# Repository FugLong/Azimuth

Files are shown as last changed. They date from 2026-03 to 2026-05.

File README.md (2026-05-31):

<div align="center">

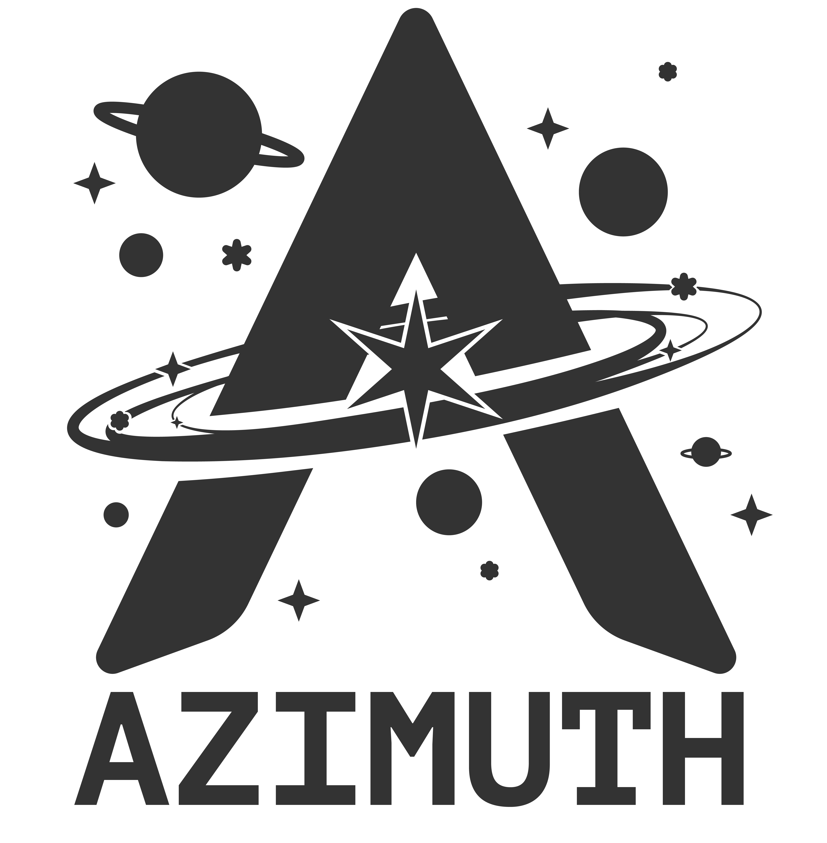
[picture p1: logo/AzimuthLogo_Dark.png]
Azimuth

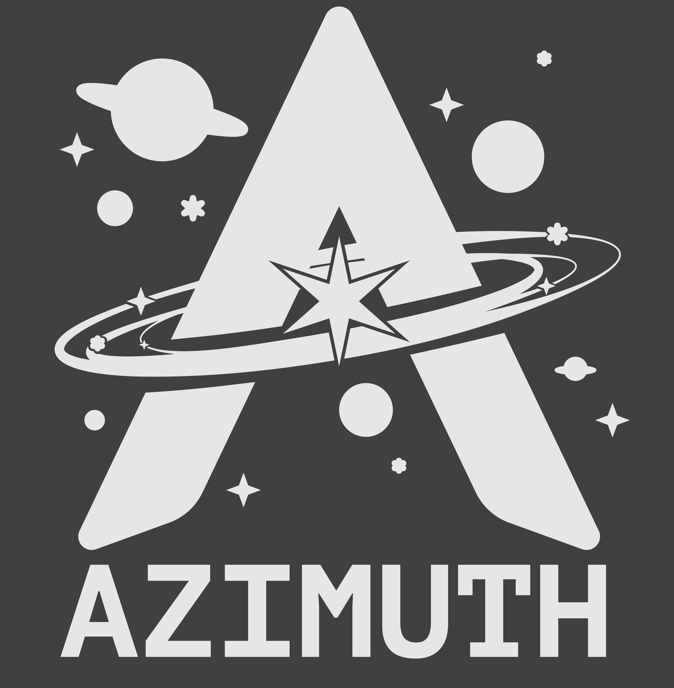
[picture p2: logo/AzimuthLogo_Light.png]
Azimuth


</div>

# Azimuth

Azimuth is a **DIY head tracker** for flight sims, racing, and anything that works with [OpenTrack](https://github.com/opentrack/opentrack). It pairs a small **ESP32** board with a **BNO08x-class** IMU so you get stable orientation without a closed commercial device. This repo has **firmware**, **PCB** designs, **3D** plans, and **documentation**—build it, change it, or fix it yourself.

### Hardware paths

Two supported builds—same core tracker firmware where both apply; use the row that matches what you assembled.

| Path | What it is | Status |
|---|---|---|
| **DIY (XIAO + BNO08x)** | **Seeed XIAO ESP32-C3** + **BNO08x** breakout on **SPI** — breadboard or hand-wired. Default **`azimuth_main_diy`**; selected by default in the [**web flasher**](https://fuglong.github.io/Azimuth/). | **Ready** — tracking, Wi‑Fi, portal, USB Hatire, OpenTrack UDP. |
| **Integrated PCB** | [**`kicad/Azimuth_Design`**](kicad/Azimuth_Design/): **ESP32-C3** module, **BNO086**, RGB, buzzer, button. **`azimuth_main_pcb`**; available in the web flasher hardware selector. | **V0.1** — KiCad **ERC/DRC** clean; **assembled boards in hand**, **bring-up and testing in progress**. Same app as DIY — [roadmap](docs/roadmap.md). |

[**docs/wiring.md**](docs/wiring.md) (pinouts) · [**docs/hardware-profiles.md**](docs/hardware-profiles.md) (PlatformIO / GPIO) · [**docs/parts-list.md**](docs/parts-list.md) (sourcing — DIY store links + PCB BOM)

---

### Get started

| | |
|:---|:---|
| **Install or update firmware (USB)** | [**Web flasher**](https://fuglong.github.io/Azimuth/) (**Chrome** / **Edge**). **First flash on a bare custom PCB?** [**Copy/paste USB guide**](docs/first-usb-flash.md) (one time; web/OTA after that). |
| **Update firmware over Wi‑Fi** | Open the portal, hit **Install over Wi‑Fi** in the **Device** card or update banner — *or* hold **FUNC** for ~2 s on the PCB. The chip pulls the latest **official** build from the same GitHub Pages release URL (HTTPS) and reboots into the standby OTA slot. See [**User Guide → Updates**](docs/user-guide.md#9-firmware-updates). |
| **Settings (Wi‑Fi, OpenTrack, device)** | [**http://azimuth.local:8080**](http://azimuth.local:8080) — only after the board is on your home network. First time? Connect to **Azimuth-Tracker** (**Offline Mode**) and follow the [**quick start**](docs/quickstart.md). |
| **Manual (how to use the device)** | [**docs/user-guide.md**](docs/user-guide.md) |
| **Short Wi‑Fi → OpenTrack path** | [**docs/quickstart.md**](docs/quickstart.md) |

---

<div align="center">
<table>
  <tr>
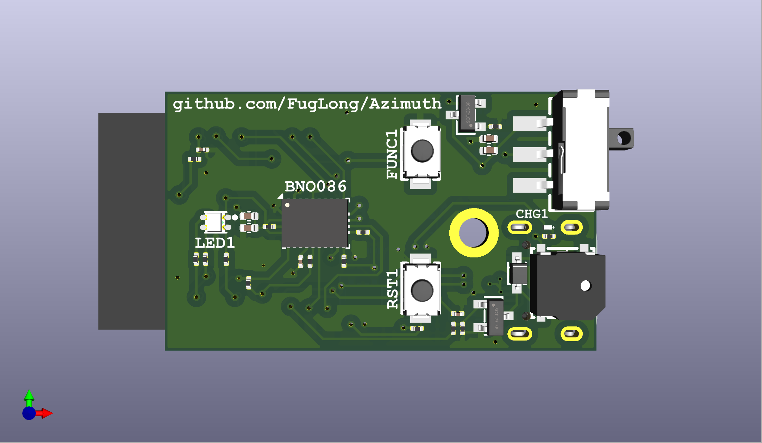
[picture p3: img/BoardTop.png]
PCB top
    <td align="center"></td>
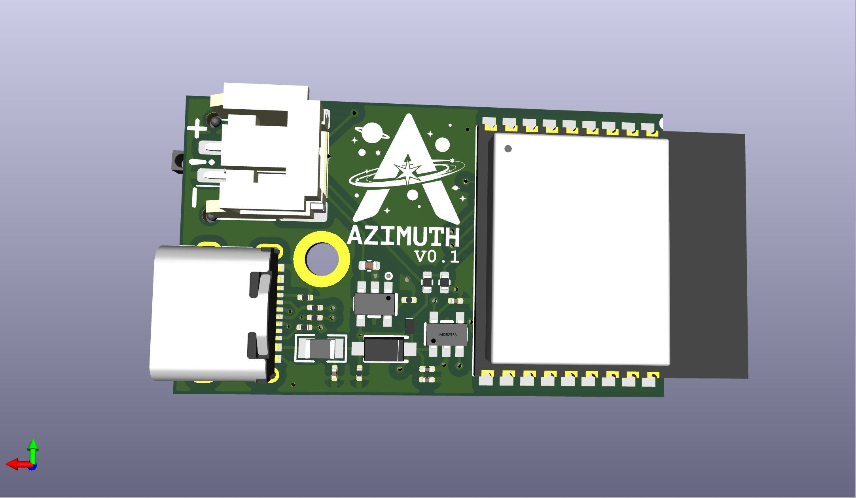
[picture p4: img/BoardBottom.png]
PCB bottom
    <td align="center"></td>
  </tr>
</table>
</div>

## Overview

- **OpenTrack-first** — Send motion over **Wi‑Fi (UDP)** or **USB (Hatire)**; configure most things in the on-device web UI.
- **Affordable, open stack** — Sensible parts list, KiCad project, and firmware you can build with [PlatformIO](https://platformio.org/).
- **No cloud** — No account or hosted service; setup and tracking stay on your network.
- **Successor** to [Nano33_PC_Head_Tracker](https://github.com/FugLong/Nano33_PC_Head_Tracker): same DIY spirit, but rebuilt around **ESP32** and an external fusion IMU for better results than the old Nano 33 BLE + LSM9DS1 path.

## Need to know

- **Flashing** — Browser install needs **Chrome** or **Edge** (Web Serial). If the installer offers **erase flash**, use it for a clean device (same effect as a full settings reset).
- **First Wi‑Fi setup** — Join **Azimuth-Tracker** (**Offline Mode**), open **`http://192.168.4.1`**, save your home network. Details: [**quick start**](docs/quickstart.md) · full walkthrough: [**User Guide**](docs/user-guide.md).
- **OpenTrack** — Use **either** UDP **or** Hatire as the input, not both at once. Defaults and axis mapping: [**Using Azimuth**](docs/using-azimuth.md#opentrack-on-the-pc).
- **Power, heat, tuning** — Normal for Wi‑Fi on a small module; portal **Tracking & radio** settings; full behavior + battery notes: [**Power, heat, and battery (firmware)**](docs/power-and-thermal.md).

## Documentation

| Doc | Audience |
|-----|---|
| [**User Guide**](docs/user-guide.md) | **Manual** — Wi‑Fi, portal, FUNC, OpenTrack, updates, battery, troubleshooting |
| [**Quick start**](docs/quickstart.md) | Fast path from flash to tracking over Wi‑Fi |
| [**Using Azimuth**](docs/using-azimuth.md) | Settings portal reference, OpenTrack (USB + Wi‑Fi), tips |
| [**Power, heat, and battery (firmware)**](docs/power-and-thermal.md) | Wi‑Fi power saving, portal polling, defaults; battery runtime / PCB pack polarity |
| [**Development**](docs/development.md) | Building firmware, CI, versioning, repo layout |
| [**Firmware architecture plan**](docs/firmware-architecture-plan.md) | Maintainers — module layout (**network split done**), CI, remaining refactors |
| [**I/O experience plan**](docs/io-led-buzzer-plan.md) | LED / buzzer / FUNC — pause/stasis, layered overrides, **wireless OTA** |
| [**Implementation handoff**](docs/implementation-handoff-prompt.md) | Copy-paste prompt + ordered tasks for agents / new contributors |
| [**Wiring**](docs/wiring.md) · [**Hardware profiles**](docs/hardware-profiles.md) · [**Parts / BOM**](docs/parts-list.md) · [**KiCad**](docs/kicad.md) | Pinouts (DIY + PCB), PlatformIO, BOM, KiCad |
| [**Roadmap**](docs/roadmap.md) | Progress, milestones, future work |
| [**Enclosure (Onshape CAD)**](https://cad.onshape.com/documents/fa78666ff0e219ba32d45d9f/w/679625cc5ba48f8e098cba83/e/0cd4f9cad8e872128d491b46) | Interactive 3D model — print/fit validation still in progress ([roadmap](docs/roadmap.md)) |

## Goals

- **Performance** — Low latency and stable orientation for games and desktop use.
- **Accessibility** — Easy-to-source parts and open tooling so people can build and modify their own trackers.
- **Interop** — First-class support for the same **OpenTrack** pipelines games and sims already use.
- **Evolvability** — Room for better calibration, on-device UX, and companion apps without legacy platform limits.

## Progress (toward V1)

| Area | Progress | Notes |
|---|:---:|---|
| Hardware / BOM | 100% | [Parts list](docs/parts-list.md) |
| Azimuth custom PCB ([`Azimuth_Design`](kicad/Azimuth_Design/)) — **V0.1** | **100%** (layout) · **units received** | Assembled boards **under test**. RGB / buzzer / FUNC in firmware for bring-up — see [wiring](docs/wiring.md) / [parts-list](docs/parts-list.md) — [roadmap](docs/roadmap.md) |
| Firmware | ~90% | Tracking + Wi‑Fi + portal + Hatire + **wireless OTA** + modular **`track_network_*`**; **battery ADC** polish and optional **`main`** layering remain — [roadmap](docs/roadmap.md) |
| 3D enclosure | ~90%+ | **Design nearly complete** — [**Onshape CAD (interactive)**](https://cad.onshape.com/documents/fa78666ff0e219ba32d45d9f/w/679625cc5ba48f8e098cba83/e/0cd4f9cad8e872128d491b46); print / fit validation still ahead |

```
Hardware/BOM   [████████████████████] 100%
PCB (V0.1)     [████████████████████] 100% design · boards received · testing
Firmware       [██████████████████░░] ~90%
Enclosure      [██████████████████░░] ~90%+ (design)
```

**Detailed roadmap:** [docs/roadmap.md](docs/roadmap.md)

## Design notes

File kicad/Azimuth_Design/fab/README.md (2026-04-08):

# Fab exports (Azimuth_Design)

## PCBWay-style “Other Parameters” (copy-paste)

| Form field | Value |
|---|---|
| **Unique Parts** | **33** |
| **SMD Parts** (tooltip *SMT Pads*) | **52** (SMD placements) **or** **234** (SMD pads in PCB — use if the estimator expects pad count) |
| **BGA/QFP Parts** | **0** |
| **Through-Hole Parts** | **0** |

**Not a contradiction:** **33** = distinct **part numbers** (unique SKUs to order). **52** = **placement count** — each symbol on the board is one placement, but many symbols share the same LCSC (many resistors/caps reuse a few codes). **234** = physical **SMD pads** on the PCB (pads per footprint), only if a form asks for pad count.

**Unique parts:** 32 distinct **LCSC Part** values on stuffed BOM lines + **IC1** (no LCSC on symbol) = **33**. **SMD placements:** **52** stuffed lines. **SMD pads:** **234** × `pad … smd …` in **`Azimuth.kicad_pcb`**. **IC1** is **LGA**, not BGA/QFP.

---

## `Azimuth_bom.csv`

Machine-generated **Bill of Materials** from **`../Azimuth.kicad_sch`** using **KiCad’s `kicad-cli sch export bom`** (same field stack the GUI BOM tool uses). The same script also writes **`Azimuth.net`** via **`kicad-cli sch export netlist`**. **Commit updates** whenever the schematic BOM-relevant fields change so docs can cite a real file instead of hand-wavy counts.

Regenerate from the repo root:

```bash
./scripts/export_azimuth_bom.sh
```

Or set `KICAD_CLI` if `kicad-cli` is not on your `PATH` (see script).

### Numbers taken from the committed CSV (for assembly forms)

These are derived from **`Azimuth_bom.csv`** as checked in — re-open the CSV after regeneration if the design changed.

| Question | Answer |
|---|---|
| BOM lines (`kicad-cli`, one row per schematic symbol) | **52** |
| Rows with `Value` = `DNP` | **0** |
| Rows for a **stuffed** build | **52** |
| Distinct **LCSC Part** codes on stuffed lines (non-empty) | **32** |
| Distinct **ordering lines** if you treat “no LCSC” as its own line (**IC1** / BNO086 has no LCSC on the symbol) | **33** |
| Through-hole **components** | **0** (all stuffed lines are SMD footprints) |
| BGA / QFP | **0** — **IC1** is **LGA** |

**PCBWay:** their KiCad plugin often writes under **`_pcbway_export_review/`** (gitignored here). If you use their CSV for an order, copy or regenerate into this **`fab/`** folder when you want those exact columns tracked in git.

## `Azimuth_bom_cost.txt`

**One-board parts-only USD estimate** (unit prices × qty). Written by **`./scripts/export_azimuth_bom.sh`** after the BOM CSV export. Uses **`Unit Price (USD)`** from the schematic when present; otherwise fills from the same LCSC/MPN table as **`scripts/update_azimuth_sch_bom_fields.py`**. **Not** live pricing, **not** PCB fab or shipping.

## `Azimuth.net` (optional)

Regenerate after schematic changes if you track a netlist export here.

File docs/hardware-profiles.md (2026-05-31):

# Hardware profiles

Azimuth is intentionally **two hardware paths**—you only build one:

1. **DIY / breadboard** — A **Seeed XIAO ESP32-C3** and a **BNO08x-class** IMU breakout wired for **SPI**. Parts are easy to source — store links and options are in [**parts-list.md**](parts-list.md). The [**web flasher**](https://fuglong.github.io/Azimuth/) supports this path and keeps it as the default choice (**`azimuth_main_diy`**). USB for flashing and **Hatire** is through the XIAO.

2. **Integrated PCB** — The routed board in [**`kicad/Azimuth_Design`**](https://github.com/FugLong/Azimuth/tree/main/kicad/Azimuth_Design) (**ESP32-C3-WROOM-02**, **BNO086** on the board, plus **RGB**, **buzzer**, and **FUNC** where populated). You flash **`azimuth_main_pcb`**. It runs the **same** head-tracking application (portal, UDP, Hatire); on-board extras are only relevant when that hardware exists.

**DIY** (XIAO + breakout) and **Azimuth_Design** share the **same** GPIO assignments in **`include/azimuth_hw.h`** — only the **physical** connector differs (XIAO **D** pins vs **U1** module pads). See [**wiring.md**](wiring.md) (DIY table ↔ PCB table).

**Build suffixes:** **`_diy`** = XIAO + breakout. **`_pcb`** = Azimuth_Design. **`main`** = full firmware (portal, Hatire, UDP). **`debug`** = USB serial IMU angles only, no Wi‑Fi or portal.

Firmware now also tags each build with a board profile (`DIY` or `PCB`) and enables features through a shared capability layer. That keeps one app codebase while cleanly gating optional hardware (RGB, buzzer, FUNC button, battery sense) per path.

---

## Targets

| Role | **`_diy`** | **`_pcb`** |
|---|---|---|
| **MCU** | XIAO ESP32-C3 | WROOM-class module on Azimuth_Design |
| **IMU** | BNO08x breakout | BNO086 on board |
| **Extra I/O** | Buzzer/button optional (same GPIOs as PCB) | RGB LED, buzzer, FUNC on board |

Capability defaults in current firmware:

| Capability | **`_diy`** | **`_pcb`** |
|---|---|---|
| RGB LED | Off (no RGB layout expected) | On |
| Buzzer | On (optional wiring) | On |
| FUNC button | On (optional wiring) | On |
| Battery sense | Stubbed in firmware for now | Stubbed in firmware for now |

On **`_pcb`**, firmware treats the RGB as **common anode** (see [**wiring.md**](wiring.md)) and applies simple **per-channel PWM scaling** from ballast **R6–R8** so logical RGB is closer to matched drive. **`_diy`** does not use the Azimuth RGB footprint; optional buzzer/button GPIOs match the PCB when wired.

**Firmware:** **`azimuth_main_diy`** and **`azimuth_main_pcb`** are the same application. Tracking does not require LED, buzzer, or button.

| You have | Environment |
|---|---|
| XIAO + BNO08x (SPI) | **`azimuth_main_diy`** or **`azimuth_debug_diy`** — `board = seeed_xiao_esp32c3` |
| Azimuth_Design PCB | **`azimuth_main_pcb`** or **`azimuth_debug_pcb`** — `board = esp32-c3-devkitc-02` |

```bash
python3 -m platformio run -e azimuth_main_diy -t upload    # XIAO + breakout
python3 -m platformio run -e azimuth_main_pcb -t upload    # Azimuth_Design
```

Firmware sets **`-DARDUINO_USB_MODE=1`** and **`-DARDUINO_USB_CDC_ON_BOOT=1`** so **`Serial`** is USB CDC on both targets; the stock **`esp32-c3-devkitc-02`** JSON does not enable that by itself.

**SPI bus:** **`src/main.cpp`** calls **`SPI.begin(8, 9, 10, -1)`** before **`imu.beginSPI(...)`**. The XIAO variant already defaults to those pins, but **`esp32-c3-devkitc-02`** uses Arduino variant **`esp32c3`**, whose defaults are **4 / 5 / 6** — that would collide with **CS (5)** and **INT (6)** on the Azimuth PCB. The explicit **`begin`** keeps DIY and PCB builds on the same **FSPI** pins as **`Azimuth.kicad_sch`**.

**Web flasher:** CI publishes both **`azimuth_main_diy`** and **`azimuth_main_pcb`** with a hardware selector in the installer UI. DIY remains the default selection.

**First flash on a bare custom PCB (no firmware from the factory):** the module boot-loops; the browser [**web flasher**](https://fuglong.github.io/Azimuth/) is unreliable for that one-time case. Use [**first-usb-flash.md**](first-usb-flash.md), then web or OTA for updates afterward.

---

## GPIO contract (change only with firmware + doc update)

Firmware-facing summary: same GPIO numbers on both paths. **Where to wire physically** — XIAO **D** pins vs **U1** schematic pins — is in [**wiring.md**](wiring.md) (DIY section vs PCB section), not duplicated here.

GPIO numbers are for ESP32-C3; **D*** labels refer to XIAO silk only (the module has no **D** names).

| Function | GPIO | XIAO | Notes |
|---|---|---|---|
| SPI SCK / MISO / MOSI | 8 / 9 / 10 | D8–D10 | |
| IMU CS / INT / NRST | 5 / 6 / 20 | D3, D4, D7 | |
| PS0 / WAKE | 2 | D0 | **10 kΩ** to **3V3** on breadboard (same as **R14** on **Azimuth_Design**) |
| RGB (Azimuth board) | 0, 1, 3 | — | Not present on default breadboard build; **R→IO1, G→IO0, B→IO3** — [wiring.md](wiring.md) |
| Status / future | 3 | D1 | **`kPinStatusLed`**; shares **IO3** with RGB blue on PCB — [wiring.md](wiring.md) |
| FUNC | 7 | D5 | Optional breadboard |
| Buzzer | 21 | D6 | PWM on **IO21** drives **Q2** gate on PCB; optional breadboard differs — [wiring.md](wiring.md), [parts-list](parts-list.md#buzzer-buzzer1) |
| Battery sense | 4 | D2 | Divider tap; when populated — same as **Azimuth_Design** **IO4** |

The Azimuth RGB LED is on **GPIO 0, 1, 3**—not a drop-in on XIAO silk; **`azimuth_main_diy`** does not drive that RGB layout.

If a hardware revision ever changes GPIO roles, update **`azimuth_hw.h`** and [wiring.md](wiring.md) together.

**KiCad:** **`kicad/Azimuth_Design/`** — open **`Azimuth.kicad_pro`**. **U1** ↔ **IC1** routing and module notes are in [wiring.md](wiring.md) (**PCB path**). Project snapshot is **ERC/DRC clean**; re-run after schematic or layout edits. Libraries, optional panelization, workflow: [kicad.md](kicad.md).

---

## Work checklist (maintenance)

- [x] Shared pin header **`include/azimuth_hw.h`**
- [x] PlatformIO **`azimuth_main_diy`** / **`azimuth_main_pcb`** (+ debug variants)
- [x] **Azimuth_Design**: Docs [**parts-list.md**](parts-list.md) / [**wiring.md**](wiring.md) match **`Azimuth.kicad_sch`** / **`Azimuth.kicad_pcb`** (re-verify after edits); **ERC/DRC clean** in current repo snapshot; export BOM from KiCad for each fab / pick-and-place order
- [x] CI build **`azimuth_main_pcb`** artifacts
- [x] Web flasher hardware selector (DIY + PCB manifests)

**Related:** [wiring.md](wiring.md) · [parts-list.md](parts-list.md) · [development.md](development.md) · [kicad.md](kicad.md)

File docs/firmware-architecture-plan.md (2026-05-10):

# Firmware architecture — review and improvement plan

This document captures how Azimuth firmware is structured today, what is working well, where complexity concentrates, and a **phased plan** for refactors so the codebase stays maintainable as features grow (especially richer I/O and networking).

It is a planning artifact: implement in small PR-sized steps rather than as one large rewrite. **As of 2026‑05:** core networking has been split into multiple translation units (Phase B done); remaining items skew toward **battery ADC polish**, **main.cpp decomposition**, and optional **portal asset pipeline** improvements.

---

## Current strengths

- **Bounded real-time path.** `main.cpp` owns IMU sampling and pose output; networking is invoked from `trackNetworkLoop()` and stays out of the hottest path except where intentional (UDP send immediately after rotation-vector reports).
- **Build dimensions are explicit.** `IMU_DEBUG_MODE` separates a bare serial build from full firmware. PlatformIO environments distinguish DIY vs PCB (`AZIMUTH_BOARD_*`) so hardware differences stay mostly in `board_config` / `azimuth_hw`.
- **Subsystem boundaries.** Battery, thermal, LED, buzzer, button, and network each live in dedicated translation units with namespaces (`azimuth_battery`, `azimuth_thermal`, `azimuth_io_*`, etc.).
- **Thin API toward the loop.** `track_network.h` exposes a small surface (`trackNetworkInit`, `Loop`, UDP send, prefs accessors, thermal emergency hook). Implementation is split across `track_network_{wifi,http,prefs,udp}.cpp` plus shared `track_network_internal.h`; `track_network.cpp` holds the façade and global runtime object.
- **Shipping discipline.** CI builds release artifacts; `secrets.h.example` covers optional compile-time Wi‑Fi without committing secrets; docs (`docs/development.md`, wiring, thermal) match how people actually flash and configure hardware.

---

## Pressure points (technical debt)

### 1. ~~`track_network.cpp` monolith~~ → split complete

Previously one large file mixed Wi‑Fi STA/AP, captive DNS, HTTP routes, NVS, OpenTrack, UDP, and update checks.

**Now:** Logical slices live in dedicated files behind the same public API:

| File | Role |
|---|---|
| `track_network.cpp` | Public wrappers; `NetworkRuntime` / `gRuntime` definition |
| `track_network_internal.h` | Shared structs, prefs/network helpers, declarations |
| `track_network_wifi.cpp` | STA/AP bring-up, `networkLoop`, thermal cut, offline portal, manifest scheduling |
| `track_network_http.cpp` | HTTP handlers, JSON API, TLS manifest fetch, `registerRoutes` |
| `track_network_prefs.cpp` | NVS merge helpers, adaptive modem sleep, stasis |
| `track_network_udp.cpp` | Host resolution, UDP socket, OpenTrack send |

### 2. Embedded portal asset (`portal_html.cpp`)

The portal is a large HTML/CSS/JS blob in PROGMEM. That is normal for a single-binary deliverable, but diffs are noisy and editing error-prone.

**Optional later improvement:** Build-time concatenation or minification from `portal/` fragments (`scripts/portal_codegen.py` already regenerates from `web/`). Not urgent until portal churn grows.

### 3. CI breadth

GitLab CI builds **`azimuth_main_diy`** (artifacts), **`azimuth_main_pcb`** (compile), **`azimuth_debug_diy`**, and runs **`scripts/run_host_tests.sh`**. Debug PCB env can still be built locally if needed.

### 4. Automated verification

**Host-side tests:** `scripts/run_host_tests.sh` compiles and runs native harnesses for config validation, config planning (Wi‑Fi / OpenTrack apply rules), and semver parsing (`tests/*.cpp`). Outputs land under `.tmp-host-tests/` (ignored by git).

**Recommendation:** When adding pure logic (e.g. more helpers split from networking), extend those harnesses or add a small new test file rather than relying on hardware-only checks.

### 5. `main.cpp` battery threshold ladder

Multiple similar latch variables work but are repetitive; a **table-driven** approach (threshold + severity + callback id) would shrink duplication and reduce mistakes when tuning percentages.

---

## Phased refactor roadmap

Phases are intentionally ordered by **risk vs payoff**. Structural network split is **complete**.

### Phase A — Guardrails (low risk)

1. **CI:** ✅ Builds **DIY + PCB** main and debug targets plus host tests on pipeline runs.
2. **Documentation:** Keep `docs/development.md` pointed at this file or a short “architecture” index.

### Phase B — Structural splits (medium risk, high readability)

1. ✅ Split networking along Wi‑Fi / HTTP / prefs / UDP slices; **preserve public `track_network.h` API**.
2. Optionally introduce a tiny **`network_prefs`** or **`settings_store`** module if NVS access spreads further — partially satisfied by `track_network_prefs.cpp`.

### Phase C — Quality-of-life (ongoing)

1. Table-driven battery alerts in `main.cpp` (or `battery_monitor` policy module).
2. Optional portal asset pipeline when editing HTML becomes painful.

---

## Cross-cutting product behaviors (see I/O plan)

- **Pause / stasis (FUNC single tap):** Runtime gate for UDP (and Hatire) separate from NVS `udp_on`, plus power-policy hooks (modem sleep in stasis). Implemented via `trackNetworkSetStasis` / `trackNetworkStasisActive`.
- **Wireless OTA *(shipped)*:** **`src/track_update.{h,cpp}`** (IMU debug builds get stubs). Uses the **default partition table's existing `ota_0` / `ota_1` / `otadata`** slots. Driven by `io_button` long-press *and* `POST /api/update`; cooperative chunk pump runs from `networkLoop`. TLS root pin is shared with the manifest check via `azimuth_net::releaseRootCaCert()`. USB flashing and the per-boot manifest version banner remain recovery and discovery fallbacks.

---

## Principles for future changes

- **Prefer extension over explosion.** New transports or APIs should attach via clear interfaces rather than growing anonymous globals.
- **Keep latency-sensitive code dumb.** Pose → USB/UDP should stay predictable; heavy work stays in `networkLoop` / lower priority paths with `yield()` where needed.
- **One source of truth for user-visible defaults.** NVS keys and portal defaults should stay aligned (already a discipline in config POST handlers).

---

## Non-goals (for this architecture track)

- Rewriting the Arduino/Wi‑Fi stack or replacing JSON with another format without user-facing need.
- Mandating a full RTOS migration; the current cooperative loop matches the product.

---

## Related documents

- **I/O and UX plan (LED, buzzer, FUNC, pause, OTA roadmap):** [io-led-buzzer-plan.md](io-led-buzzer-plan.md)
- **Implementation handoff (ordered tasks for agents):** [implementation-handoff-prompt.md](implementation-handoff-prompt.md)
- **Development workflow:** [development.md](development.md)

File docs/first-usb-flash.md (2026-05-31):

# First-time USB flash (copy & paste)

Use this guide when you need to put Azimuth firmware on the board over **USB** using our flash script.

**You need this if:** your **custom Azimuth PCB** came from assembly with **no firmware** (the web browser flasher usually will not work until after this one-time flash). You can also use it for **DIY (XIAO + breakout)** anytime.

**After this works once:** use the normal [**web flasher**](https://fuglong.github.io/Azimuth/) or **Wi‑Fi updates** in the portal — you do not need this script every time.

---

## Before you start

Check all of these:

| | |
|---|---|
| ☐ | **Data USB cable** (charges phones *and* transfers data — not charge-only) |
| ☐ | **Computer** (Mac or Windows; Linux works too — same commands as Mac) |
| ☐ | **Python 3** installed ([python.org/downloads](https://www.python.org/downloads/) — on Windows, check **“Add python to PATH”**) |
| ☐ | You know which board you have (see next section) |

Plug the board into the computer with USB **before** you run the flash command (or plug in when the script asks you to pick a port).

---

## Step 1 — Which board do you have?

Pick **one** path below. Do not run both commands.

| Your hardware | Use this path |
|---|---|
| **Azimuth custom PCB** (the integrated Azimuth board from the kit/PCB) | [**Custom PCB**](#step-2-flash-custom-pcb) |
| **DIY** — Seeed **XIAO ESP32-C3** + BNO08x breakout on a breadboard | [**DIY XIAO**](#step-2-flash-diy-xiao--bno08x) |

---

## Step 2 — Flash

### Mac or Linux

1. Open **Terminal**  
   - Mac: Spotlight (⌘ Space) → type `Terminal` → Enter  
2. **Copy** the whole block for your board (one click in the box, ⌘C / Ctrl+C).  
3. **Paste** into Terminal (⌘V / Ctrl+V) and press **Enter**.  
4. Wait. First run may install a small tool (`esptool`) — that is normal.  
5. When it says **Flash complete**, you are done. Unplug and plug USB once if the board does not reboot on its own.

#### Flash — Custom PCB

```bash
curl -fsSL https://raw.githubusercontent.com/FugLong/Azimuth/main/scripts/azimuth-flash.sh | bash
```

#### Flash — DIY (XIAO + BNO08x)

```bash
curl -fsSL https://raw.githubusercontent.com/FugLong/Azimuth/main/scripts/azimuth-flash.sh | bash -s diy
```

---

### Windows

1. Install **Python 3** from [python.org/downloads](https://www.python.org/downloads/) if you do not have it.  
   - On the installer screen, turn on **“Add python.exe to PATH”**, then **Install Now**.  
2. Open **PowerShell**  
   - Start menu → type `PowerShell` → **Windows PowerShell**  
3. Plug in the board with a **data** USB cable.  
4. **Copy** the block for your board, **paste** into PowerShell, press **Enter**.  
5. Wait until you see **Flash complete**.

#### Flash — Custom PCB

```powershell
curl.exe -fsSL https://raw.githubusercontent.com/FugLong/Azimuth/main/scripts/azimuth-flash.py -o azimuth-flash.py
python azimuth-flash.py pcb
```

#### Flash — DIY (XIAO + BNO08x)

```powershell
curl.exe -fsSL https://raw.githubusercontent.com/FugLong/Azimuth/main/scripts/azimuth-flash.py -o azimuth-flash.py
python azimuth-flash.py diy
```

If Windows says it cannot find the USB port, open **Device Manager** → **Ports (COM & LPT)** → note something like **COM3**, then run (change `COM3` if yours is different):

```powershell
python azimuth-flash.py pcb --port COM3
```

(or `diy` instead of `pcb` for the XIAO build)

---

## Step 3 — What you should see

While it runs, the window will show things like:

- `Downloading…` / `Firmware 0.x.x ready`  
- `Using port …` (or it asks you to pick `[1]` / `[2]` if several USB devices are plugged in)  
- `Erasing flash…`  
- `Writing firmware…`  
- **`Flash complete`**

Then:

1. Power the board (USB is fine).  
2. On your phone or PC Wi‑Fi list, look for **`Azimuth-Tracker`**.  
3. Connect and open **http://192.168.4.1** to enter your home Wi‑Fi.  
4. Full setup: [**quick start**](quickstart.md) · [**user guide**](user-guide.md)

---

## Stuck?

### `python3: command not found` (Mac)

Install Python from [python.org/downloads](https://www.python.org/downloads/), then try the command again.

### `python is not recognized` (Windows)

Re-run the Python installer and enable **Add to PATH**, or use `py` instead of `python`:

```powershell
py azimuth-flash.py pcb
```

### No serial port / flash failed / keeps retrying “bootloader”

**Custom PCB:** press **RST** once, then run the flash command again **right away**.

**DIY XIAO:** hold the **BOOT** button, tap **RST**, release **RST**, keep holding **BOOT**, run the command again.

Also try: different USB cable, different USB port, unplug other serial devices, run the command again right after plugging in.

### Several USB devices — which one?

Run with “ask me” (Mac/Linux, from a cloned repo only):

```bash
./scripts/azimuth-flash.sh --ask
```

Or on Windows, list ports in Device Manager and use `--port COMx` as shown above.

### I already have the Azimuth repo on my computer

Open Terminal in the repo folder and run:

```bash
./scripts/azimuth-flash.sh          # custom PCB
./scripts/azimuth-flash.sh diy      # XIAO DIY
```

---

## Technical notes (optional)

- Downloads the same official firmware as [fuglong.github.io/Azimuth](https://fuglong.github.io/Azimuth/).  
- Caches files under `~/.cache/azimuth-flash/` (Mac/Linux).  
- Developers building their own firmware: `./scripts/flash.sh` in the repo.

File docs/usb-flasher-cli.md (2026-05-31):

# USB flash script

**Step-by-step copy/paste guide:** [**first-usb-flash.md**](first-usb-flash.md)

That page covers **custom PCB** and **DIY (XIAO)** first-time flashing over USB. Use it for bare PCBs from assembly; use the [**web flasher**](https://fuglong.github.io/Azimuth/) or **OTA** after the first successful flash.

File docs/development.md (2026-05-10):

# Development

Build flags, **PlatformIO** environments, **CI**, and how the firmware repo is laid out. End-user setup and OpenTrack: [**user-guide.md**](user-guide.md), [**using-azimuth.md**](using-azimuth.md), [**quickstart.md**](quickstart.md).

## Requirements

- [PlatformIO](https://platformio.org/) (CLI or IDE)
- **`include/secrets.h`** — copy from **`include/secrets.h.example`** (file is gitignored). Can stay empty; optional compile-time Wi‑Fi / OpenTrack defaults when NVS has no SSID.

**Hardware profiles:** Same source, different **`board`** in PlatformIO — see **[hardware-profiles.md](hardware-profiles.md)**.

| Environment | Target |
|---|---|
| **`azimuth_main_diy`**, **`azimuth_debug_diy`** | XIAO + BNO08x breakout |
| **`azimuth_main_pcb`**, **`azimuth_debug_pcb`** | Azimuth_Design PCB ([**`Azimuth_Design`**](../kicad/Azimuth_Design/)), **`esp32-c3-devkitc-02`** |

**Default release:** **`azimuth_main_diy`**. **`azimuth_debug_*`**: USB serial IMU angles only, no Wi‑Fi or portal. Full matrix: [**hardware-profiles.md**](hardware-profiles.md).

## Build and upload

**One-liner** (from repo root; defaults to **`azimuth_main_pcb`**, auto-picks a USB serial port; use `diy` for XIAO or pass a port as the second argument):

```bash
./scripts/flash.sh              # PCB
./scripts/flash.sh diy          # DIY
./scripts/flash.sh pcb --ask    # pick port if several devices
```

The script uses **`pio`** when it is on your **`PATH`**, otherwise **`python3 -m platformio`**.

**Debug (serial monitor, IMU angles):**

```bash
python3 -m platformio run -e azimuth_debug_diy -t upload
python3 -m platformio device monitor
```

**Main firmware (Hatire + optional UDP / portal):**

```bash
python3 -m platformio run -e azimuth_main_diy -t upload
```

**Azimuth_Design PCB:**

```bash
python3 -m platformio run -e azimuth_main_pcb -t upload
```

**Local web flasher bundle** (copy binaries into **`web-flasher/firmware/{diy,pcb}/`** for testing GitHub Pages–style install):

```bash
pio run -e azimuth_main_diy
pio run -e azimuth_main_pcb
./scripts/prepare_web_flasher_firmware.sh azimuth_main_diy web-flasher/firmware/diy
./scripts/prepare_web_flasher_firmware.sh azimuth_main_pcb web-flasher/firmware/pcb
```

## Firmware version and release URLs

- **Source of truth:** repo root **`VERSION`** (first line = semver, e.g. `0.2.0`).
- **`scripts/pio_set_version.py`** injects it as **`AZIMUTH_FW_VERSION`** into **`azimuth_main_diy`** / **`azimuth_main_pcb`** builds.
- **`web-flasher/manifest.json`** and **`web-flasher/manifest-pcb.json`** fields **`version`** are synced by **`scripts/sync_manifest_version.py`** (via **`prepare_web_flasher_firmware.sh`** and the GitHub Pages workflow) so the USB installer and running firmware agree.
- **Intended scheme:** align with board generations—e.g. board **0.2** ships **0.2.0**, then patch bumps until a **1.0** board ships **1.0.0**, etc.
- **Update hint on device:** After STA is up, firmware fetches the published **`manifest.json`** (with retry/backoff; default URL in **`platformio.ini`**). If the hosted **`version`** is newer (numeric semver), the portal shows a banner. **Installing** the new build is **manual**: **USB flasher** and/or **wireless OTA** (portal **Install over Wi‑Fi** / FUNC long-press) when conditions allow — see [**user-guide.md**](user-guide.md). Forks can override **`AZIMUTH_RELEASE_MANIFEST_URL`** / **`AZIMUTH_RELEASE_FLASHER_URL`**. The manifest HTTPS fetch validates TLS against a pinned root CA (with optional **`AZIMUTH_RELEASE_MANIFEST_CA_CERT`** override).
- **esp-web-tools / Improv:** The web installer can show live firmware info when the device implements **Improv Serial** and a non-zero **`new_install_improv_wait_time`**. Azimuth does **not** implement Improv yet (**wait time 0**), so the page does not auto-compare the connected board to the hosted build—use the portal **Device** line and the update banner on Wi‑Fi.

## CI and browser flasher

| What | Where |
|---|---|
| **GitLab pipeline** | Pushes to **`main`** run **`.gitlab-ci.yml`**: builds **`azimuth_main_diy`** (web-flasher artifacts), compiles **`azimuth_debug_diy`** + **`azimuth_main_pcb`**, and runs host-side C++ tests via `scripts/run_host_tests.sh` (config validation, config apply planning, semver parsing). **`secrets.h`** is copied from the example for firmware jobs. |
| **GitHub Pages USB flasher** | **`.github/workflows/github-pages-flasher.yml`** builds **`azimuth_main_diy`** + **`azimuth_main_pcb`**, runs **`prepare_web_flasher_firmware.sh`** for both targets, syncs **`manifest.json`** + **`manifest-pcb.json`**, deploys **`web-flasher/`** with [esp-web-tools](https://github.com/esphome/esp-web-tools). Repo: **Settings → Pages → Source: GitHub Actions**; environment **`azimuth-flasher`**. |

Default published URLs (see **`platformio.ini`**): manifest **`https://fuglong.github.io/Azimuth/manifest.json`**, flasher **`https://fuglong.github.io/Azimuth/`**.

## Hardware pins (this revision)

Constants live in **`include/azimuth_hw.h`**. SPI map, straps, power, and optional I/O: [**wiring.md**](wiring.md). GPIO contract and PlatformIO targets: [**hardware-profiles.md**](hardware-profiles.md).

**`src/main.cpp`** always calls **`SPI.begin(8, 9, 10, -1)`** (via **`azimuth_hw`**) before **`imu.beginSPI(...)`** because the SparkFun driver’s **`beginSPI`** invokes **`SPI.begin()`** with no pin list. The XIAO variant already defaults to **8/9/10**, but **`esp32-c3-devkitc-02`** (Azimuth PCB profile) defaults to **4/5/6**, which would clash with **CS/INT** on **5/6** and break the IMU.

## Repository layout (firmware)

| Path | Role |
|---|---|
| **`src/main.cpp`** | IMU bring-up, rotation vector, Hatire + optional OpenTrack UDP; pins from **`include/azimuth_hw.h`** ([**wiring.md**](wiring.md)). |
| **`include/opentrack_pose.h`** | Fusion Euler → Hatire / UDP **Rot 0–2** with NVS axis map + per-slot invert. |
| **`src/track_network.cpp`** | Public API façade + `NetworkRuntime` / **`gRuntime`** (`azimuth_main_*`); stubs in **`azimuth_debug_*`**. |
| **`src/track_network_internal.h`** | Shared networking declarations (prefs helpers, routes, UDP hooks). |
| **`src/track_network_wifi.cpp`** | STA/AP, **`networkLoop`**, thermal emergency, offline portal, firmware-update check scheduling. |
| **`src/track_network_http.cpp`** | HTTP routes, `/api/*` JSON, captive portal redirects, HTTPS manifest fetch. |
| **`src/track_network_prefs.cpp`** | NVS merge/read helpers, adaptive modem sleep, stasis. |
| **`src/track_network_udp.cpp`** | OpenTrack host resolution, UDP socket, **`sendOpentrackUdp`**. |
| **`src/io_led_policy.cpp`** | LED priority: thermal, battery, setup AP, pause, then ambient (`azimuth_main_*`). |
| **`src/portal_html.cpp`** | Settings UI in PROGMEM (**`azimuth_main_*`** only; filtered out of debug build). |
| **`platformio.ini`** | `espressif32`; **`azimuth_main_diy`** / **`azimuth_main_pcb`** (see [**hardware-profiles.md**](hardware-profiles.md)); SparkFun **BNO08x**; **`azimuth_main_*`** adds version script, **ArduinoJson**, default release URLs. |
| **`VERSION`** | Semver line for **`azimuth_main_*`**, **`web-flasher/manifest.json`**, and **`web-flasher/manifest-pcb.json`**. |
| **`web-flasher/`** | Static USB installer + manifest for GitHub Pages. |

Planned work (board I/O, battery, enclosure, OTA, etc.) is tracked in [**roadmap.md**](roadmap.md). **Architecture / refactor strategy:** [**firmware-architecture-plan.md**](firmware-architecture-plan.md). **I/O, pause/stasis, future OTA:** [**io-led-buzzer-plan.md**](io-led-buzzer-plan.md). **Ordered implementation prompt for agents:** [**implementation-handoff-prompt.md**](implementation-handoff-prompt.md).

## Portal source/codegen workflow

Portal firmware content is embedded in **`src/portal_html.cpp`**, but source-first editing is supported via:

```bash
python3 scripts/portal_codegen.py --generate  # regenerate src/portal_html.cpp from web/index.html
```

`web/index.html` is the source entry point and references `web/styles.css` + `web/app/*`.

**Portal logo (header):** Pick one workflow — **`AzimuthLogo_Dark.png`** / **`AzimuthLogo_Light.png`** are the usual raster masters (also copied to **`web-flasher/logo/`** by GitHub Pages).

| Goal | Command |
|---|---|
| **Pixel-perfect (recommended if “white gap” is painted, not a vector hole)** | [`scripts/portal_logo_embed_png.py`](../scripts/portal_logo_embed_png.py) inlines the PNG as a base64 `<img>` — no vectorization. |
| **Vector from PNG** (smaller flash, editable paths; loses subtle raster detail) | Prefer **`--key-white`** so painted white / transparency trace as **background**, dark ink only: `python3 scripts/logo_png_to_svg.py --key-white --white-threshold 248` (needs **`vtracer`** / `./scripts/run_logo_trace.sh -- --key-white`). Then `python3 scripts/minify_portal_logo.py logo/AzimuthLogo_traced.svg --patch-web` |
| **Illustrator SVG** | `python3 scripts/minify_portal_logo.py --patch-web` (default **`logo/AzimuthLogo.svg`** if present) |
| **DXF geometry only** | `.venv/bin/python scripts/dxf_simple_to_portal_svg.py --patch-portal` |

Always finish with **`python3 scripts/portal_codegen.py --generate`**.

**PNG → DWG:** this repo does **not** convert raster → DWG. Use **CAD** (import/trace PNG, then Save As DXF/DWG). For the **website**, use PNG embed or traced SVG — not DWG.

**`minify_portal_logo.py`** maps **`#333` → `currentColor`**, fixes Illustrator **`px`** strokes/fonts to **user units**, keeps **4** decimal places on floats, and bumps ultra-thin hairline strokes slightly so they survive minification.

---

**Related:** [README](../README.md) · [using-azimuth.md](using-azimuth.md) · [quickstart.md](quickstart.md)

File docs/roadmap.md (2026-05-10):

# Azimuth — roadmap & progress (toward V1)

This document tracks **estimated** progress and planned work toward a **V1** release: stable hardware, enclosure, and firmware that meets the goals in the main README. Percentages are manual snapshots—update them when milestones land.

---

## Snapshot (workstreams)

| Workstream | Progress | Notes |
|---|---|---|
| Hardware selection | **100%** | DIY: **XIAO ESP32-C3** + **BNO08x**; product: **Azimuth** PCB ([**Azimuth_Design**](../kicad/Azimuth_Design/)) |
| Custom PCB — **V0.1** | **100%** (design) · **assembled units received** | **Azimuth_Design**: layout + nets per [wiring.md](wiring.md); **ERC and DRC clean**. **V0.1** fab complete; **boards in hand**; **bring-up / testing in progress**. **Panelization** still optional for future arrays. |
| Firmware | **~90%** | **`azimuth_main_*`**: Hatire + Wi‑Fi UDP, **NVS** portal, **Offline Mode AP**, power/thermal, **pause/stasis**, **wireless OTA**, modular networking (`track_network_*.cpp`), LED policy + portal. Polish: **battery ADC** refinement, optional **`main.cpp`** split, NVS schema versioning (Phase 3). |
| 3D enclosure | **~90%+** | **Design nearly complete** — [**Onshape document**](https://cad.onshape.com/documents/fa78666ff0e219ba32d45d9f/w/679625cc5ba48f8e098cba83/e/0cd4f9cad8e872128d491b46) (interactive CAD); print / fit validation still ahead |
| End-user docs & release | **~85%** | **[user-guide.md](user-guide.md)** (manual) + **[quickstart.md](quickstart.md)** + **[using-azimuth.md](using-azimuth.md)**; **`VERSION`** / USB flasher / portal / OTA documented; enclosure assembly + field troubleshooting still thin |

**Visual (rough):**

```
Hardware/BOM     [████████████████████] 100%
PCB design       [████████████████████] 100%  (V0.1 · boards received · testing)
Firmware         [██████████████████░░] ~90%
Enclosure        [██████████████████░░] ~90%+ (design)
```

---

## V1 product posture

**Wireless is a V1 requirement** — The tracker is meant to run untethered with a battery; **WiFi → UDP (OpenTrack)** is implemented in firmware for LAN use; **USB stays supported** for desk use, flashing, serial debug, and **Hatire** as an alternative input path.

**Enclosure** — Default plan is **one enclosure** sized for the **battery** build (internal volume for cell + PH connector clearance). **CAD:** [Onshape — Azimuth enclosure](https://cad.onshape.com/documents/fa78666ff0e219ba32d45d9f/w/679625cc5ba48f8e098cba83/e/0cd4f9cad8e872128d491b46) (open in a browser for the live viewer). A **second, slimmer** enclosure for **wired-only** builds is possible if there is demand: same PCB, but without a battery installed and ideally without the tall **JST PH2.0** connector populated (see assembly note below).

---

## V1 — what “done” means (draft)

Use this as a checklist; tighten or relax before tagging V1.

- [x] **PCB (KiCad)** — **Azimuth_Design** fabrication-ready: **ERC and DRC clean**; BOM matches schematic/layout (re-export from KiCad for each order — [parts-list.md](parts-list.md), [kicad.md](kicad.md)).
- [x] **PCB (V0.1 manufacturing)** — **V0.1** design locked; fab **complete**; **assembled boards received** (2026-05).
- [ ] **PCB (bring-up)** — **In progress:** validate IMU, USB serial, Hatire, and Wi‑Fi/UDP on **production** boards (breadboard path already exercised).
- [x] **Firmware core (tracking + wireless)** — Networking split into `track_network_*.cpp`; pins and features match [wiring.md](wiring.md). Optional: further `imu/` / `platform/` layering ([Phase 1](#phase-1--io-architecture-power) table).
- [ ] **I/O** — Status LED, **FUNC1** button, buzzer as on PCB; debouncing and **product** behavior documented (bring-up demos exist in firmware).
- [x] **Battery** — Voltage readout + curve-based **%** estimate (`battery_monitor`); portal capacity / cal offset; stepped alerts (~25% downward); **≤1%** emergency cues + Wi‑Fi cut; **≤15%** blocks wireless OTA off-charger; FUNC pause toggle suppressed **≤1%** — documented in **[user-guide.md](user-guide.md)**. Residual: ADC tuning / “bench your pack” refinement.
- [x] **Wireless (MVP)** — WiFi STA + OpenTrack **UDP over network** working (credentials via **NVS portal** and optional **`secrets.h`**).
- [x] **Wireless (product)** — On-device settings: **HTTP UI** + **NVS** (`Preferences`), `secrets.h` fallback, provisioning AP + captive portal when SSID missing or STA fails ([README](../README.md), [using-azimuth.md](using-azimuth.md)). Still open: **richer reconnection** / backoff policy, schema **versioning** (see Phase 3).
- [x] **Updates (USB)** — GitHub Pages **esp-web-tools** flasher + repo **`VERSION`** / **`manifest.json`**; portal banner compares to hosted manifest.
- [x] **Updates (OTA)** — **`track_update`** streams `firmware/<board>/firmware.bin` from the same trusted GitHub Pages release (Let's Encrypt root pinned) into the standby `ota_0`/`ota_1` slot via the Arduino `Update` class, then reboots into it. Triggered by **FUNC long-press (~2 s)** or the portal **“Install over Wi‑Fi”** button (banner + Device card). Refuses to start in Offline‑Mode AP, during thermal hold, or with battery ≤15 % off‑charger; USB flasher remains recovery.
- [ ] **Enclosure** — At least the **battery** reference enclosure; optional second slim shell documented if wired-only variant is offered. **CAD:** [Onshape document](https://cad.onshape.com/documents/fa78666ff0e219ba32d45d9f/w/679625cc5ba48f8e098cba83/e/0cd4f9cad8e872128d491b46). **Design ~90%+ complete** (2026-05); verify fit & manufacturing next.
- [x] **User-facing docs (baseline)** — **[user-guide.md](user-guide.md)** manual + existing guides; deeper troubleshooting + enclosure still expanding.

---

## Phase 1 — I/O, architecture, power

**Goal:** Firmware matches the board: modular structure, all GPIO roles implemented, battery monitoring.

| Task | Status |
|---|---|
| Pin map / config header (single source of truth vs [wiring.md](wiring.md)) | In progress: **`include/azimuth_hw.h`** + [hardware-profiles.md](hardware-profiles.md); add alternate defines only if a PCB GPIO map diverges |
| LED: patterns for status, **stasis (pause)**, setup, battery, thermal | 🟩 **`io_led_policy`** + NVS **`led_mode`** · thermal/battery/setup/stasis layered |
| Buttons: **FUNC = pause/stasis** (UDP off + low power + cues); long-press **OTA** | 🟩 single-tap pause · double reserved · long-hold (~2 s) triggers Wi‑Fi OTA |
| Buzzer: tones for feedback (optional minimal set for V1) | 🟨 (FUNC chime on PCB; wider set ⬜) |
| ADC: battery voltage, calibration constants, filtering | 🟩 implemented · calibration polish optional |
| Power / charging behavior documented (what XIAO handles vs firmware) | ⬜ |
| Refactor `main.cpp` into layers (e.g. `imu/`, `io/`, `platform/`) without changing behavior | ⬜ |

---

## Phase 2 — WiFi + tracking path

**Goal:** Primary use case is **untethered / battery** operation: a stable wireless path for orientation to a host. **USB Hatire** remains supported in parallel.

| Task | Status |
|---|---|
| WiFi STA | ✅ (UDP client to PC; credentials via NVS + `include/secrets.h`) |
| WiFi AP / onboarding portal | ✅ (`Azimuth-Tracker` Offline Mode AP, captive DNS + HTTP :80; recovery if STA fails) |
| Transport: OpenTrack **UDP** (6× `double`, default port 4242) | ✅ |
| Semantics aligned with Hatire (yaw / pitch sign / roll) | ✅ (`opentrackMapEulerToRot` + NVS axis map in `include/opentrack_pose.h`) |
| Coexistence with USB (Hatire + UDP same build) | ✅ |
| Security baseline (WiFi credentials **not** in git) | 🟨 (`secrets.h` local; NVS on device; migration / hardening in Phase 3) |

---

## Phase 3 — Easy flashing & settings from the web

**Goal:** Users can install or update firmware and manage settings without a full dev environment—ideally tied to GitHub releases or a small official tool.

| Task | Status |
|---|---|
| Define artifact: release binaries + manifest/versioning | ✅ ( **`VERSION`**, **`web-flasher/manifest.json`**, CI sync, semver in firmware) |
| Web-based flasher (e.g. **esp-web-tools** / browser serial) or documented one-click flow | ✅ ( **`.github/workflows/github-pages-flasher.yml`**, **`web-flasher/`** ) |
| On-device “newer build” hint | ✅ (HTTPS **`manifest.json`** after STA associate + backoff on failure; portal banner — install is still **user-triggered** USB or Wi‑Fi OTA) |
| Settings: schema, storage (NVS), migration between versions | 🟨 (NVS keys in use; **versioned schema** / migration ⬜) |
| Document recovery if flash fails (USB bootloader, button combo, etc.) | 🟨 (README bootloader note; expand if needed) |

---

## Phase 4 — On-device web / phone UX (optional for V1)

**Goal:** Configure WiFi, calibration shortcuts, and modes from a phone or laptop without custom desktop software—**if** it fits V1 scope.

| Task | Status |
|---|---|
| Captive portal or small HTTP server on ESP (when in AP or dual mode) | ✅ (AP **:80** + STA **:8080**; same UI from `src/portal_html.cpp` in **`azimuth_main_*`**) |
| **Or** BLE GATT for lightweight config (often nicer for phones; more firmware work) | ⬜ |
| Same settings backend as Phase 3 (one model, multiple UIs) | 🟨 (HTTP uses same NVS namespace; BLE not started) |

*Scope note:* V1 already assumes **WiFi streaming** (Phase 2). Optional BLE / calibration UX can slip to **V1.1** if needed.

---

## Parking lot — ideas to consider (not all V1)

These are common for head trackers; pick what matches your audience.

| Idea | Why |
|---|-----|
| **Calibration / recenter UX** | Beyond one button: axis remap, smoothing presets, saved profiles. |
| **Drift / filter tuning** | Document OpenTrack filter settings; optional on-device presets. |
| **USB + WiFi simultaneously** | Useful for debug; define which path OpenTrack uses. |
| **CI** | Build firmware on every push; optional hardware-in-the-loop later. |
| **Signed OTA** | OTA ships unsigned today; plan ECDSA / Espressif secure boot keys + rollback for a future hardening pass. |
| **Desktop companion** | Small app for WiFi discovery—only if browser tooling is not enough. |
| **GitHub-hosted web flasher** | ✅ Shipped: **`web-flasher/`** + GitHub Actions; parking-lot ideas (WebRTC LAN hints, etc.) remain optional. |
| **Privacy / safety** | No cloud requirement; local network only—stated in README overview. |

---

## Changelog (manual)

| Date | Update |
|---|---|
| 2026-03-22 | Initial roadmap: workstream snapshot + phases 1–4 + V1 draft criteria. |
| 2026-03-22 | V1 posture: wireless required; USB supported; enclosure + PH2 assembly tradeoff documented. |
| 2026-03-25 | Docs + BOM aligned with KiCad (**PWR1**, **`vcc`**, **BUZZER1**, **MLT-5020**, **FUNC1** footprint). |
| 2026-04-02 | Docs + BOM: buzzer path **Q2** **AO3400A**, **D2** **B5819WS**, **R20**/**R21** gate network; **parts-list** / **wiring** / **hardware-profiles** / **kicad** / **README** / **easyeda2kicad** README. |
| 2026-03-27 | Firmware ~30%: Hatire + WiFi/OpenTrack UDP; `secrets.h`; PCB ~95% with **panelization** left before fab. |
| 2026-03-27 | Firmware ~40%: NVS + HTTP settings, provisioning portal; roadmap/tasks aligned; shared OpenTrack axis helper; portal HTML split to `portal_html.cpp`. |
| 2026-03-28 | PlatformIO envs **`azimuth_main_diy`** / **`azimuth_debug_diy`** (+ **`_*_pcb`**); GitLab CI + GitHub Pages flasher; NVS portal axis map; **`VERSION`** / manifest sync; update banner. Docs split: README for overview; **[using-azimuth.md](using-azimuth.md)**; **[development.md](development.md)**. |
| 2026-03-28 | Firmware snapshot toward V1 revised to **60–70%** (core tracking + wireless + settings + release path in place; I/O, battery, OTA, refactor still open). |
| 2026-04-05 | **Azimuth_Design**: docs aligned with schematic/PCB; **ERC/DRC clean**; PCB design workstream **100%**; V1 checklist splits **KiCad ready** vs **assembled bring-up**; panelization remains optional for production. |
| 2026-04-18 | **V0.1** PCB **finalized**; **ordered** from fab; PCBA nearly complete (**~15 days** to assembled units). README + roadmap + V1 checklist: manufacturing milestone checked; **bring-up** pending board arrival. |
| 2026-05-02 | **Assembled V0.1 boards received**; **bring-up / testing in progress**. **Enclosure:** design **started** (not in repo yet). **Firmware:** power/thermal + modular I/O bring-up on PCB; **battery ADC** still open. README + roadmap + parts-list + kicad snapshot lines updated. |
| 2026-05-08 | **Wireless updates (OTA) shipped.** New **`track_update`** module pulls `firmware/<board>/firmware.bin` from the same trusted GitHub Pages release into the standby `ota_0` / `ota_1` slot via the Arduino `Update` class (TLS pinned to ISRG Root X1, async chunk pump in `networkLoop`), then reboots into it. Triggered by **FUNC long-press (~2 s)** *or* the portal **“Install over Wi‑Fi”** button (banner + Device card). Distinct **cyan throb** LED override + **start / ok / fail** buzzer tunes. Refuses to start in Offline‑Mode AP, during thermal hold, or with battery ≤15 % off‑charger. USB flasher remains the recovery path. Default partition table already had `ota_0` / `ota_1` slots — no NVS migration. Roadmap, [`io-led-buzzer-plan.md`](io-led-buzzer-plan.md), [`firmware-architecture-plan.md`](firmware-architecture-plan.md), and [`using-azimuth.md`](using-azimuth.md) updated. |
| 2026-05-10 | **Docs sweep:** Firmware snapshot **~90%**; **`track_network`** split reflected across [development.md](development.md), [firmware-architecture-plan.md](firmware-architecture-plan.md), [implementation-handoff-prompt.md](implementation-handoff-prompt.md), [power-and-thermal.md](power-and-thermal.md) (portal `/api/status` activity + UDP streaming vs modem sleep). **Enclosure** progress set to **~90%+** (design). |
| 2026-05-10 | **User Guide** ([user-guide.md](user-guide.md)): end-user manual; battery policy / OTA wording aligned with firmware; [development.md](development.md) + [power-and-thermal.md](power-and-thermal.md) updated for wireless OTA (manifest check ≠ USB-only). |

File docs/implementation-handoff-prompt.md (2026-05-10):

# Implementation handoff — prompt for a new agent / session

**How to use:** Paste the block under [“Prompt (copy below)”](#prompt-copy-below) into a fresh AI chat (or give it to a developer). The repo is **`Azimuth`** — ESP32-C3 + BNO08x head tracker firmware with OpenTrack UDP/Hatire, HTTP portal, KiCad PCB path.

This file is maintained alongside **[io-led-buzzer-plan.md](io-led-buzzer-plan.md)** and **[firmware-architecture-plan.md](firmware-architecture-plan.md)**. Update this handoff when scope or order changes.

---

## Current product state (2026‑05, ~90% firmware)

The items below are **shipped** on `main` unless noted.

- **CI:** GitLab builds **`azimuth_main_diy`** (artifacts), **`azimuth_main_pcb`**, **`azimuth_debug_diy`**, runs **`scripts/run_host_tests.sh`**.
- **Networking:** Split into **`src/track_network_{wifi,http,prefs,udp}.cpp`** + **`track_network_internal.h`**; public API **`track_network.h`** unchanged for **`main.cpp`**.
- **Pause/stasis:** `trackNetworkSetStasis` / `trackNetworkStasisActive`; UDP + Hatire gated; modem sleep forced in stasis; FUNC double-tap idle; thermal emergency clears stasis.
- **LED:** `io_led_policy` priority stack + `PolicyOverride`; **`led_mode`** in NVS + portal + `/api/status`.
- **OTA:** `track_update` — chunked HTTPS pull; FUNC long-press (~2 s) + portal **Install over Wi‑Fi**; `POST /api/update` + `GET /api/update_status`; refuses Offline AP / thermal hold / critical battery off‑charger.
- **Portal UX:** Power-aware `/api/status` polling, boot/focus bursts, manifest-pending faster polls (`web/app/main.js` + `web/app/config.js` → codegen to **`portal_html.cpp`**).

**Remaining toward V1:** See **[roadmap.md](roadmap.md)** — e.g. battery ADC polish, enclosure, optional **`main.cpp`** decomposition, NVS schema versioning.

---

## Prompt (copy below)

```
You are implementing firmware and documentation changes for the Azimuth repository (PlatformIO, Arduino-ESP32, ESP32-C3). Read these docs first — they are authoritative for intent:

- docs/io-led-buzzer-plan.md — LED/buzzer layers, FUNC button behavior
- docs/firmware-architecture-plan.md — module layout (network split complete), CI
- docs/power-and-thermal.md — modem sleep, portal polling, UDP/streaming interaction
- docs/user-guide.md — end-user manual (prefer this for “how do I use it?”)
- docs/using-azimuth.md — portal / OpenTrack reference detail

Constraints:
- Match existing code style (namespaces azimuth_*, minimal unrelated refactors).
- Networking changes: extend `track_network_*.cpp` / `track_network_internal.h`; keep `track_network.h` stable unless coordinated with main loop.
- IMU_DEBUG_MODE builds must still compile (network stubs / conditional compilation as today).
- After editing `web/`, run: python3 scripts/portal_codegen.py --generate

Prioritize items from docs/roadmap.md and any issue the user describes.
```

---

## Historical note (original phased plan)

The repo originally tracked work as: CI guardrails → pause/stasis → LED policy → **network split** → OTA. **OTA** and **network split** are complete. The embedded prompt above is trimmed for **maintenance**; older milestone text lives in git history and **[roadmap.md](roadmap.md)**.

---

## Related documents

- [io-led-buzzer-plan.md](io-led-buzzer-plan.md)
- [firmware-architecture-plan.md](firmware-architecture-plan.md)
- [roadmap.md](roadmap.md)

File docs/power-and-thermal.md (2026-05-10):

# Power, heat, and battery (firmware)

This is the **single place** for how firmware manages **power and thermal** behavior, plus **planning notes** for battery runtime and **PCB battery wiring**. Day-to-day portal steps stay in [**Using Azimuth**](using-azimuth.md) (see **Portal sections** and **Power, heat, and battery** there).

Implementation code: [`src/power_policy.cpp`](../src/power_policy.cpp) (fixed cadences + modem-sleep delay), networking modules under **`track_network_*.cpp`** / [`track_network_internal.h`](../src/track_network_internal.h) (adaptive sleep, HTTP, UDP), and embedded UI in [`src/portal_html.cpp`](../src/portal_html.cpp) (generated from `web/` via **`scripts/portal_codegen.py`**).

**Portal knobs:** **Tracking & radio** — **Wi‑Fi TX power**, **IMU report interval**. The web UI is for **settings, monitoring, and update links**, not a high‑refresh dashboard; non‑tracking paths use relaxed timings (see below). **Save** and **reboot** use normal HTTP — no extra artificial delay beyond the usual `handleClient` slice (tens of ms).

---

## What actually costs power

On a small ESP32‑C3 module, **Wi‑Fi** dominates current and perceived warmth: the radio staying associated, transmit power, and how often the stack runs. The **IMU fusion and pose output** are comparatively small compared to keeping Wi‑Fi fully busy.

Firmware therefore targets **radio duty**, **CPU time in the network stack**, and **unnecessary HTTP** — not the core tracking math.

---

## Tracking is not throttled by these changes

Pose updates (USB Hatire and OpenTrack **UDP**) still run **whenever a new rotation-vector report arrives** from the BNO08x. That rate is set by **IMU report interval** in the portal (and reboot), not by Wi‑Fi power logic.

Power-related code does **not** insert a 200 ms (or similar) delay into sending poses. Background timers only affect **portal HTTP servicing**, **DNS refresh for the OpenTrack host**, **UDP socket setup**, **modem sleep policy**, and **optional HTTPS** for the update banner.

---

## 1. Adaptive Wi‑Fi modem sleep

Previously, firmware could keep **`WiFi.setSleep(false)`** in station mode so the radio stayed maximally awake (helpful for mDNS responsiveness, at the cost of heat).

**Now:** On a normal **home Wi‑Fi** connection, after the device has been **idle from portal activity** for a fixed time (see [`src/power_policy.cpp`](../src/power_policy.cpp), `wifiSleepIdleDelayMs()`), firmware enables **modem sleep** again (`WiFi.setSleep(true)`), which reduces average radio duty.

**Pause / stasis** (FUNC single tap, see [**using-azimuth.md**](using-azimuth.md)) forces modem sleep on STA while connected — independent of portal idle timing — so the radio stays in a low-duty posture until you resume. Thermal emergency / battery cut still override networking regardless of pause.

**Portal activity clock** (`lastPortalActivityMs`) advances on interactive routes **and** on **`GET /api/status`** / **`GET /api/pose`** (so an open settings tab that polls JSON still counts as “using” the portal for sleep policy).

**While OpenTrack UDP is actively streaming** (UDP enabled in NVS, not in stasis, and a packet was sent recently), firmware **defers** modem sleep so light sleep does not add jitter to high-rate UDP — see `applyAdaptiveWifiSleep()` in **`track_network_prefs.cpp`**.

**Not sleeping:** **Azimuth‑Setup** AP / captive portal, or when **not** connected as STA — sleep stays off so setup and recovery stay reliable.

---

## 2. Fixed portal / network cadence (no “power profiles”)

HTTP servicing interval (~**25 ms**), background housekeeping (~**500 ms**), thermal sampling (when not in thermal hold), and modem-sleep idle delay are **single fixed values** in [`src/power_policy.cpp`](../src/power_policy.cpp). **Pose latency** is governed by **IMU interval** and [`loop()` in `main.cpp`](../src/main.cpp): each new rotation-vector report is converted and sent over USB/UDP **before** throttled portal work runs that iteration.

---

## 3. Time-sliced `trackNetworkLoop()`

The main loop calls `trackNetworkLoop()` often (driven by IMU / idle), but **work inside it is split**:

- **Portal HTTP** (`handleClient` for STA and AP, plus captive DNS on AP) runs on a **timer** — not on every single loop iteration.
- **Heavier “background” tasks** (OpenTrack hostname refresh cadence, UDP socket open, applying adaptive modem sleep) run on a **~500 ms** cadence (see `networkBackgroundPeriodMs()` in [`src/power_policy.cpp`](../src/power_policy.cpp)) so DNS / sleep policy are not re-evaluated thousands of times per second.

This cuts **CPU + Wi‑Fi stack** churn when the portal is open or the loop runs fast; it does **not** batch UDP pose packets.

---

## 4. Default Wi‑Fi transmit power

If NVS has no `wifi_tx` value yet, firmware defaults to **balanced** TX so tracking/OpenTrack links stay reliable. Users can choose **low** for cooler/calm links or **high** for weak RF in the portal.

---

## 5. Firmware update check (HTTPS)

On STA, **once per boot** (with retry/backoff on failure), shortly after the device has **associated** and had a short stack settle (~300 ms), firmware performs an HTTPS `GET` to the published manifest to decide if the portal should show an “update available” banner. **Timeouts are short** so a slow CDN does not hold the device in a long active session.

That check is **notification + eligibility context** for updates. **Installing** a new build is still a **user action**: **USB web flasher**, or **wireless OTA** from the portal / FUNC long-press when allowed (see [**Using Azimuth → Wireless updates**](using-azimuth.md#wireless-updates-ota)).

---

## 6. Portal page polling (browser)

The settings page is mostly static. After the first load (which calls `/api/status` to fill the form), the script **polls `/api/status`** on a **power-aware schedule** while the tab is **visible** (defaults in `web/app/config.js`: ~**18 s** after recent pointer activity, ~**12 s** when the tab is visible but input‑idle, bursts after load / tab focus / manifest pending — see `web/app/main.js`). Polling **pauses** when the tab is hidden (`document.hidden`) and uses **tab coordination** so several copies of the page do not all hammer the device.

That rate is **much slower** than tracking; it is **not** the IMU pose rate.

---

## Summary table

| Mechanism | Saves power / heat by… | Affects tracking pose rate? |
|---|---|---|
| Modem sleep after portal idle | Lower average Wi‑Fi duty | No |
| Sliced `trackNetworkLoop` | Less HTTP/DNS/sleep work per second | No |
| Adjustable `wifi_tx` (default balanced) | Less TX current on **low** | No (may affect Wi‑Fi range) |
| Short update check after associate | One bounded HTTPS session per boot | No |
| Portal poll cadence + hidden-tab pause | Less HTTP when UI open | No |
| IMU interval (user setting) | Fewer reports → less USB/Wi‑Fi **traffic** from poses | **Yes** — this is the main tracking “refresh” control |

---

## Battery runtime planning

Not measured on every PCB revision — **bench your build** if you need a firm number.

The **radio dominates** current. For **Wi‑Fi + IMU + UDP** (no USB), a **400 mAh** 1S LiPo might land in a **~4–9 hour** band depending on signal and settings, with **~5–7 h** as a rough mid guess. **USB-only Hatire** with Wi‑Fi off lasts **much longer**.

---

## Battery packs and the Azimuth PCB (hardware)

Only applies if you use the **integrated Azimuth board** with the **JST PH2.0** battery connector.

**Adafruit-style JST LiPos are not compatible** with this PCB’s connector polarity. Follow **+ / −** silk at **PH2.0** and use a pack wired like the **YDL** reference in [**parts-list → Off-board pack**](parts-list.md#off-board-pack-azimuth-pcb-wireless).

**DIY XIAO** builds: battery on the **XIAO pads** or your own wiring — see [parts-list](parts-list.md) and [wiring.md](wiring.md); polarity rules differ from the Azimuth PCB JST.

---

## Related docs

- [**Using Azimuth**](using-azimuth.md) — portal URLs, OpenTrack, short pointer here for power.
- [**Parts list — Off-board pack**](parts-list.md#off-board-pack-azimuth-pcb-wireless) — sourcing and connector detail.
- [**Development**](development.md) — build / flash.

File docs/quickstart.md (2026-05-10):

# Azimuth quick start

Short path from a fresh flash to head tracking in **OpenTrack** over Wi‑Fi.

**Full manual (recommended):** [**User Guide**](user-guide.md)

Assumes firmware is already installed (web flasher supports both hardware targets; `DIY` is the default selection). **Hardware paths** and which build to flash: [**README**](../README.md), [**hardware-profiles.md**](hardware-profiles.md). Deeper portal and OpenTrack detail: [**using-azimuth.md**](using-azimuth.md).

## 1. Join your home Wi‑Fi (first setup)

1. Power the board on. On your phone or computer, connect to the **Azimuth-Tracker** Wi‑Fi network (**Offline Mode**).
2. A setup page should open automatically, or open **`http://192.168.4.1/`** in a browser.
3. Enter your **home Wi‑Fi name** and **password**.
4. **Scroll to the bottom** of the page and **save** (apply). The board will connect to your network and restart.

## 2. Tell the tracker where OpenTrack runs

Do this on the **same computer** where you use **OpenTrack**, on your **home Wi‑Fi** (not on **Azimuth-Tracker** Offline Mode).

1. Open **`http://azimuth.local:8080/`** in a browser.  
   If that fails, use **`http://<device-ip>:8080`** (find the device in your router’s list). The address must end in **`:8080`**.
2. Turn **UDP to PC** **on** if it is off.
3. Click **Fill address** (the page fills in this PC’s address for you). If you don’t see that button, type this PC’s **IPv4** (e.g. `192.168.1.x`) in **UDP address** instead.
4. **Scroll down** and **save**.

## 3. OpenTrack

1. Input: **UDP over network** (wording may vary slightly by version).
2. Port: match the **UDP port** in the portal (default **4242** unless you changed it).
3. If **Windows** asks, allow the port through the firewall.

Move the tracker—you should see motion. **Recenter** in OpenTrack after things settle.

## Firmware updates

On **home Wi‑Fi**, the portal may show a banner if a **newer** version is published on GitHub Pages (about one check per boot). You can:

- **Install over Wi‑Fi** from the portal (**Device** section or banner), or **hold FUNC ~2 s** on the Azimuth PCB (see [**User Guide → Updates**](user-guide.md#9-firmware-updates)), or
- Reflash over **USB** with the same [**web flasher**](https://fuglong.github.io/Azimuth/) (Chrome or Edge).

Wireless install is blocked in **Offline mode**, when the chip is **too hot**, or when **battery is very low** off USB — use USB in those cases.

## More help

- **[User Guide](user-guide.md)** — complete manual (Wi‑Fi, portal, FUNC, battery, troubleshooting).
- **[README](../README.md)** — project overview and doc index.
- **[Using Azimuth](using-azimuth.md)** — portal details, OpenTrack (USB Hatire + UDP), tips.
- **[Development](development.md)** — build from source, CI, versioning, repo layout.
- **Browser flasher:** [https://fuglong.github.io/Azimuth/](https://fuglong.github.io/Azimuth/) (Chrome or Edge).

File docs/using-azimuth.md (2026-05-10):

# Using Azimuth

How to reach the **settings portal**, connect **OpenTrack**, and interpret a few common behaviors.

**Step-by-step manual:** [**user-guide.md**](user-guide.md) · **Shortest path:** [**quickstart.md**](quickstart.md)

## Settings portal URLs

All **`azimuth_main_*`** builds share the same **portal**, **Hatire**, and **UDP** behavior. On-board **RGB**, **buzzer**, and **button** apply only where the hardware has them ([**hardware-profiles.md**](hardware-profiles.md)):

| Situation | Open in your browser |
|---|---|
| Board already on your **home Wi‑Fi** | **`http://azimuth.local:8080`** or **`http://<device-ip>:8080`** (default hostname is **`azimuth`**) |
| **Offline Mode** (first setup, recovery, or off-grid use) — you joined **Azimuth-Tracker** | **`http://192.168.4.1/`** on port **80** (captive portal may open this for you) |

**`azimuth.local` does not work** in **Offline Mode** AP—only after the device joins your LAN as a client. If **`.local`** fails on Windows, install **Bonjour** (e.g. Apple Bonjour Print Services) or use the device **IP** from your router. Guest or isolated Wi‑Fi often blocks discovery; use the IP.

## Portal sections (what you can change)

The UI is grouped roughly as follows:

| Section | What it controls |
|---|---|
| **Wi‑Fi** | SSID / password, **Scan networks** (brief tracking pause). New credentials → **reboot**. |
| **LAN & discovery** | mDNS on/off, **hostname** (letters, digits, hyphen; max 24). Changes → **reboot**. |
| **OpenTrack (PC)** | USB Hatire on/off, UDP on/off, **UDP address** / **port**, **axis mapping** (which yaw/pitch/roll go to **Rot 0–2**, optional **invert**). Use **Fill address** when you open the portal on the PC running OpenTrack. **`something.local` from the ESP32** is unreliable—prefer a numeric LAN IP. |
| **Tracking & radio** | **IMU report interval** (5–40 ms) and **Wi‑Fi TX power** (low / balanced / high). IMU interval change → **reboot**. |
| **Device** | Firmware **version**, battery telemetry (pack mV, raw ADC mV, % estimate, inferred charge/discharge/idle trend), battery capacity + calibration offset settings, save / reboot, status. On Wi‑Fi, a banner may link to the **USB web installer** if a newer build is published. |
| **Sound & light** (RGB / buzzer boards) | **RGB brightness**, **buzzer volume**, **LED mode** (rainbow, slow rainbow, status, **manual RGB** with 0–255 sliders + quick presets + live preview), and stored **`led_r` / `led_g` / `led_b`** in flash. System warnings (thermal, very low battery, setup AP, **pause**) can override the ambient LED until the condition clears. |
| **Advanced** | **Reset all settings** (clears stored config and reboots; may return to **Azimuth-Tracker** Offline Mode if no home SSID remains). |

Settings live in **flash (NVS)** on the device. If something is unset, the build can fall back to optional compile-time defaults in **`include/secrets.h`** (see [**development.md**](development.md)).

Saving **new Wi‑Fi** triggers a **reboot**. If the board cannot join that network, it falls back to **Azimuth-Tracker** Offline Mode so you can fix SSID/password without reflashing.

## Integrated PCB: RGB, FUNC, buzzer

On **`azimuth_main_pcb`**, the Azimuth board’s **common-anode** RGB uses **inverted** PWM on **IO0** (green, **R8**), **IO1** (red, **R7**), **IO3** (blue, **R6**), with simple ballast scaling in firmware vs those resistors (DIY builds without that LED layout keep a simple GPIO3 status line instead).

**FUNC** (**IO7**, pull-up, switch to GND): **single tap** toggles **Pause** (see below). **Double-tap** is reserved (no action). **Long press (~2 s)** triggers a **wireless firmware update** (see [Wireless updates](#wireless-updates-ota)).

## Pause (FUNC single tap)

**Pause** puts the tracker in **stasis**: it **stops sending OpenTrack UDP** and **USB Hatire** pose packets for as long as pause is on, plays a **short sound** on enter and a **different sound** on exit, forces **aggressive Wi‑Fi modem sleep** on STA when idle, and shows a **distinct LED pattern** (slow blink on DIY; cyan‑ish pulse on RGB) so you can leave the device powered without streaming to the PC.

- **Not saved in NVS** — pause is session-only. Your portal **UDP enabled** / **Hatire** preferences apply again after you resume.
- **USB serial** is unchanged (you can still flash or use a serial monitor; pause only affects the Hatire packet stream used by OpenTrack).
- **Safety** — you cannot enter pause while the pack is at **~1%** (critical) or after **thermal hold** has cut Wi‑Fi; an overheating event **clears** pause automatically because the network path is torn down.

Press **FUNC** once to pause, once again to resume.

## OpenTrack on the PC

Use **either** **Hatire Arduino** (USB) **or** **UDP over network** as the **input**—not both at once. You can disable USB Hatire in the portal for Wi‑Fi-only use; OpenTrack should still subscribe to only one path.

| Step | Action |
|---|---|
| **Input** | **Hatire Arduino** (COM, **115200**, **DTR** on) **or** **UDP over network** (port matches portal / default **4242**; allow UDP in the OS firewall). |
| **Hatire axes** | With **default** portal mapping: **Yaw→0, Roll→1, Pitch→2** (wording may say “axis 0 / 1 / 2”). If you change **Rot 0–2** in the portal, match OpenTrack to those slots. USB and UDP share the same mapping. |
| **Filter** | Prefer a **natural motion**-style filter if your OpenTrack version offers it. |
| **Responsiveness** | Turn **responsiveness** up (e.g. maximum) so motion feels direct. |
| **Start** | **Start** tracking; **Center** / **recenter** after the filter settles. |

**USB Hatire:** Do not leave a **serial monitor** open on the same COM port while OpenTrack is using it.

**UDP:** The PC listens on the configured port; the portal sets where the ESP32 **sends** datagrams (your PC’s LAN IPv4).

## Firmware updates

### Wireless updates (OTA)

The board can pull the latest **official release** build from the same **HTTPS / GitHub Pages** source the version banner already trusts, write it into the **standby OTA partition**, and reboot into it — no USB cable required. (Firmware image signing inside the binary is **not** implemented yet; transport trust is TLS to that release host.)

| Trigger | What to expect |
|---|---|
| **Portal button** | On home Wi‑Fi, the **Device** section (and the yellow update banner when a newer version is published) has an **Install over Wi‑Fi** button. A blue progress card appears showing percent / KB downloaded. |
| **FUNC long-press** (~2 s) | Hold **FUNC** for about two seconds — you'll hear a **rising 4-note tune** when the download starts. Single-tap pause is suppressed for that press. |

While the OTA runs, the LED switches to a **fast cyan throb** (or a fast blink on status-LED-only boards). On success the board plays a **resolved arpeggio** and reboots into the new image automatically; on failure it plays a **stern descending tone** and stays on the current image. Tracking is **paused** during the download to give all bandwidth and CPU to the fetch.

The board **refuses to start** an OTA when:

- It’s in **Offline-Mode AP** (no internet route).
- A **thermal-hold** event has cut Wi‑Fi.
- Battery is **≤15 %** and not on USB charge — a brownout mid-write would brick the device.

If wireless updates aren’t appropriate (no Wi‑Fi, lost device, or you want to flash a custom build), the **USB web flasher** is unchanged and remains the recovery path.

**USB flasher:** [https://fuglong.github.io/Azimuth/](https://fuglong.github.io/Azimuth/) (Chrome or Edge). Your running version appears under **Device** in the portal.

## Power, heat, and battery

Expect the module to feel **warm when Wi‑Fi is on** — that is normal for a small ESP32‑C3. Tune **Tracking & radio** in the portal: **Wi‑Fi TX power** and **IMU report interval** (IMU interval affects tracking smoothness and load, not just “power”).

**Everything the firmware does to save power and heat** (modem sleep, network loop scheduling, portal polling, defaults): see [**power-and-thermal.md**](power-and-thermal.md). **Rough battery runtime guesses** and **which LiPo packs match the Azimuth PCB JST** are in that doc too, with full sourcing detail in [**parts-list**](parts-list.md#off-board-pack-azimuth-pcb-wireless).

---

**Related:** [quickstart.md](quickstart.md) · [power-and-thermal.md](power-and-thermal.md) · [development.md](development.md) · [README](../README.md)

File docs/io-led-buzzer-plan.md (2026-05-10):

# I/O experience plan — LED, buzzer, FUNC button

This document describes a **layered, user-respecting model** for RGB, buzzer, and the FUNC button: what users can choose, when the system may **override** that choice, and how we grow features without spaghetti state.

It builds on code that already exists: `azimuth_io_led` defines `RgbPreset` (Rainbow, RainbowSlow, Status, Manual), IMU-driven `setStatus()`, rainbow timing in `tick()`, and portal **RGB brightness** (`rgb_brightness`). The FUNC button supports single/double tap and **long-press can be added** in `io_button` when needed.

**Primary product behavior for FUNC (single tap):** **Pause / stasis** — stop OpenTrack **UDP** output, push radio and workload toward **super low power**, play an **entry** buzzer sound; another single tap **resumes** tracking and plays a **distinct exit** sound. This is for leaving the device on (e.g. on battery) without wasting power while away from the PC.

---

## Design goals

1. **User intent is default.** In normal operation, LED behavior follows a **saved preference** (preset and optional parameters).
2. **System overrides are explicit and temporary.** Setup AP, critical battery, thermal protection, or factory-defined “alarm” states may **take over** LED (and optionally buzzer policy), then **restore** the user’s preference when the condition clears.
3. **Single policy owner.** One place decides “what should the LED show **this** frame?” so rainbow, status green, battery blink, setup mode, and **stasis** do not fight in scattered `if` statements.
4. **Incremental delivery.** Ship **pause/stasis** and a **small LED priority stack** first; add richer ambient modes (axis-mapped color) once the framework exists.
5. **Hardware-aware.** DIY builds without RGB keep single-LED semantics; PCB gets full RGB behavior (`board_config` capabilities).

---

## FUNC button — primary behavior: pause / stasis

| Input | Behavior (target) |
|---|---|
| **Single tap** | **Toggle pause (stasis).** If running → enter stasis; if in stasis → resume normal operation. |
| **Double tap** | **Reserved** (not assigned for V1 — avoid accidental triggers; previous thermal **demo** hooks in `main.cpp` should be removed or repurposed). |
| **Long press (hold ~2 s)** | **Triggers wireless firmware update** — see [Wireless updates (OTA)](#wireless-updates-future--ota). Single-tap on the same press is suppressed (no accidental pause). |

### Stasis (paused) — functional requirements

- **UDP:** Do **not** send OpenTrack UDP packets while paused. This must be a **runtime** gate (session-only), independent of the portal **“UDP on”** NVS preference — resuming restores live UDP according to that saved setting.
- **USB Hatire:** **Decision for implementer:** Either pause Hatire as well for a consistent “tracker frozen” semantics, or leave Hatire on if pause is defined as “wireless only.” **Recommendation:** pause **both** UDP and Hatire during stasis so behavior is predictable; document in `using-azimuth.md`.
- **Power:** Enter aggressive low-power posture: e.g. confirm **Wi‑Fi modem sleep** (`WiFi.setSleep(true)`), rely on existing adaptive sleep policy where possible, and **avoid unnecessary work** in the loop (no UDP prep). Optional stretch: **lower IMU report rate** during stasis (requires `enableRotationVector` / prefs interaction — more invasive; document if deferred).
- **Sounds:** Distinct **enter-stasis** and **exit-stasis** cues in `io_buzzer` (short, differentiable; respect buzzer volume).
- **LED:** Distinct **stasis** appearance (e.g. slow pulse / dim color) so the headset visibly reads “idle” vs tracking. Stasis participates in the **priority stack** below safety-critical overrides.

### Resume

- Restore previous tracking outputs per prefs; play **exit** sound; clear stasis LED layer.
- If the device was in **thermal hold** or **critical battery** emergency, **safety policy wins** — stasis must not mask those (either block entering stasis or force-exit stasis when a critical event fires; implementer should choose one explicit rule).

---

## Concept: priority layers for LED output

Think of the LED pipeline each `tick()` as:

```
Evaluate active overrides (highest priority wins)
    → if none: render user's chosen "ambient" mode
```

Suggested **priority order** (high to low — tune during implementation):

| Priority | Source | Example behavior |
|---|---|---|
| Highest | Thermal hold / Wi‑Fi cut | Distinct pattern (e.g. slow red pulse or off — match thermal doc) |
| High | Critical battery | Fast warning pulse; coordinate with buzzer panic |
| Medium | Setup / captive AP (`setup_ap`) | Obvious “provisioning” pattern (e.g. cyan breathe) |
| **Stasis (pause)** | User pressed FUNC — tracking paused | Slow pulse / different hue so “idle but powered” is obvious |
| Low | Transient feedback | Short blink after save, calibration done, etc. |
| Base | User ambient mode | Rainbow, solid, axis map, manual RGB, status-only |

**Rules:**

- Overrides **stack logically** but only the **top active** layer drives pixels until it releases.
- **Stasis** is cleared on resume; it does not persist across reboot (runtime flag only).

---

## User-facing LED modes (ambient / base layer)

These complement today’s `RgbPreset` enum; names may stay as enum cases or collapse into a single `led_mode` NVS uint with sub-options.

| Mode | Description | Notes |
|---|---|---|
| **Status** | IMU OK = green-ish accent; lost = dim/off | Already partially implemented via `setStatus()` |
| **Rainbow / Rainbow slow** | Decorative idle look | Already implemented |
| **Solid / palette** | A few curated colors | Easier than full RGB for many users |
| **Manual RGB** | User picks R,G,B in portal | Align with existing `setManualRgb` / portal brightness |
| **Axis hue (later)** | Map yaw/pitch/roll to color position | Fun but more tuning |
| **Off** | LED off when not overridden | Respects dark rooms |

**Portal:** Extend “Sound & light” (or a renamed card) with **LED mode** selector + optional color controls when mode = manual/solid. Persist to NVS alongside `rgb_brightness`.

---

## System overrides (non-ambient)

| Condition | LED idea | Buzzer |
|---|---|---|
| **Azimuth-Tracker Offline Mode AP** | Unique animation — provisioning/off-grid | Optional short chirp on entering offline mode (once) |
| **Battery warning bands** | Amber / red pulse | Already partially integrated |
| **Thermal warn / emergency** | Red/orange patterns | Existing tunes; align with LED |
| **Save / cal success** | Brief green flash | Short positive beep (optional “quiet mode”) |

---

## Buzzer integration

The buzzer already plays structured tunes for battery and thermal events. Extend with **named cues** for stasis enter/exit and keep a small **policy** so tunes do not stomp each other incoherently.

- Map events → `(tune id, may_interrupt_previous)` for battery vs thermal vs **stasis**.
- **User preference:** Volume curve exists; optional future “quiet mode” suppresses non-safety cues.

---

## Wireless updates (future / OTA)

**Status:** Shipped as of 2026-05-08. The historical "future" framing is kept below for context — concrete implementation summary first.

**What ships today:**

- New **`src/track_update.{h,cpp}`** — chunked HTTPS pull state machine (`Idle → Connecting → Downloading → Finalizing → Success/Failed`).
- Pulls `firmware/<board>/firmware.bin` from the **same GitHub Pages release** the manifest check already trusts. The URL is derived at runtime from `AZIMUTH_RELEASE_MANIFEST_URL` (overridable with compile-time `AZIMUTH_RELEASE_FIRMWARE_URL`).
- **TLS** pinned to **ISRG Root X1** (Let's Encrypt), shared with the manifest check via `azimuth_net::releaseRootCaCert()` — a network MitM with a private CA cannot push a build.
- Writes through the Arduino-ESP32 **`Update`** class (not `HTTPUpdate` — that has a known ESP32-C3 MD5-mismatch regression in 2025+ Arduino frameworks; see [esphome#13255](https://github.com/esphome/esphome/issues/13255)).
- The default PlatformIO partition table for `seeed_xiao_esp32c3` / `esp32-c3-devkitc-02` (4 MB flash) already includes **`ota_0`** / **`ota_1`** / **`otadata`** — no `board_build.partitions` change needed, so **NVS preferences survive the upgrade**.
- Cooperative tick: `azimuth_update::tick()` is called from `networkLoop()`. Each tick reads up to **4 KB** from the TLS socket and writes one flash sector, so the WebServer + IMU loop stay responsive and the user can watch progress.
- **Triggers:**
  - **FUNC long-press (~2 s)** — added to `io_button` with deferred-release suppression so the press doesn't also fire single-tap pause.
  - **Portal button** — `Install over Wi-Fi` in the update banner *and* the Device card. New routes `POST /api/update` and `GET /api/update_status`.
- **LED override** — new `PolicyOverride::Update` (cyan throb at 360 ms; matching fast blink on status-only boards) wins over ambient/setup-AP/stasis but yields to thermal hold.
- **Buzzer cues** — `playUpdateStartTune` (rising fifth), `playUpdateOkTune` (resolved arpeggio just before reboot), `playUpdateFailTune` (descending stern). Distinct from FUNC / pause / battery / thermal motifs.
- **Safety gates** — refuses to begin in Offline-Mode AP (no internet), during thermal hold, with battery ≤15 % and not charging (a brownout mid-write would brick), or while another OTA is active. Stasis is forced **on** during the download so radio bandwidth and CPU go to the fetch.
- **Recovery** — USB **esp-web-tools** flasher path is unchanged. If OTA fails, the device aborts the half-written slot and stays on the working image; the failure tune + portal status both show the reason.

**Original feasibility framing (kept for archaeological reference):** ESP32 (Arduino / ESP-IDF) supports OTA via dual app partitions (`ota_0` / `ota_1`) and `HTTPUpdate` or custom HTTPS fetch. This repo previously shipped USB web flasher + manifest check from the portal — OTA is now additive, not replacing USB recovery.

Document detailed threat model and UX in a dedicated note when implementation starts; until then treat as **roadmap**, not V1-blocking.

---

## Implementation phases (suggested)

### Phase 1 — Pause / stasis (FUNC single tap)

- Runtime flag + API on network layer: e.g. `trackNetworkSetStasis(bool)` / `trackNetworkStasisActive()` gating `sendOpentrackUdp` and Hatire path from `main`.
- Buzzer: **enter** + **exit** stasis tones.
- LED: stasis pattern **or** minimal distinct brightness until full `LedPolicy` exists.
- Remove or replace **thermal demo** FUNC callbacks in `main.cpp`.
- **`docs/using-azimuth.md`:** Document pause behavior.

### Phase 2 — LedPolicy shell + persistence

- Centralize LED decisions (setup, thermal, battery, **stasis**, ambient).
- Portal: `led_mode` NVS + optional RGB fields.

### Phase 3 — Rich ambient modes

- Palette / axis hue; micro-interactions.

### Phase 4 — Long-press + OTA *(shipped)*

- Button driver: hold detection (`io_button::setLongPressCallback`, ~2 s window, suppresses single-tap on the same gesture).
- OTA module (`track_update`) reuses the default partition table's `ota_0` / `ota_1` slots — no `board_build.partitions` change.
- HTTPS pull from the same trusted release URL as the manifest check (TLS pinned to ISRG Root X1).
- Cyan-throb LED override + start/ok/fail buzzer cues; portal exposes `Install over Wi‑Fi` button + live progress (`POST /api/update`, `GET /api/update_status`).

---

## Testing and safety

- **DIY single LED:** Map stasis to slow blink vs steady tracking.
- **Thermal / battery:** Stasis must **not** hide critical warnings; define interaction explicitly.
- **Epilepsy / distraction:** Avoid harsh strobes on provisioning or stasis.

---

## Related code (today)

- `src/io_led.cpp` / `io_led.h` — presets, rainbow, status, manual RGB, brightness.
- `src/io_buzzer.cpp` — tunes and volume curve.
- `src/io_button.cpp` — debounce, single/double tap, **long-press (~2 s) → wireless OTA**.
- `src/main.cpp` — pose path, FUNC callbacks, `setStatus`.
- `src/track_network_udp.cpp` / prefs — UDP gated by NVS **`udp_on`**, link state, **`stasisActive`**, and OpenTrack target readiness (`track_network.h` façade).
- Portal — `rgb_brightness`, buzzer volume, `udp_enabled`.

---

## Related documents

- **Architecture / refactors:** [firmware-architecture-plan.md](firmware-architecture-plan.md)
- **Power, heat, battery:** [power-and-thermal.md](power-and-thermal.md)
- **Roadmap:** [roadmap.md](roadmap.md)
- **Handoff prompt (for implementers):** [implementation-handoff-prompt.md](implementation-handoff-prompt.md)

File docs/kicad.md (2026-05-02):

# KiCad

**V0.1 (current revision):** Design **finalized**; **assembled boards received**; **bring-up and testing in progress**. Timeline: [roadmap](roadmap.md).

**Integrated board:** open **`kicad/Azimuth_Design/Azimuth.kicad_pro`**. Schematic **`Azimuth.kicad_sch`**, layout **`Azimuth.kicad_pcb`**. Nets and GPIOs: [wiring.md](wiring.md) (PCB path). Human BOM summary: [parts-list.md](parts-list.md). **Tracked machine BOM:** **`kicad/Azimuth_Design/fab/Azimuth_bom.csv`** (KiCad **`kicad-cli sch export bom`** — regenerate with **`./scripts/export_azimuth_bom.sh`**; notes in **`fab/README.md`**). **Parts-only cost ballpark:** **`fab/Azimuth_bom_cost.txt`** (same script run). For each **fab order**, re-run **ERC** and **DRC**, refresh **`fab/`** exports if the schematic changed, then export **gerbers** / fab BOM as required.

| Location | Contents |
|---|---|
| **`kicad/Azimuth_Design/`** | Current project — sym/fp tables point at `../libraries/...` and `../easyeda2kicad_parts/...` |
| **`kicad/libraries/1_MyLib.kicad_sym`** | Project symbols (edit here; **Update Symbol from Library** in sch if copies drift) |
| **`kicad/libraries/1_MyFootPrints.pretty/`** | Project footprints |
| **`kicad/libraries/panelization.pretty/`** | Mouse-bite / panel footprints ([upstream](https://github.com/madworm/Panelization.pretty)) for production arrays |
| **`kicad/easyeda2kicad_parts/`** | Footprints + 3D pulled from EasyEDA — [README](../kicad/easyeda2kicad_parts/README.md) for import script |
| **`kicad/3d/*.STEP`** | Local STEP models referenced from some footprints |

Always open the **`.kicad_pro`** inside **`Azimuth_Design/`** so **`${KIPRJMOD}`** and library paths work.

**Before each fab order:** Re-run **ERC** and **DRC**, refresh **`fab/Azimuth_bom.csv`** via **`./scripts/export_azimuth_bom.sh`**, then export **Gerbers** (and your fab’s BOM/position files). Add a **panel** per your fab’s rules if you are not ordering singles.

**BOM fields:** Symbols carry **`Description`** and hidden **`Unit Price (USD)`** (low-qty ballpark — **not** live pricing). Refresh those with **`python3 scripts/update_azimuth_sch_bom_fields.py`**. **`./scripts/export_azimuth_bom.sh`** exports **`Unit Price (USD)`** into **`fab/Azimuth_bom.csv`** and writes **`fab/Azimuth_bom_cost.txt`** (1× board parts-only sum).

**Buzzer path:** **BUZZER1** is driven by **Q2** (**AO3400A**, **`ao3400_C20917`**) and **D2** (**B5819WS**, **`b5819ws_C64886`**) from **`easyeda2kicad_parts`** — see [parts-list.md](parts-list.md#buzzer-buzzer1) and [wiring.md](wiring.md#pcb-path-azimuth_design-u1-esp32-c3-wroom-02).

**Legacy:** **`kicad/ESP32_BNO086/`** — old layout, not maintained. Use **`Azimuth_Design`**.

**3D preview missing?** Footprints may list **`${AMZPATH}`** / **`${KICAD_3DMODELS}`** or paths under **`easyeda2kicad_parts`** — set env vars or rely on **`${KIPRJMOD}/../3d/...`** where used.

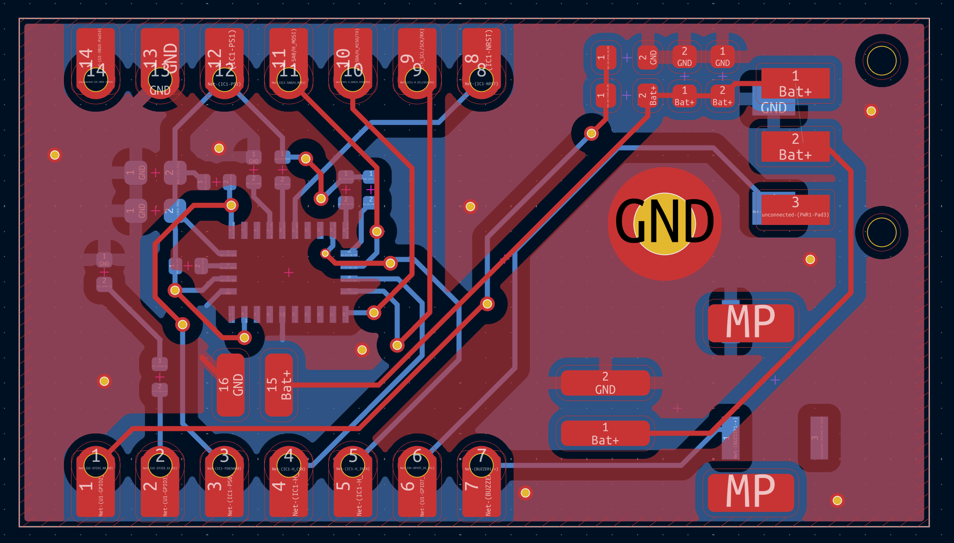
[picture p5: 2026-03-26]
img/CopperLayers.png

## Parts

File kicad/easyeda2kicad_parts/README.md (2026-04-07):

# EasyEDA → KiCad imports (LCSC)

Symbols, footprints, and 3D models pulled from EasyEDA/LCSC using **[easyeda2kicad](https://pypi.org/project/easyeda2kicad/)**.

## Layout (simple, one folder per LCSC part)

Under **`easyeda2kicad/`**, each part is self-contained (same idea as **`button_C49108648`**, **`switch_C128953`**, etc.):

| Part | Files |
|---|---|
| **WROOM-02** (C2934560) | **`../easyeda2kicad.kicad_sym`**, **`../easyeda2kicad.pretty/`**, **`../easyeda2kicad.3dshapes/`** (legacy single-module import) |
| **USB Type-C** C2765186 | **`easyeda2kicad/usb_type_c_C2765186.kicad_sym`**, **`usb_type_c_C2765186.pretty/`**, **`usb_type_c_C2765186.3dshapes/`** |
| **RGB LED** C779813 (TUOZHAN 1615 common anode) | **`easyeda2kicad/rgb_led_C779813.kicad_sym`**, **`rgb_led_C779813.pretty/`**, **`rgb_led_C779813.3dshapes/`** |
| **AO3400A** C20917 (buzzer low-side NMOS) | **`easyeda2kicad/ao3400_C20917.kicad_sym`**, **`ao3400_C20917.pretty/`**, **`ao3400_C20917.3dshapes/`** |
| **AO3401A** C347476 (reverse-polarity PMOS candidate) | **`easyeda2kicad/ao3401a_C347476.kicad_sym`**, **`ao3401a_C347476.pretty/`**, **`ao3401a_C347476.3dshapes/`** |
| **B5819WS** C64886 (buzzer flyback Schottky) | **`easyeda2kicad/b5819ws_C64886.kicad_sym`**, **`b5819ws_C64886.pretty/`**, **`b5819ws_C64886.3dshapes/`** |

Symbol **`usb_type_c_C2765186:TYPE-C16PIN2MD(073)`**; footprint **`usb_type_c_C2765186:USB-C-SMD_TYPE-C-6PIN-2MD-073`**.

Symbol **`rgb_led_C779813:TZ-P4-1615RGBTCA1-0.55T`**; footprint **`rgb_led_C779813:LED-SMD_4P-L1.6-W1.5-BR_TZ-P4-1615`**. EasyEDA labels cathode pins **`2`–`4`** as **`-`** — confirm **R/G/B** vs pad number against the vendor datasheet before layout.

Do **not** merge new LCSC parts into **`easyeda2kicad.kicad_sym`** — add a new **`descriptive_name_C<number>.kicad_sym`** (+ matching **`.pretty`** / **`.3dshapes`**) so **`--overwrite`** on a fresh import cannot wipe unrelated symbols.

## One-time: venv at repo root

From the **repository root**:

```bash
python3 -m venv .venv_easyeda2kicad
./.venv_easyeda2kicad/bin/pip install -r kicad/easyeda2kicad_parts/requirements.txt
```

`.venv_easyeda2kicad/` is **gitignored**.

## Import a part (LCSC `C` number)

**Option A — wrapper script** (creates the venv if missing):

```bash
./scripts/easyeda2kicad_import.sh C2934560
```

**Option B — manual** (use a **dedicated** output prefix so you do not overwrite **`easyeda2kicad.kicad_sym`**):

```bash
source .venv_easyeda2kicad/bin/activate
easyeda2kicad --full --lcsc_id=C2934560 --output kicad/easyeda2kicad_parts/_import_C2934560 --overwrite
```

Then move/rename the generated **`.kicad_sym`**, **`.pretty`**, and **`.3dshapes`** into **`easyeda2kicad/<name>_<Cnumber>/`** (or merge only that symbol by hand if you must). Add **`sym-lib-table`** and **`fp-lib-table`** entries for your KiCad project.

## Notes

- Footprints may embed **absolute** 3D model paths from the machine that ran the import; after clone, fix **`model`** paths in **`.kicad_mod`** or re-run import locally.
- For RF modules, **always** cross-check the footprint and keepout against the **vendor datasheet**; EasyEDA geometry can be wrong or outdated.

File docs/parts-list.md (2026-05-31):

# Parts list

Two sections: **DIY** (Seeed XIAO + BNO08x breakout) and the **Azimuth integrated PCB**. How to wire: [wiring.md](wiring.md). Which firmware: [hardware-profiles.md](hardware-profiles.md).

---

## DIY: Seeed XIAO + BNO08x (wired)

The **wired-only** build (breadboard or hand-wired, power from USB) is fine for **anyone comfortable with a soldering iron** or solderless breadboard.

| Item | Where to buy · notes |
|---|---|
| **Seeed XIAO ESP32-C3** | [Seeed Studio](https://www.seeedstudio.com/Seeed-XIAO-ESP32C3-p-5431.html) · [Mouser **113991054**](https://www.mouser.com/ProductDetail/Seeed-Studio/113991054?qs=3Rah4i%252BhyCHVBerMrpzCkw%3D%3D) — MCU + USB-C. Pinout and docs: [Seeed Wiki — XIAO ESP32-C3](https://wiki.seeedstudio.com/XIAO_ESP32C3_Getting_Started/). |
| **BNO08x breakout (SPI)** | Example modules: [Amazon (GY-BNO085)](https://a.co/d/0f5FjqAz) · [AliExpress listing](https://www.aliexpress.us/item/3256806188033662.html) — strapped for **SPI**; wire **PS0** to **GPIO2** (XIAO **D0**) with **10 kΩ** to **3V3** like **Azimuth_Design** **R14** — full map: [wiring.md](wiring.md). Other **BNO080 / BNO085 / BNO086** breakouts work if you set SPI straps per the vendor. |

Also: breadboard or perfboard, jumper wire, **USB data** cable to the PC.

**Firmware:** **`azimuth_main_diy`** — default on the [web flasher](https://fuglong.github.io/Azimuth/).

### Optional: battery on the XIAO (wireless)

**DIY path only** — there is **no** Azimuth **JST PH** connector on this build.

Soldering a **1S LiPo** to the **battery pads on the back of the XIAO** is the add-on that enables **unplugged / wireless** use (same Wi‑Fi + UDP firmware path; see [power-and-thermal.md](power-and-thermal.md#battery-runtime-planning) for rough runtime). **Recommended for intermediate makers** — the USB-only build above is the approachable path for beginners.

The XIAO includes **charge management**; after you connect the pack correctly, routine charge/discharge is handled on-board. **Match +/− to Seeed’s pad labels** on the XIAO. You can solder leads directly or attach your own **JST-PH** pigtail—**you** are responsible for polarity on those pads. **Never short the battery leads** together (even briefly).

The **JST PH polarity rules** in [Off-board pack (Azimuth PCB)](#off-board-pack-azimuth-pcb-wireless) below apply to the **integrated Azimuth PCB**, not to the XIAO’s solder pads.

---

## Azimuth PCB (`Azimuth_Design`)

**First firmware (USB):** Bare boards from assembly need a one-time flash — [**first-usb-flash.md**](first-usb-flash.md) (copy/paste). After that, [web flasher](https://fuglong.github.io/Azimuth/) or OTA.

**Manufacturing:** **V0.1** — design finalized; **assembled boards received**; **bring-up / testing in progress**. Status: **[roadmap](roadmap.md)**.

Integrated board: **`kicad/Azimuth_Design/`**. Values and footprints below match **`Azimuth.kicad_sch`** / **`Azimuth.kicad_pcb`** in the repo (**ERC/DRC clean** in the current snapshot — re-run both after edits). **Tracked BOM (KiCad CLI):** [`kicad/Azimuth_Design/fab/Azimuth_bom.csv`](../kicad/Azimuth_Design/fab/Azimuth_bom.csv) — regenerate with **`./scripts/export_azimuth_bom.sh`** after schematic edits (that script also refreshes **[`Azimuth_bom_cost.txt`](../kicad/Azimuth_Design/fab/Azimuth_bom_cost.txt)** — **1× board, parts-only USD** ballpark from symbol **`Unit Price (USD)`** or the LCSC table in **`scripts/update_azimuth_sch_bom_fields.py`**). Board workflow: [kicad.md](kicad.md).

To sync **unit prices** onto schematic instances before exporting the BOM: `python3 scripts/update_azimuth_sch_bom_fields.py` (manual snapshot; not live LCSC).

### PCB / assembly quote — “Other Parameters” (PCBWay-style)

Use these for **instant quote** fields that ask for **unique parts**, **SMD**, **BGA/QFP**, and **THT** (you can leave blanks for a manual quote). Numbers match the committed BOM **`fab/Azimuth_bom.csv`** and **`Azimuth.kicad_pcb`** in this repo.

| Form field | Value | Notes |
|---|---|---|
| **Number of Unique Parts** (components) | **33** | Distinct order lines: **32** different **LCSC Part** codes on stuffed lines + **1** line with no LCSC (**IC1** BNO086). |
| **Number of SMD Parts** (tooltip: *SMT Pads*) | **52** |
| **Number of BGA/QFP Parts** (SMT BGA/QFP) | **0** | **IC1** is **LGA**, not BGA/QFP. |
| **Number of Through-Hole Parts** | **0** | All stuffed parts are surface-mount. |

Source of truth: [`fab/README.md`](../kicad/Azimuth_Design/fab/README.md).

### What’s on the board (by reference)

| Qty | Ref | Value / MPN (schematic) | Footprint (project) | Notes |
|-----|-----|---|---|---|
| 1 | **U1** | ESP32-C3-WROOM-02-N4(4MB) | `1_MyFootPrints:BULETM-SMD_ESPRESSIF_ESP32-C3-WROOM-02-N4-4MB` | MCU; USB on module |
| 1 | **IC1** | BNO086 | `Package_LGA:LGA-28_5.2x3.8mm_P0.5mm` | IMU |
| 1 | **U2** | TLV75733PDBVR | `1_MyFootPrints:SOT-23-5_L2.9-W1.6-P0.95-LS2.8-BL` | 3.3 V LDO |
| 1 | **U3** | TP4054_C5381776 | `1_MyFootPrints:SOT-23-5_L2.9-W1.6-P0.95-LS2.8-BR` | Li-ion charger |
| 1 | **J1** | TYPE-C 16PIN 2MD(073) | `1_MyFootPrints:USB-C-SMD_TYPE-C-6PIN-2MD-073` | USB-C |
| 1 | **PH2.0** | S2B-PH-SM4-TB(LF)(SN) | `Connector_JST:JST_PH_S2B-PH-SM4-TB_1x02-1MP_P2.00mm_Horizontal` | Battery |
| 1 | **PWR1** | K3-1280S-K1 | `1_MyFootPrints:SW-SMD_K3-1280S-K1` | Slide switch |
| 1 | **Q1** | LP0404N3T5G | `1_MyFootPrints:SOT-883-3_L1.0-W0.6-BR` | Power path FET |
| 1 | **Q3** | AO3401A | `1_MyFootPrints:SOT-23-3_L2.9-W1.3-P1.90-LS2.4-BR` | Reverse-polarity PMOS on battery input (LCSC **C347476**) |
| 1 | **D1** | MBR0530_C5204746 | `1_MyFootPrints:SOD-123_L2.7-W1.6-LS3.7-RD-1` | Schottky |
| 1 | **F1** | 0805L050WR | `1_MyFootPrints:R0805` | Fuse |
| 1 | **LED1** | TZ-P4-1615RGBTCA1-0.55T | `rgb_led_C779813:LED-SMD_4P-L1.6-W1.5-BR_TZ-P4-1615` | RGB; **COM+** to **3V3** (common anode) |
| 1 | **CHG1** | XL-0201SURC | `1_MyFootPrints:LED-SMD_L0.65-W0.35-P0.41_XL-0201SURC` | Charge indicator LED |
| 1 | **BUZZER1** | MLT-5020 | `1_MyFootPrints:BUZ-SMD_L5.0-W5.5-P4.60` | Passive magnetic buzzer (LCSC **C94598**) — **+**→**3V3**, **−**→**Q2** drain; see [Buzzer (BUZZER1)](#buzzer-buzzer1) |
| 1 | **Q2** | AO3400A | `1_MyFootPrints:SOT-23-3_L2.9-W1.3-P1.90-LS2.4-BR` | Low-side NMOS for **BUZZER1** (LCSC **C20917**); gate from **IO21** via **R20** (same cell as **`ao3400_C20917`** in libs) |
| 1 | **D2** | B5819WS | `1_MyFootPrints:SOD-323_L1.8-W1.3-LS2.5-RD` | Flyback Schottky (LCSC **C64886**) — **cathode**→**3V3**/**BUZZER1 +**, **anode**→drain/**BUZZER1 −** (same cell as **`b5819ws_C64886`** in libs) |
| 1 | **FUNC1** | HX 3X4X2-2P-1.6N TACTILE SWITCH | `1_MyFootPrints:KEY-SMD_L4.0-W3.0-LS4.9-1` | User button |
| 1 | **RST1** | HX 3X4X2-2P-1.6N TACTILE SWITCH | `1_MyFootPrints:KEY-SMD_L4.0-W3.0-LS4.9-1` | Reset / strap (per schematic) |

Exact **LCSC** / **Manufacturer** fields live in the KiCad symbol properties.

### Off-board pack (Azimuth PCB, wireless)

**This section is for the integrated Azimuth PCB only** (`Azimuth_Design`). DIY XIAO users do not get this connector out of the box—they solder to the XIAO or add their own pigtail; the silkscreen and JST rules below are **for the custom PCB**.

The board exposes **JST PH2.0** (**`PH2.0`**) for a **1S** pack when you are not on USB. Use a **protected** cell where possible. Regulation, charging, and the full power path follow **`Azimuth.kicad_sch`** and [wiring.md](wiring.md) (PCB path).

#### Polarity (read this before plugging anything in)

**Adafruit and many other US hobby LiPo packs with JST-PH are wired the opposite way from this PCB.** Do **not** use Adafruit batteries (or any pack that follows the same red/black convention as Adafruit) with the Azimuth **PH2.0** connector—they **will not work** with this layout and **can damage the board or battery** if forced.

Just **behind** the **PH2.0** connector, the PCB silk shows **+** and **−**. The pack’s **red** lead must line up with the **+** marking. If your connector’s red wire would sit on the **−** side, **do not plug it in**—you need a pack wired like our reference vendor below, or you must re-pin / rewire the JST to match.

#### Recommended source and capacity

A known-good match for **JST pinout and polarity** is **YDL Battery** wiring. Example pack (check their site for current stock and specs):

- [**YDL — 3.7 V 800 mAh 802346 LiPo**](https://ydlbattery.com/products/3-7v-800mah-802346-lithium-polymer-ion-battery) — use packs that match **YDL’s** red/black orientation on **JST-PH** relative to the Azimuth **+ / −** silk.

**Capacity:** **~400 mAh to ~900 mAh** is the practical recommended range for this build (runtime vs size on the head). Other capacities can be fine electrically; still verify **JST polarity** against the silk **before** first connect.

**Charge rate:** **U3** (**TP4054**) is set for **~500 mA** via **R4** (**PROG**). Compare that to your cell’s **C** rating and datasheet. Respect **protected** packs and cell quality.

---

### Appendix: resistors (matches `Azimuth.kicad_sch`)

Default footprint for listed **R** parts: **`Resistor_SMD:R_0201_0603Metric`**. Exception: **F1** uses **`1_MyFootPrints:R0805`** (fuse body).

| Ref | Value (KiCad) | Notes |
|-----|---|---|
| **R1** | 220K | Battery divider (tap to **GPIO4** with **R2**) |
| **R2** | 220K | Battery divider (**VBAT_SW** → **GPIO4** tap → **GND**) |
| **R3** | 100k | Power / **U2** support (per schematic nets) |
| **R4** | 2K | **U3** **PROG** — **TP4054**: **I_BAT ≈ 1000 / R4(kΩ) mA** → **~500 mA** |
| **R5** | 150R | **CHG1** LED current limit (**3V3** side) |
| **R6** | 220R | **LED1** blue cathode ↔ **IO3** |
| **R7** | 100R | **LED1** red cathode ↔ **IO1** |
| **R8** | 68R | **LED1** green cathode ↔ **IO0** |
| **R9** | 5.1K | **J1** **CC** (e.g. CC2 branch) |
| **R10** | 5.1K | **J1** **CC** (e.g. CC1 branch) |
| **R11** | 22R | USB data series (**U1** ↔ **J1** **D+** path) |
| **R12** | 22R | USB data series (**U1** ↔ **J1** **D−** path) |
| **R13** | 10k | **IC1** strap (per schematic) |
| **R14** | 10k | **PS0/WAKE** pull-up to **3V3** (**IO2**); shared with Espressif **GPIO2** strap |
| **R15** | 10k | **IC1** **CLKSEL0** pull-up to **3V3** |
| **R16** | 4.7k | **IC1** support (per schematic) |
| **R17** | 4.7k | **IC1** support (per schematic) |
| **R18** | 10k | **U2** / power (per schematic) |
| **R19** | 10k | **U2** / power (per schematic) |
| **R20** | 330R | **IO21** → **Q2** gate (series) |
| **R21** | 100k | **Q2** gate → **GND** (pull-down) |
| **R22** | 100k | **Q3** gate → **GND** (reverse-polarity PMOS bias) |

---

### Appendix: capacitors (matches `Azimuth.kicad_sch`)

Default footprint: **`Capacitor_SMD:C_0201_0603Metric`**.

| Ref | Value (KiCad) | Role (verify nets in schematic) |
|-----|---|---|
| **C1** | 10uf | Battery / switched rail |
| **C2** | 0.1uf | HF bypass |
| **C3** | 100nF | **USB_5V** (post-fuse **VBUS**) HF bypass to **GND** — not the IMU rail |
| **C4** | 2.2uF | Power / **U2** / **U3** branch |
| **C5** | 2.2uF | Power / **U2** branch |
| **C6** | 2.2uF | **U3** / charger branch |
| **C7** | 2.2uF | **U3** / charger branch |
| **C8** | 10uF | Bulk (output / rail per nets) |
| **C9** | 10uf | Bulk (per nets) |
| **C10** | 0.1uf | HF bypass (per nets) |
| **C11** | 100nf | **IC1** **CAP** pin to **GND** |
| **C12** | 100nf | **U2** / rail (per nets) |

---

### Appendix: passives by block

| Block | Refs | Notes |
|---|---|---|
| **BNO086 (IC1)** | **C11** on **CAP**; **3V3** decoupling via shared rail (**C5**, **C9**, **C10**, **C12** per schematic); **R13**–**R17** straps / **ENV** | **R14** 10 kΩ **PS0** (**IO2**); **R15** 10 kΩ **CLKSEL0**; **R16**/**R17** 4.7 kΩ **ENV**; see **`Azimuth.kicad_sch`** |
| **USB-C (J1) / USB_5V** | **C3** 100 nF (**USB_5V** bypass); **R9**, **R10** 5.1 kΩ (**CC**); **R11**, **R12** 22 Ω (data series) | **6-pin** footprint vs 16-pin symbol may produce **DRC** “no pad for pin” on extra **GND** pins — electrically rely on shell / pour if intentional |
| **RGB (LED1)** | **R6**→**IO3** (blue), **R7**→**IO1** (red), **R8**→**IO0** (green) | **COM+** on **3V3** — cathodes **active low**. **`include/azimuth_hw.h`** maps logical R/G/B to these GPIOs (matches V0.1 routing + LED pinout); ballast in **`src/io_led.cpp`** |
| **Charge LED (CHG1)** | **R5** 150 Ω | From **3V3** to **CHG1** anode net |
| **Battery path** | **PH2.0**, **PWR1**, **F1**, **C1**, **C2**, **R1**, **R2** | Divider tap → **IO4** (ADC); **PS0** on **IO2** via **R14** (see [wiring.md](wiring.md)) |
| **3.3 V regulation** | **U2**, **Q1**, **D1**, **R3**, **R18**, **R19**, **C4**, **C5**, **C8**, **C9**, **C10**, **C12** | Exact nets: **`Azimuth.kicad_sch`** |
| **Charging** | **U3**, **R4**, **C6**, **C7** | **R4** = **2 kΩ** on **PROG** → **~500 mA** (see [Off-board pack](#off-board-pack-azimuth-pcb-wireless)) |
| **FUNC1** | Switch to **GND** | Firmware **`INPUT_PULLUP`** on **IO7** |
| **BUZZER1** + **Q2** + **D2** | **BUZZER1 +**→**3V3**, **−**→**Q2** drain; **Q2** source→**GND**; **IO21**→**R20**→gate, **R21** gate→**GND**; **D2** flyback | See [Buzzer (BUZZER1)](#buzzer-buzzer1) |

Long jumper wires on DIY builds: consider series resistors on **SPI** and a stronger **H_INTN** pull-up if needed (SparkFun driver can enable MCU-side pull-up).

---

### Buzzer (BUZZER1)

**MLT-5020** (LCSC **C94598**) is a **magnetic, passive** buzzer: drive it with **PWM** on the switched rail (vary **frequency** for pitch). Coil current can be on the order of **~100 mA** at **3 V** for this family—too much to hang directly on a GPIO.

**Azimuth_Design (`Azimuth.kicad_sch`) — as built**

- **High side:** **BUZZER1** pin **+** → **3V3**; pin **−** → **Q2** (**AO3400A**, LCSC **C20917**) **drain**; **Q2** **source** → **GND**.
- **Flyback:** **D2** **B5819WS** (LCSC **C64886**) — **cathode** (band) → **3V3** / buzzer **+**, **anode** → buzzer **−** / **Q2** drain (same node).
- **Gate drive:** **U1** **IO21** (symbol **TXD**) → **R20** (**330 Ω**) → **Q2** **gate**; **R21** (**100 kΩ**) **gate** → **GND** (default off when the pin is high-Z).

Firmware: **`ledcWriteTone()`** / **LEDC** PWM on **GPIO21** toggles **Q2** and sets the acoustic frequency. Leave **BUZZER1** pin **NC** unconnected unless the datasheet requires otherwise.

**DIY breadboard:** The table above is the **PCB** netlist. A simple **buzzer +** on **D6** with **−** to **GND** is *not* the same as the PCB (no transistor); use a transistor + diode there too if you mirror this design, or accept weak / risky direct drive.

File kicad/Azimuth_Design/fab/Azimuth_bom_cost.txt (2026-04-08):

Azimuth_Design — 1× board, parts-only estimate (USD)

Total (qty-weighted): $16.20
Priced lines: 52 / 52

Ballpark low-qty LCSC / Mouser-class numbers — not live quotes. Excludes PCB fab, assembly, shipping.
Regenerate: ./scripts/export_azimuth_bom.sh

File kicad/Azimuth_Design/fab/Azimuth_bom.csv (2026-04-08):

Refs | Value | Footprint | LCSC Part | Description | Unit Price (USD) | Qty | DNP
BUZZER1 | MLT-5020 | 1_MyFootPrints:BUZ-SMD_L5.0-W5.5-P4.60 | C94598 | Passive magnetic buzzer: PWM via Q2 low-side switch | 0.4246 | 1
C1 | 10uf | Capacitor_SMD:C_0402_1005Metric | C315248 | VBAT bulk after switch: local energy for TX bursts | 0.0087 | 1
C2 | 0.1uf | Capacitor_SMD:C_0402_1005Metric | C60474 | VBAT switched rail HF bypass at divider / switch node | 0.001 | 1
C3 | 100nf | Capacitor_SMD:C_0201_0603Metric | C76934 | USB_5V (post-fuse VBUS) HF bypass to GND | 0.002 | 1
C4 | 2.2uf | Capacitor_SMD:C_0201_0603Metric | C335106 | Bypass: LDO input / charger adjacent 2.2 µF ceramic (0201) | 0.0212 | 1
C5 | 2.2uf | Capacitor_SMD:C_0201_0603Metric | C335106 | ESP32-C3 module / 3V3 rail local bypass (per placement) | 0.0212 | 1
C6 | 2.2uf | Capacitor_SMD:C_0201_0603Metric | C335106 | TP4054 VCC bypass | 0.0212 | 1
C7 | 2.2uf | Capacitor_SMD:C_0201_0603Metric | C335106 | TP4054 BAT pin stability / output cap per reference design | 0.0212 | 1
C8 | 10uf | Capacitor_SMD:C_0402_1005Metric | C315248 | LDO input or output bulk (per schematic net) | 0.0087 | 1
C9 | 10uf | Capacitor_SMD:C_0402_1005Metric | C315248 | 3V3 bulk decoupling | 0.0087 | 1
C10 | 0.1uf | Capacitor_SMD:C_0402_1005Metric | C60474 | 3V3 / LDO output HF decoupling | 0.001 | 1
C11 | 100nf | Capacitor_SMD:C_0201_0603Metric | C76934 | BNO086 CAP pin bypass to GND (datasheet requirement) | 0.002 | 1
C12 | 100nf | Capacitor_SMD:C_0201_0603Metric | C76934 | LDO / 3V3 bypass (per net) | 0.002 | 1
CHG1 | XL-0201SURC | 1_MyFootPrints:LED-SMD_L0.65-W0.35-P0.41_XL-0201SURC | C3646923 | Charge-state LED (TP4054 CHRG) — 0201 red | 0.069 | 1
D1 | MBR0530_C5204746 | 1_MyFootPrints:SOD-123_L2.7-W1.6-LS3.7-RD-1 | C5204746 | Schottky (30 V / 0.5 A class): ORing / clamp in VBAT–LDO path with Q1 per schematic | 0.0193 | 1
D2 | B5819WS | 1_MyFootPrints:SOD-323_L1.8-W1.3-LS2.5-RD | C64886 | Passive buzzer flyback Schottky: cathode to 3V3/+buzzer, anode to Q2 drain | 0.0217 | 1
F1 | 0805L050WR | 1_MyFootPrints:R0805 | C207022 | PTC resettable fuse ~500 mA hold on battery feed (matches charge budget) | 0.1119 | 1
FUNC1 | HX 3X4X2-2P-1.6N TACTILE SWITCH | 1_MyFootPrints:KEY-SMD_L4.0-W3.0-LS4.9-1 | C49234124 | User button: FUNC to GND, IO7 with internal pull-up | 0.0186 | 1
IC1 | BNO086 | Package_LGA:LGA-28_5.2x3.8mm_P0.5mm |  | 9-axis fusion IMU (accel/gyro/mag); SPI to ESP32; straps per schematic | 11.50 | 1
J1 | TYPE-C 16PIN 2MD(073) | 1_MyFootPrints:USB-C-SMD_TYPE-C-6PIN-2MD-073 | C2765186 | USB-C receptacle: VBUS, GND, D+/D− (6-pin footprint) | 0.0649 | 1
LED1 | TZ-P4-1615RGBTCA1-0.55T | rgb_led_C779813:LED-SMD_4P-L1.6-W1.5-BR_TZ-P4-1615 | C779813 | 1615 RGB common-anode: cathodes via R6–R8; active-low drive on IO0/1/3 | 0.0244 | 1
PH2.0 | S2B-PH-SM4-TB(LF)(SN) | Connector_JST:JST_PH_S2B-PH-SM4-TB_1x02-1MP_P2.00mm_Horizontal | C295747 | 1S LiPo JST-PH battery connector (horizontal SMD) | 0.1947 | 1
PWR1 | K3-1280S-K1 | 1_MyFootPrints:SW-SMD_K3-1280S-K1 | C128953 | Slide switch: battery disconnect / power control | 0.1791 | 1
Q1 | LP0404N3T5G | 1_MyFootPrints:SOT-883-3_L1.0-W0.6-BR | C172433 | Power OR / ideal-diode style switch: VBAT vs VUSB path into LDO input | 0.0267 | 1
Q2 | AO3400A | 1_MyFootPrints:SOT-23-3_L2.9-W1.3-P1.90-LS2.4-BR | C20917 | NMOS low-side: PWM buzzer − terminal; Id rating >> buzzer current | 0.0798 | 1
Q3 | AO3401A | 1_MyFootPrints:SOT-23-3_L2.9-W1.3-P1.90-LS2.4-BR | C347476 | PMOS reverse-polarity protection on battery input: source from JST+, drain to VBAT rail | 0.0311 | 1
R1 | 220k | Resistor_SMD:R_0402_1005Metric | C25767 | Battery divider high side: VBAT_SW to ADC tap on IO4 (with R2) | 0.0007 | 1
R2 | 220k | Resistor_SMD:R_0402_1005Metric | C25767 | Battery divider low side: VBAT_SW tap to IO4 for ADC (with R1) | 0.0007 | 1
R3 | 100k | Resistor_SMD:R_0201_0603Metric | C106224 | Power path bias / discharge (Q1 gate network per schematic) | 0.001 | 1
R4 | 2K | Resistor_SMD:R_0201_0603Metric | C327392 | TP4054 PROG: sets IBAT ≈ 500 mA (1000/R_kΩ mA) | 0.0011 | 1
R5 | 150R | Resistor_SMD:R_0201_0603Metric | C295773 | CHG1 current limit: red charge indicator from 3V3 | 0.0011 | 1
R6 | 220R | Resistor_SMD:R_0201_0603Metric | C49654383 | RGB LED blue cathode resistor (IO3); tuned with R7/R8 for TZ-P4-1615RGBTCA1 balance on 3V3 | 0.0006 | 1
R7 | 100R | Resistor_SMD:R_0201_0603Metric | C77623 | RGB LED red cathode resistor (IO0) | 0.0011 | 1
R8 | 68R | Resistor_SMD:R_0201_0603Metric | C49655823 | RGB LED green cathode resistor (IO1) | 0.001 | 1
R9 | 5.1k | Resistor_SMD:R_0201_0603Metric | C274341 | USB-C CC1 pulldown (Rd) | 0.0011 | 1
R10 | 5.1k | Resistor_SMD:R_0201_0603Metric | C274341 | USB-C CC2 pulldown (Rd) for default current advertisement | 0.0011 | 1
R11 | 22R | Resistor_SMD:R_0201_0603Metric | C155743 | USB D+ series resistor between module and connector | 0.0011 | 1
R12 | 22R | Resistor_SMD:R_0201_0603Metric | C155743 | USB D− series resistor between module and connector | 0.0011 | 1
R13 | 10k | Resistor_SMD:R_0201_0603Metric | C106225 | BNO086 strap (NRST/BOOT network per schematic) | 0.0011 | 1
R14 | 10k | Resistor_SMD:R_0201_0603Metric | C106225 | PS0/WAKE pull-up to 3V3 on IO2 (BNO086 SPI strap + ESP32 GPIO2) | 0.0011 | 1
R15 | 10k | Resistor_SMD:R_0201_0603Metric | C106225 | BNO086 CLKSEL0 pull-up to 3V3 | 0.0011 | 1
R16 | 4.7k | Resistor_SMD:R_0201_0603Metric | C138135 | BNO086 strap / support network (per schematic) | 0.001 | 1
R17 | 4.7k | Resistor_SMD:R_0201_0603Metric | C138135 | BNO086 strap / support network (per schematic) | 0.001 | 1
R18 | 10k | Resistor_SMD:R_0201_0603Metric | C106225 | Power control: TLV75733 EN / divider network (see schematic nets) | 0.0011 | 1
R19 | 10k | Resistor_SMD:R_0201_0603Metric | C106225 | Power control: TLV75733 EN / divider network (see schematic nets) | 0.0011 | 1
R20 | 330R | Resistor_SMD:R_0201_0603Metric | C274872 | Q2 gate series resistor: limits inrush / EMI from IO21 | 0.0011 | 1
R21 | 100k | Resistor_SMD:R_0201_0603Metric | C106224 | Q2 NMOS gate discharge to GND (default buzzer off) | 0.001 | 1
R22 | 100k | Resistor_SMD:R_0201_0603Metric | C106224 | Q3 PMOS gate pull-down to GND: keeps reverse-protection FET enhanced with correct battery polarity | 0.001 | 1
RST1 | HX 3X4X2-2P-1.6N TACTILE SWITCH | 1_MyFootPrints:KEY-SMD_L4.0-W3.0-LS4.9-1 | C49234124 | Tactile: strap / reset function per schematic | 0.0186 | 1
U1 | ESP32-C3-WROOM-02-N4(4MB) | 1_MyFootPrints:BULETM-SMD_ESPRESSIF_ESP32-C3-WROOM-02-N4-4MB | C2934560 | MCU + RF: Wi-Fi/BLE, USB-OTG PHY, 4 MB flash; Azimuth GPIO map per wiring.md | 3.0674 | 1
U2 | TLV75733PDBVR | 1_MyFootPrints:SOT-23-5_L2.9-W1.6-P0.95-LS2.8-BL | C485517 | 3.3 V LDO: up to ~1 A out, low IQ; feeds digital + RF rail | 0.1959 | 1
U3 | TP4054_C5381776 | 1_MyFootPrints:SOT-23-5_L2.9-W1.6-P0.95-LS2.8-BR | C5381776 | Linear Li-ion charger from USB_5V; CC/CV, ~500 mA with R4 | 0.0145 | 1

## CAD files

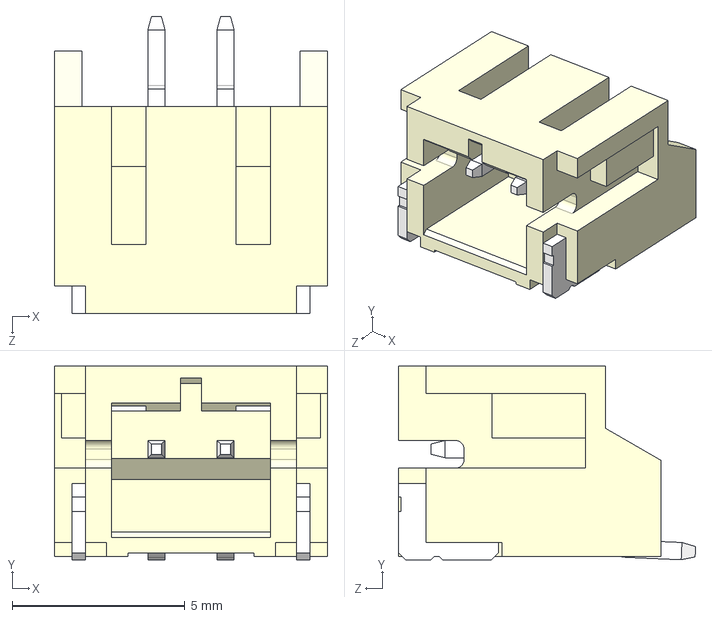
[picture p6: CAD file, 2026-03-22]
kicad/3d/S2B-PH-SM4-TB.STEP
7.90 x 5.60 x 8.60 mm

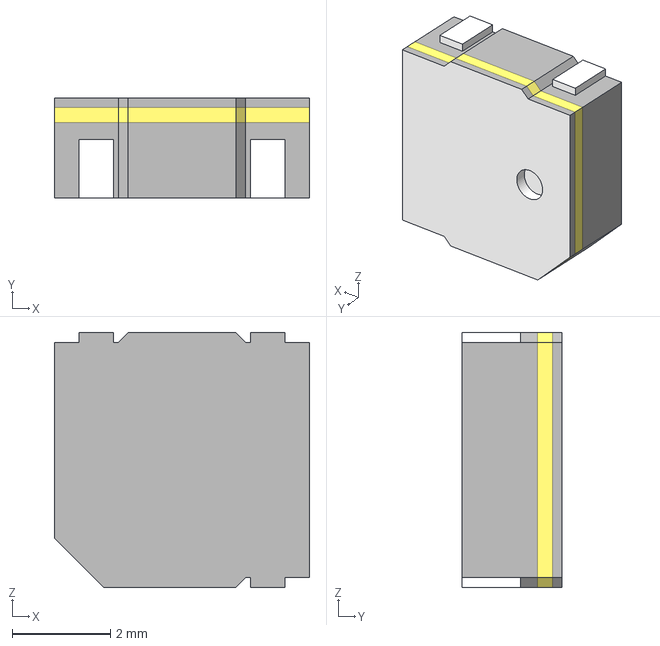
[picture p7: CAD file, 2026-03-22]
kicad/3d/SMT-0540-T-9-R.STEP
5.20 x 2.05 x 5.20 mm

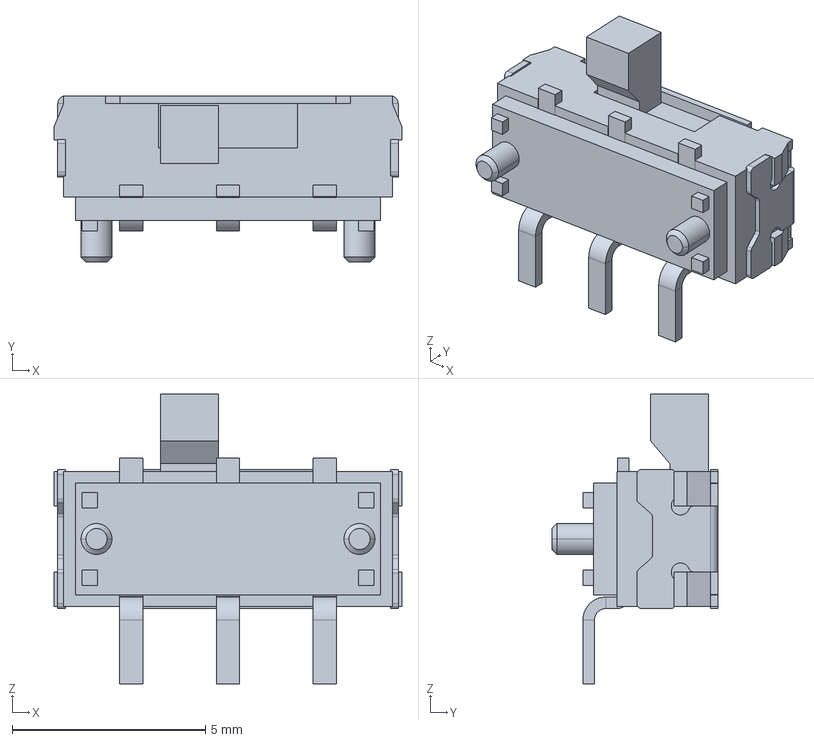
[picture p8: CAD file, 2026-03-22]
kicad/3d/JS102011SAQN.STEP
9.00 x 4.30 x 7.50 mm

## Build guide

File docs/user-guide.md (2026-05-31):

# Azimuth User Guide

This is the **manual for using** Azimuth: Wi‑Fi setup, OpenTrack, the on-device web UI, the FUNC button, updates, and battery behavior. You do **not** need PlatformIO or the source code to follow it.

**Ultra-short path:** [quickstart.md](quickstart.md)  
**Deeper reference** (same topics, more detail): [using-azimuth.md](using-azimuth.md)  
**Builders / firmware from source:** [development.md](development.md)

---

## Two hardware versions

| Version | What it is |
|---|---|
| **DIY** | Seeed **XIAO ESP32‑C3** + **BNO08x** breakout (breadboard or hand-wired). Default in the web installer. |
| **Azimuth PCB** | Integrated board ([KiCad project](../kicad/Azimuth_Design/)) with RGB LED, **FUNC** button, buzzer, and **JST** for a LiPo. |

The **same tracking firmware** runs on both where features overlap. The DIY build may use a simple **status LED** instead of RGB; the PCB has full **sound and light** feedback.

---

## What you need

| Item | Why |
|---|-----|
| A **PC** running **OpenTrack** | Receives head tracking over **UDP** (Wi‑Fi) or **USB Hatire**. |
| **Chrome** or **Edge** | Required for the **USB web flasher** (Web Serial). |
| Your **Wi‑Fi** name and password | Stored only on the device. |
| Optional: **1S LiPo** (PCB or DIY pads) | Untethered use; see **Battery** below and [parts-list.md](parts-list.md). |

---

## 1. Install firmware over USB (first time or recovery)

1. Open the **Azimuth web flasher**: [https://fuglong.github.io/Azimuth/](https://fuglong.github.io/Azimuth/)
2. Connect the board with a **data** USB cable.
3. Choose **DIY** or **Custom PCB** to match your hardware, then install.

**Azimuth custom PCB, straight from assembly with no firmware:** the **web flasher usually will not work** for that **very first** flash. Follow [**First-time USB flash**](first-usb-flash.md) (copy/paste commands). After that, use the web flasher or **OTA** like everyone else.

---

## 2. Connect the board to your home Wi‑Fi

Do this once (or whenever you change networks).

1. Power the board.
2. On your **phone or PC**, join the Wi‑Fi network **`Azimuth-Tracker`** (this is **Offline / setup mode**).
3. A setup page may open automatically. If not, open **`http://192.168.4.1/`** in a browser (port **80** — no `:8080` here).
4. Enter your **home Wi‑Fi name** and **password**.
5. **Scroll down** and **save**. The board reboots and joins your network.

If it cannot connect (wrong password, weak signal), it will come back to **`Azimuth-Tracker`** so you can fix credentials without re-flashing.

---

## 3. Open the settings portal (after Wi‑Fi works)

Use the portal to set **UDP address**, **axis mapping**, **sound/light**, and more.

| Situation | Open in your browser |
|---|---|
| Board on **home Wi‑Fi** | `http://azimuth.local:8080` or `http://192.168.x.x:8080` (router/device IP) |
| **Offline mode** (you are connected to **`Azimuth-Tracker`**) | **`http://192.168.4.1/`** on port **80** |

Important:

- **`azimuth.local` only works on your LAN** after the device has joined your router — not while you are connected only to **`Azimuth-Tracker`**.
- The portal on home Wi‑Fi uses port **`:8080`**. Forgetting it is a common mistake.
- **Windows:** If **`.local`** never resolves, install **Bonjour** (e.g. Apple Bonjour Print Services) or use the device **IP** from your router’s admin page.
- **Guest Wi‑Fi** or client isolation often blocks phone ↔ PC discovery — use the printed IP if needed.

---

## 4. Tell the tracker where OpenTrack runs

Do this on the **same PC** that runs OpenTrack, while that PC is on the **same home Wi‑Fi** as the board.

1. Open `http://azimuth.local:8080` (or `http://192.168.x.x:8080` using the board’s IP).
2. Enable **UDP to PC** if it is off.
3. Click **Fill address** if the button appears (it fills this PC’s LAN IPv4). Otherwise type your PC’s IPv4 (often `192.168.x.x`).
4. **Save** at the bottom of the page.

---

## 5. OpenTrack on the PC

Use **either** UDP **or** USB Hatire — **not both at once**.

### Wi‑Fi (usual)

1. Input: **UDP over network** (wording may vary by OpenTrack version).
2. Port: match the **UDP port** in the portal (default **4242** unless you changed it).
3. On **Windows**, allow the port through the firewall if prompted.
4. Click **Start** in OpenTrack, then **Center** / **recenter** after motion stabilizes.

### USB (Hatire)

1. In the portal you can enable **USB Hatire** and disable UDP if you want a wired-only path.
2. In OpenTrack, choose **Hatire Arduino**: **115200** baud, **DTR** on.
3. Do **not** leave a **serial monitor** open on the same COM port while OpenTrack is using it.

**Axis mapping:** Portal settings for **Rot 0–2** apply to **both** UDP and Hatire. Match OpenTrack’s expectations to those slots.

---

## 6. Physical controls (Azimuth PCB)

The **FUNC** button is the round tact switch on the board (**GPIO7**, active low).

| Gesture | Action |
|---|---|
| **Single tap** | Toggles **Pause** (see below). |
| **Double tap** | Reserved — no action. |
| **Long press (~2 s)** | Starts **wireless firmware update** (see **Updates**). You hear a short rising tune when the download begins; a normal tap is **not** counted for that gesture. |

**DIY builds** without FUNC ignore this section.

---

## 7. Pause (FUNC single tap)

**Pause** stops sending pose data to OpenTrack over **UDP** and **USB Hatire** until you tap again. It is meant for breaks without powering down.

- Pause is **session-only** (not saved permanently).
- You get **different buzzer cues** when entering vs leaving pause.
- The LED shows a **clear “paused” pattern** (depends on DIY vs RGB hardware).

**When pause or FUNC may not respond**

- **Severe overheating** — firmware may force Wi‑Fi off for safety; pause state is cleared as part of that.
- **Battery at about 1% or below** (with a battery connected) — FUNC **does not toggle** pause, to avoid trapping you in a bad state.
- While a **wireless update** is running, normal tap behavior is suppressed for that gesture.

---

## 8. Lights and sounds (overview)

Exact patterns depend on **DIY vs PCB**. In general:

- **Normal tracking** — Status LED or RGB “ambient” pattern from your **Sound & light** settings.
- **Pause** — Distinct slow blink / cyan-style pulse on RGB boards.
- **Wireless update** — Fast **cyan** throb (or fast blink on LED-only builds); start / success / failure tunes on PCB.
- **Thermal warning** — Firmware reduces radio activity to cool down; LED shows a **thermal** pattern until recovered.
- **Low battery** — Escalating cues (tones and LED overrides); see **Battery**.

Details for RGB mapping and buzzer motifs: [io-led-buzzer-plan.md](io-led-buzzer-plan.md).

---

## 9. Firmware updates

### How you know an update exists

On **home Wi‑Fi**, after the board connects, firmware checks the official **`manifest.json`** on GitHub Pages **about once per boot**. If the published **version** is **newer** than what runs on the chip, the portal shows a **yellow banner** (and the **Device** section shows version info).

### Two ways to update

| Method | When to use |
|---|---|
| **Install over Wi‑Fi** (portal button) or **FUNC long-press** | Convenient when the board already has internet via your router. |
| **USB web flasher** ([same URL as install](https://fuglong.github.io/Azimuth/)) | Custom builds, bad Wi‑Fi, bricked networking, or you want a full erase. |

The board downloads the **official release** matching your hardware (**DIY** vs **PCB**) from the **same GitHub Pages site** the banner trusts. Transport is **HTTPS** with a **pinned certificate authority** (see maintainer docs — this is **not** the same as “signed firmware” inside the image; image signing is a possible future hardening step).

### When wireless install is **blocked**

Wireless update **does not start** if:

- You are in **Offline mode** / device AP only (**no route to the internet**).
- **Thermal protection** has shut down Wi‑Fi.
- **Battery is at 15% or below** and the board is **not** on USB power — flashing while the cell browns out could brick the device.

If wireless update fails, you still have the **USB flasher**.

---

## 10. Battery and charging

### What the percentage means

The device estimates **state of charge** from battery voltage (with smoothing and noise rejection). It is an **estimate**, not a lab coulomb counter.

In the portal **Device** section you can set:

- **Pack capacity (mAh)** — improves remaining‑time style readouts.
- **Calibration offset** — fine‑tune voltage reading for your pack.

If no battery is detected (USB‑only), telemetry may show **absent** / unsupported states depending on hardware.

### Alerts (typical behavior)

As charge drops, firmware plays **stepped low‑battery cues** (buzzer on PCB). Crossing thresholds near **25%, 15%, 10%, 5%… down to 1%** escalates urgency.

**Below ~1%** (with a battery present): panic‑style cues repeat; firmware may **shut down Wi‑Fi** to protect the system — **plug in USB** to recover.

### Wireless updates and battery

Wireless OTA is **refused** at **≤15%** unless **USB** provides power — plug in before updating.

### PCB LiPo connector

**Polarity and connector type matter.** Wrong packs or reversed JST wiring can damage the board. Follow [parts-list.md → Off-board pack](parts-list.md#off-board-pack-azimuth-pcb-wireless).

---

## 11. Power, heat, and Wi‑Fi tuning

The ESP32‑C3 feels **warm** when Wi‑Fi is active — that is normal on a small module.

In the portal **Tracking & radio**:

- **Wi‑Fi TX power** — lower can reduce heat and current; higher helps marginal signal.
- **IMU report interval** — affects how often orientation updates (smoothness vs load); changing it requires **reboot**.

Full detail: [power-and-thermal.md](power-and-thermal.md).

---

## 12. Troubleshooting

| Problem | Things to try |
|---|---|
| **`azimuth.local` fails** | Use `http://192.168.x.x:8080`. Windows: install Bonjour or copy IP from router DHCP list. |
| **Portal won’t load on home Wi‑Fi** | Confirm **`:8080`**, same LAN as the PC, firewall not blocking. Ping or check router client list. |
| **Stuck in setup Wi‑Fi** | Rejoin **`Azimuth-Tracker`**, open **`http://192.168.4.1`**, fix SSID/password. |
| **OpenTrack gets no motion** | UDP: PC IP/port match portal; Windows firewall; only one input (UDP **or** Hatire). Hatire: correct COM, DTR on, no serial monitor on same port. |
| **Tracking feels wrong** | **Recenter** in OpenTrack; check **axis mapping** in portal vs OpenTrack filter pipeline. |
| **Update banner but Wi‑Fi install won’t start** | Plug into USB if battery low; ensure not in Offline AP; cool down if overheated. Use USB flasher if needed. |

---

## 13. Enclosure (3D-printed shell)

The **integrated PCB** can mount in a **3D-printed enclosure** (battery-friendly internal volume). Open the model on **Onshape** to rotate, measure, or export for printing: [Azimuth enclosure](https://cad.onshape.com/documents/fa78666ff0e219ba32d45d9f/w/679625cc5ba48f8e098cba83/e/0cd4f9cad8e872128d491b46).

---

## 14. Related documentation

| Doc | Contents |
|-----|---|
| [quickstart.md](quickstart.md) | Shortest Wi‑Fi → OpenTrack path |
| [using-azimuth.md](using-azimuth.md) | Portal sections, RGB pins, extra detail |
| [power-and-thermal.md](power-and-thermal.md) | Modem sleep, portal polling, deep battery notes |
| [parts-list.md](parts-list.md) | BOM, LiPo sourcing, polarity |
| [README.md](../README.md) | Project overview and doc index |

---

*Azimuth is a DIY / open head tracker for [OpenTrack](https://github.com/opentrack/opentrack). No cloud account is required; configuration stays on your LAN and the device.*

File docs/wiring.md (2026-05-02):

# Wiring and pinout

GPIO and nets follow **`kicad/Azimuth_Design/Azimuth.kicad_sch`**; this page and **`include/azimuth_hw.h`** match that project.

Assignments match **`include/azimuth_hw.h`**. PlatformIO environments: [**hardware-profiles.md**](hardware-profiles.md).

Pinout is split into **two paths** below—follow **either** the DIY (XIAO) section **or** the PCB (U1) section; they describe the same GPIO map in the form you need for that build.

---

## DIY path: Seeed XIAO + BNO08x breakout

For a **breadboard or hand-wired** setup: **Seeed XIAO ESP32-C3** + **BNO08x** breakout in **SPI** mode. Flash **`azimuth_*_diy`**. USB to the PC is the XIAO’s USB-C.

### XIAO pins (D → GPIO)

Per Seeed’s [XIAO ESP32-C3 pin map](https://wiki.seeedstudio.com/XIAO_ESP32C3_Getting_Started/).

| XIAO | GPIO | Typical use in Azimuth |
|---|---|---|
| D0 | **2** | **PS0 / WAKE** — wire to IMU **PS0**; add **10 kΩ** to **3V3** (same as **Azimuth_Design** **R14** on **IO2**) |
| D1 | **3** | — |
| D2 | **4** | Battery divider tap if you add a sense network (same net as **Azimuth_Design** **IO4**) |
| D3 | **5** | IMU CS |
| D4 | **6** | IMU INT |
| D5 | **7** | FUNC (optional tact switch) |
| D6 | **21** | Buzzer drive / **TXD** (optional); on **PCB**, **IO21** → FET gate — not buzzer **+**; also UART TX |
| D7 | **20** | IMU NRST; same pin as UART RX—do not use both |
| D8 | **8** | SPI SCK |
| D9 | **9** | SPI MISO |
| D10 | **10** | SPI MOSI |

**Strapping:** On ESP32-C3, **GPIO2**, **GPIO8**, and **GPIO9** can affect boot. **DIY** matches the PCB pin plan (**PS0** on **GPIO2**, battery sense on **GPIO4**). **D8–D10** are SPI—keep IMU power/straps valid at reset.

### IMU breakout → XIAO

Map breakout pins by **function** (your silk may differ from **BNO086** names):

| IMU function | GPIO | XIAO | `azimuth_hw.h` |
|---|---|---|---|
| CS | 5 | D3 | `kPinImuCs` |
| INT | 6 | D4 | `kPinImuInt` |
| NRST | 20 | D7 | `kPinImuRst` |
| PS0 / WAKE | 2 | D0 | `kPinImuPs0Wake` — **10 kΩ** to **3V3** recommended (matches **R14** on PCB) |
| SCK / MISO / MOSI | 8 / 9 / 10 | D8 / D9 / D10 | FSPI |
| VDD, VDDIO, PS1 | — | 3V3 | SPI straps (see breakout doc) |
| GND | — | GND | |

Arduino **FSPI** defaults match **D8 / D9 / D10** on this XIAO. Tie **PS0** / **PS1** per your breakout’s datasheet (often **3.3 V** for SPI).

If you use different pins for SPI, call **`SPI.begin(sck, miso, mosi, -1)`** before **`imu.beginSPI(...)`**.

**Optional on breadboard:** tact switch **D5** (GPIO7). A buzzer on **D6** (GPIO21) is only **pin-compatible** with the PCB net name—the **integrated PCB** drives a **low-side FET** gate from **IO21**, not the buzzer **+** directly; see [PCB path](#pcb-path-azimuth_design-u1-esp32-c3-wroom-02) and [parts-list — Buzzer](parts-list.md#buzzer-buzzer1). There is no Azimuth-style RGB on the default DIY path.

---

## PCB path: Azimuth_Design (U1 ESP32-C3-WROOM-02)

For the integrated PCB: schematic **U1** is **`ESP32-C3-WROOM-02`** (e.g. **-N4**). Flash **`azimuth_*_pcb`**. Route **BNO086** and peripherals by **GPIO number** and **U1 symbol pin names** in **`Azimuth.kicad_sch`**—**not** by XIAO **D** labels (the module does not have those).

### BNO086 (IC1) ↔ U1

| BNO086 signal | U1 symbol pin | GPIO |
|---|---|---|
| **H_CSN** (CS) | **IO5** | 5 |
| **H_INTN** | **IO6** | 6 |
| **NRST** | **RXD** (UART0 RX) | 20 |
| **PS0/WAKE** | **IO2** | 2 |
| **H_SCL / SCK** | **IO8** | 8 |
| **H_SDA / MISO** | **IO9** | 9 |
| **SA0 / H_MOSI** | **IO10** | 10 |
| **VDD**, **VDDIO**, **PS1** | **3V3** | — |
| **GND** | **GND** | — |

On the board, **IC1** is the bare **BNO086**; **`Azimuth.kicad_sch`** shows straps and passives (**R13**–**R17**, **C11** on **CAP**, shared **3V3** bypass, etc.).

### Other nets ↔ U1

| Function | U1 symbol | GPIO | Notes |
|---|---|---|---|
| RGB **LED1** cathodes (via **R6** / **R7** / **R8**); **COM+** → **3V3** | **IO0** (R8 green), **IO1** (R7 red), **IO3** (R6 blue) | 0, 1, 3 | **TZ-P4-1615RGB** — **common anode**; **firmware** maps logical R→**IO1**, G→**IO0**, B→**IO3** (LED pinout vs ref-des on V0.1) |
| **FUNC1** | **IO7** | 7 | Tact to GND; firmware pull-up |
| **Buzzer (PWM)** | **TXD** | 21 | **IO21** → **R20** (330 Ω) → **Q2** (**AO3400A**) gate; **R21** (100 kΩ) gate → **GND** |
| **BUZZER1** + **Q2** + **D2** | — | — | **MLT-5020**: **+**→**3V3**, **−**→**Q2** drain; **Q2** source→**GND**; **D2** **B5819WS** flyback (**K**→**3V3**/**+**, **A**→drain/**−**) — [parts-list — Buzzer](parts-list.md#buzzer-buzzer1) |
| Battery divider tap | **IO4** | 4 | **R1**/**R2** (220 kΩ each), **`VBAT_SW`** → tap → **GND** per **`Azimuth.kicad_sch`**; **DIY:** same GPIO (**D2** on XIAO) (**GPIO4** is **not** a strapping pin) |

### Strap pins (ESP32-C3-WROOM-02)

Per the **ESP32-C3-WROOM-02** datasheet (*Boot configurations*, Table 4-3), **GPIO2**, **GPIO8**, and **GPIO9** set **chip boot mode** at reset. Strapping is **latched** when **`CHIP_EN`** rises; pins then behave as normal GPIO. Default pin bias (Table 4-1): **GPIO9** has a **weak internal pull-up** (reads **1** if nothing else dominates); **GPIO2** and **GPIO8** default **floating**.

| Boot mode | GPIO2 | GPIO8 | GPIO9 |
|---|---|---|---|
| **SPI boot** (run from flash) | **1** | any | **1** |
| **Joint download boot** (UART0 / USB-Serial-JTAG) | **1** | **1** | **0** |

The same chapter notes that **GPIO2** does **not** choose between SPI boot and joint download (that is **GPIO8**/**GPIO9**), but **Espressif still recommends pulling GPIO2 up** to reduce glitch sensitivity. For **ROM message printing** to UART0, **GPIO8** also participates (see Table 4-4 in the datasheet); default eFuse settings usually match “normal” development expectations.

**How this maps on Azimuth**

- **GPIO9** (**SPI MISO** / **`/IO9`**) — Table 4-3 requires **1** for **SPI boot**. The chip’s **weak pull-up** on **GPIO9** usually wins when the IMU tri-states **MISO** with **CS** deasserted; that matches typical SPI flash boot.
- **GPIO8** (**SPI SCK** / **`/IO8`**) — For **SPI boot**, **GPIO8** may be **any** level; your IMU strapping and SPI idling are consistent with **not** forcing joint download by accident (avoid **GPIO8 = 0** together with **GPIO9 = 0**, which the datasheet calls **invalid** for some modes).
- **GPIO2** (**PS0/WAKE** + pull-up) — **`Azimuth.kicad_sch`** uses **R14** (**10 kΩ**) to **3V3**; breadboard **DIY** should duplicate that on **D0**. Battery sense is on **GPIO4** (**D2** on XIAO), not a strapping pin.

**USB:** Data on **GPIO18** / **GPIO19** inside the module to the USB pads—no separate USB-UART IC. Firmware uses **USB CDC** for **`Serial`**.

**Power / reset:** **EN** RC per Espressif; **3V3** / **GND** decoupling per **`Azimuth.kicad_sch`** and [ESP32-C3 hardware design guidelines](https://www.espressif.com/sites/default/files/documentation/esp32-c3_hardware_design_guidelines_en.pdf). Follow the WROOM-02 datasheet for **BOOT** / strap pins. **Antenna:** keep the module RF keepout clear.

### Battery (PCB)

**JST PH2.0**, slide switch **PWR1**, switched rail, divider **R1**/**R2** to **IO4** (ADC), bulk **C1**, bypass **C2**—exact nets in **`Azimuth.kicad_sch`**. Regulation and charging follow the schematic. Charger **U3** (**TP4054**) uses **R4** = **2 kΩ** on **PROG** for **~500 mA** charge current; battery pack, **JST polarity**, and charge notes: [parts-list — Off-board pack](parts-list.md#off-board-pack-azimuth-pcb-wireless).

### Schematic passives (`Azimuth.kicad_sch`)

Summary for bring-up; full tables match **`Azimuth.kicad_sch`** in [**parts-list.md**](parts-list.md).

| Block | Refs | Role |
|---|---|---|
| **USB-C J1** | **R9**, **R10** 5.1 kΩ (**CC**); **R11**, **R12** 22 Ω (USB data series **U1** ↔ **J1**) | |
| **U1** | Decoupling per schematic (e.g. **C5** and related nets) | See KiCad |
| **IC1** BNO086 | **C11** 100 nF on **CAP**; **3V3** rail caps per schematic (**C5**, **C9**, **C10**, **C12**); **R13** 10 kΩ; **R14** 10 kΩ (**PS0** on **IO2**); **R15** 10 kΩ (**CLKSEL0**); **R16**/**R17** 4.7 kΩ (**ENV**) | |
| **LED1** RGB | **R6** 220 Ω → **IO3** blue, **R7** 100 Ω → **IO1** red, **R8** 68 Ω → **IO0** green; **R5** 150 Ω is **CHG1**, not RGB | |
| **Charger / charge LED** | **U3** **TP4054**, **R4** 2 kΩ (**PROG**, **~500 mA**), **CHG1**, **R5**, **C6**, **C7** | |
| **Battery path** | **C1** 10 µF, **C2** 0.1 µF, **R1**/**R2** 220 kΩ divider | |
| **Buzzer** | **R20** 330 Ω (**IO21**→gate), **R21** 100 kΩ (gate→**GND**); **Q2** **AO3400A**; **D2** **B5819WS**; **BUZZER1** **MLT-5020** | |

---

## Bring-up

1. IMU: **PS1** and rails at **3.3 V**, **PS0** high at reset, **BOOTN** high, **CLKSEL0** high, **CAP** bypassed (**C11** on PCB per **`Azimuth.kicad_sch`**).
2. Short SPI traces; solid GND return.
3. Run **`azimuth_debug_diy`** or **`azimuth_debug_pcb`** to match your hardware; then **`azimuth_main_*`** for Wi‑Fi / OpenTrack.
4. If init fails: **3.3 V**, **NRST**, **INT**, SPI wiring; on PCB, confirm the built board matches **`Azimuth.kicad_sch`** / layout (re-run **ERC** / **DRC** in KiCad if you changed the design).

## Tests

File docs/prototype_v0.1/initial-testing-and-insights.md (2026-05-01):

# Prototype V0.1 Initial Testing and Insights

## Scope
This note captures first-article bring-up observations for the `Azimuth_Design` custom PCB (`ESP32-C3-WROOM-02`) and immediate actions to get prototype units flashable and testable.

## Current Observations
- No shorts found during continuity check.
- Board powers without obvious overcurrent or heating.
- Buzzer repeats a deterministic rhythm and charge LED flashes in sync.
- Mac enumerates device as Espressif native USB:
  - `USB JTAG/serial debug unit`
  - `/dev/cu.usbmodem1101`
  - VID/PID `0x303A/0x1001`

Interpretation: the MCU and USB PHY are alive. This is not a dead-board signature.

## Most Likely Root Cause (V0.1)
Boot/download strap sensitivity on `GPIO8/GPIO9` during reset:
- `GPIO9` is a strapping pin and also connected to IMU `H_MISO`.
- `GPIO8` is a strapping pin and also connected to IMU `H_SCK`.
- If either line is in a bad state at reset sample time, download mode entry can fail or be inconsistent.

Additional design behavior that can increase variability:
- `RST1` controls LDO `EN` (power-cycles full 3V3 domain), instead of directly resetting MCU `EN`.
- This means MCU and IMU ramp together on reset, increasing chance of transient strap interactions.

## Why This Can Look Worse Than It Is
- Flash entry can fail while runtime hardware is still mostly correct.
- A board can be hard to program but still run normally once a valid image is in flash.
- Rhythmic buzzer/LED can be caused by repeated reboot/boot-state cycling.

## Immediate Bring-Up Procedure (Current Hardware)
1. Connect USB and confirm enumeration (`/dev/cu.usbmodem*` appears).
2. Force download straps during reset:
   - Hold `GPIO9` low.
   - Ensure `GPIO8` is high.
   - Toggle reset/power (for this rev, reset behavior is tied to regulator enable path).
3. Keep `GPIO9` low briefly through reset edge, then attempt flashing.
4. If flash succeeds once, power-cycle and test normal boot repeatedly without forcing straps.
5. If normal boot is stable, proceed with firmware functional tests.

## Known Good/Expected USB Identity
Seeing Espressif `USB JTAG/serial debug unit` on macOS is expected for ESP32-C3 native USB in this state and is useful for Web Serial/Web flasher flow.

## Firmware/Flasher Actions Planned
- Keep `DIY` flow as default and unchanged.
- Add explicit `Custom PCB` option in web flasher UI.
- Publish manifests/artifacts for both:
  - `azimuth_main_diy`
  - `azimuth_main_pcb`
- Add recovery instructions specific to custom PCB:
  - `GPIO9 low` + reset
  - keep `GPIO8` high

## V0.2 Design Improvements (No Jumper Bring-Up Goal)
- Add dedicated BOOT control for `GPIO9` (button or test pad).
- Add dedicated MCU reset button on `EN` (separate from full-rail power-cycle behavior).
- Add deterministic strap biasing so peripherals cannot dominate `GPIO8/GPIO9` at reset.
- Add stronger IMU CS default inactive behavior during reset window.
- Consider delayed IMU enable/reset so MCU strap sampling completes before IMU drives SPI-related nets.
- Optional: add auto-program/reset circuitry for one-click flashing workflow.

## Acceptance Criteria for V0.1 Prototype Success
- Board reliably enters download mode with forced strap method.
- Firmware flashes successfully.
- Board boots into expected setup AP flow after flash.
- Basic runtime behavior is stable across multiple reboots.

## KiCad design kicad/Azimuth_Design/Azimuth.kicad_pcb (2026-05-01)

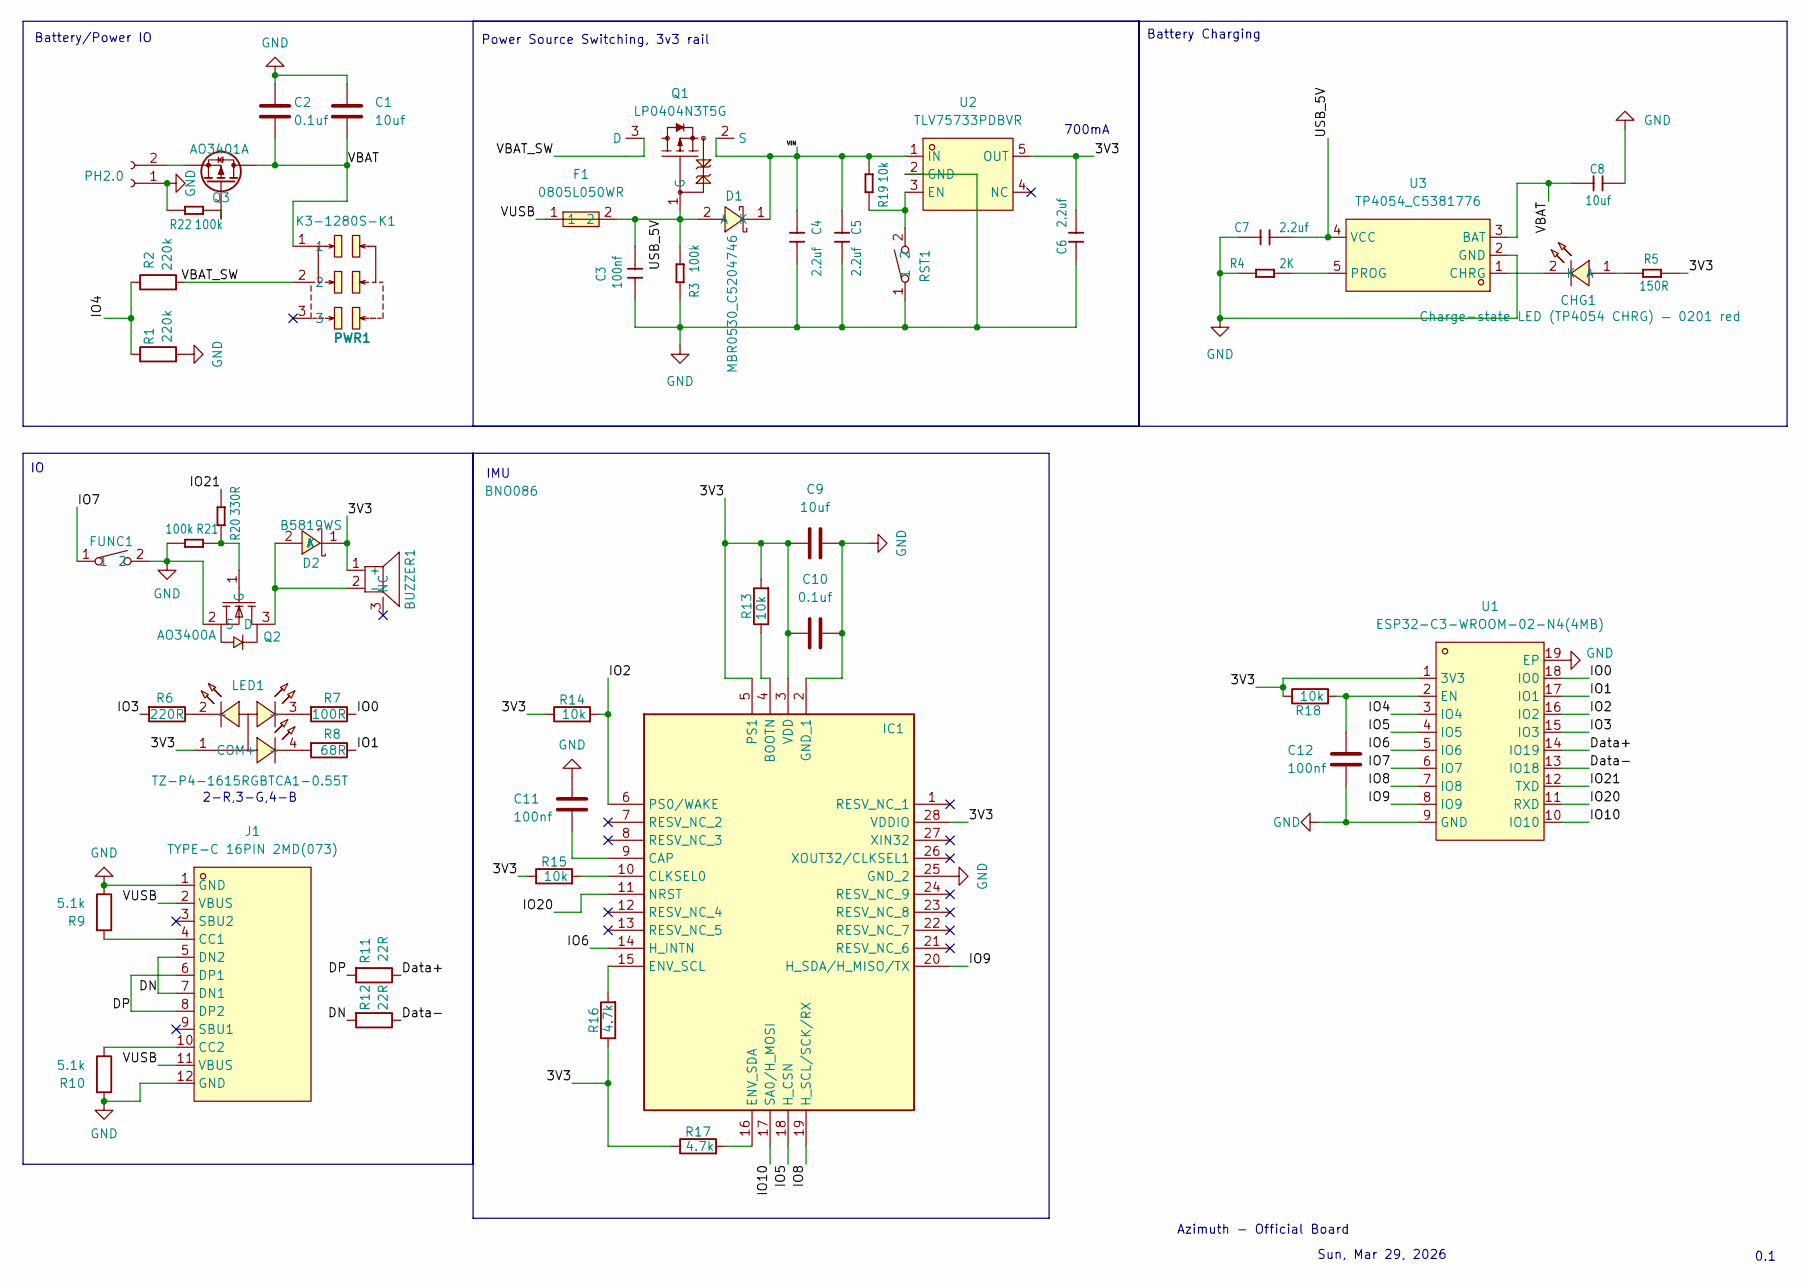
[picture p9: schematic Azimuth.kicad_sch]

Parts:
BUZZER1: MLT-5020; BUZ-SMD_L5.0-W5.5-P4.60; Manufacturer_Part_Number MLT-5020; LCSC Part C94598
C1, C8, C9: 10uf; C_0402_1005Metric; Manufacturer_Part_Number CL05A106MP5NUNC; LCSC Part C315248
C2, C10: 0.1uf; C_0402_1005Metric; Manufacturer_Part_Number CC0402KRX7R7BB104; LCSC Part C60474
C3, C11, C12: 100nf; C_0201_0603Metric; Manufacturer_Part_Number GRM033R61A104KE15D; LCSC Part C76934
C4, C5, C6, C7: 2.2uf; C_0201_0603Metric; Manufacturer_Part_Number GRM033R61A225KE47D; LCSC Part C335106
CHG1: XL-0201SURC; LED-SMD_L0.65-W0.35-P0.41_XL-0201SURC; Manufacturer_Part_Number XL-0201SURC; LCSC Part C3646923
D1: MBR0530_C5204746; SOD-123_L2.7-W1.6-LS3.7-RD-1; Manufacturer_Part_Number MBR0530; LCSC Part C5204746
D2: B5819WS; SOD-323_L1.8-W1.3-LS2.5-RD; Manufacturer_Part_Number B5819WS; LCSC Part C64886
F1: 0805L050WR; R0805; Manufacturer_Part_Number 0805L050WR; LCSC Part C207022
FUNC1: HX 3X4X2-2P-1.6N TACTILE SWITCH; KEY-SMD_L4.0-W3.0-LS4.9-1; Manufacturer_Part_Number HX 3x4x2-2P-1.6N TACTILE SWITCH; LCSC Part C49234124
IC1: BNO086; LGA-28_5.2x3.8mm_P0.5mm; Manufacturer_Part_Number BNO086; Mouser Part Number 526-BNO086
J1: TYPE-C 16PIN 2MD(073); USB-C-SMD_TYPE-C-6PIN-2MD-073; LCSC Part C2765186
LED1: TZ-P4-1615RGBTCA1-0.55T; LED-SMD_4P-L1.6-W1.5-BR_TZ-P4-1615; LCSC Part C779813
PH2.0: S2B-PH-SM4-TB(LF)(SN); JST_PH_S2B-PH-SM4-TB_1x02-1MP_P2.00mm_Horizontal; Manufacturer_Part_Number S2B-PH-SM4-TB(LF)(SN); LCSC Part C295747
PWR1: K3-1280S-K1; SW-SMD_K3-1280S-K1; Manufacturer_Part_Number K3-1280S-K1; LCSC Part C128953
Q1: LP0404N3T5G; SOT-883-3_L1.0-W0.6-BR; Manufacturer_Part_Number LP0404N3T5G; LCSC Part C172433
Q2: AO3400A; SOT-23-3_L2.9-W1.3-P1.90-LS2.4-BR; Manufacturer_Part_Number AO3400A; LCSC Part C20917
Q3: AO3401A; SOT-23-3_L2.9-W1.3-P1.90-LS2.4-BR; LCSC Part C347476
R1, R2: 220k; R_0402_1005Metric; Manufacturer_Part_Number 0402WGF2203TCE; LCSC Part C25767
R3, R21, R22: 100k; R_0201_0603Metric; Manufacturer_Part_Number RC0201FR-07100KL; LCSC Part C106224
R4: 2K; R_0201_0603Metric; Manufacturer_Part_Number RC0201FR-072KL; LCSC Part C327392
R5: 150R; R_0201_0603Metric; Manufacturer_Part_Number RC0201FR-07150RL; LCSC Part C295773
R6: 220R; R_0201_0603Metric; Manufacturer_Part_Number GR0201F220RTAG00; LCSC Part C49654383
R7: 100R; R_0201_0603Metric; Manufacturer_Part_Number RC0201FR-07100RL; LCSC Part C77623
R8: 68R; R_0201_0603Metric; Manufacturer_Part_Number GR0201J68RTAG00; LCSC Part C49655823
R9, R10: 5.1k; R_0201_0603Metric; Manufacturer_Part_Number RC0201FR-075K1L; LCSC Part C274341
R11, R12: 22R; R_0201_0603Metric; Manufacturer_Part_Number RC0201FR-0722RL; LCSC Part C155743
R13, R14, R15, R18, R19: 10k; R_0201_0603Metric; Manufacturer_Part_Number RC0201FR-0710KL; LCSC Part C106225
R16, R17: 4.7k; R_0201_0603Metric; Manufacturer_Part_Number RC0201FR-074K7L; LCSC Part C138135
R20: 330R; R_0201_0603Metric; Manufacturer_Part_Number RC0201FR-07330RL; LCSC Part C274872
RST1: HX 3X4X2-2P-1.6N TACTILE SWITCH; KEY-SMD_L4.0-W3.0-LS4.9-1; Manufacturer_Part_Number HX 3x4x2-2P-1.6N TACTILE SWITCH; LCSC Part C49234124
U1: ESP32-C3-WROOM-02-N4(4MB); BULETM-SMD_ESPRESSIF_ESP32-C3-WROOM-02-N4-4MB; LCSC Part C2934560
U2: TLV75733PDBVR; SOT-23-5_L2.9-W1.6-P0.95-LS2.8-BL; Manufacturer_Part_Number TLV75733PDBVR; LCSC Part C485517
U3: TP4054_C5381776; SOT-23-5_L2.9-W1.6-P0.95-LS2.8-BR; LCSC Part C5381776

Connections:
/3V3: BUZZER1.1 (+), C6.2, C9.2, C10.2, D2.1 (K), IC1.3 (VDD), IC1.5 (PS1), IC1.28 (VDDIO), LED1.1 (COM+), R5.1, R13.2, R14.1, R15.1, R16.1, R17.1, R18.1, U1.1 (3V3), U2.5 (OUT)
/DN: J1.5 (DN2), J1.7 (DN1), R12.2
/DP: J1.6 (DP1), J1.8 (DP2), R11.2
/Data+: R11.1, U1.14 (IO19)
/Data-: R12.1, U1.13 (IO18)
/IO0: R7.1, U1.18 (IO0)
/IO1: R8.1, U1.17 (IO1)
/IO2: IC1.6 (PS0/WAKE), R14.2, U1.16 (IO2)
/IO3: R6.2, U1.15 (IO3)
/IO4: R1.1, R2.1, U1.3 (IO4)
/IO5: IC1.18 (H_CSN), U1.4 (IO5)
/IO6: IC1.14 (H_INTN), U1.5 (IO6)
/IO7: FUNC1.1, U1.6 (IO7)
/IO8: IC1.19 (H_SCL/SCK/RX), U1.7 (IO8)
/IO9: IC1.20 (H_SDA/H_MISO/TX), U1.8 (IO9)
/IO10: IC1.17 (SA0/H_MOSI), U1.10 (IO10)
/IO20: IC1.11 (NRST), U1.11 (RXD)
/IO21: R20.2, U1.12 (TXD)
/USB_5V: C3.2, C7.2, D1.2 (A), F1.2, Q1.1 (G), R3.2, U3.4 (VCC)
/VBAT: C1.2, C2.1, C8.1, PWR1.1, Q3.3 (D), U3.3 (BAT)
/VBAT_SW: PWR1.2, Q1.3 (D), R2.2
/VIN: C4.1, C5.1, D1.1 (K), Q1.2 (S), R19.2, U2.1 (IN)
/VUSB: F1.1, J1.2 (VBUS), J1.11 (VBUS)
GND: C1.1, C2.2, C3.1, C4.2, C5.2, C6.1, C7.1, C8.2, C9.1, C10.1, C11.1, C12.1, FUNC1.2, IC1.2 (GND_1), IC1.25 (GND_2), J1.1 (GND), J1.12 (GND), PH2.0.1, Q2.2 (S), R1.2, R3.1, R4.2, R9.1, R10.2, R21.2, R22.1, RST1.1, U1.9 (GND), U1.19 (EP), U2.2 (GND), U3.2 (GND)
unnamed: BUZZER1.2 (-), D2.2 (A), Q2.3 (D)
unnamed: CHG1.1 (A), R5.2
unnamed: CHG1.2 (K), U3.1 (CHRG)
unnamed: IC1.4 (BOOTN), R13.1
unnamed: C11.2, IC1.9 (CAP)
unnamed: IC1.10 (CLKSEL0), R15.2
unnamed: IC1.15 (ENV_SCL), R16.2
unnamed: IC1.16 (ENV_SDA), R17.2
unnamed: J1.4 (CC1), R9.2
unnamed: J1.10 (CC2), R10.1
unnamed: LED1.2 (-), R6.1
unnamed: LED1.3 (-), R7.2
unnamed: LED1.4 (-), R8.2
unnamed: PH2.0.2, Q3.2 (S)
unnamed: Q2.1 (G), R20.1, R21.1
unnamed: Q3.1 (G), R22.2
unnamed: C12.2, R18.2, U1.2 (EN)
unnamed: R19.1, RST1.2, U2.3 (EN)
unnamed: R4.1, U3.5 (PROG)

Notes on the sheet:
Sun, Mar 29, 2026
0.1
Azimuth - Official Board
IMU
Battery/Power IO
Battery Charging
700mA
Power Source Switching, 3v3 rail
2-R,3-G,4-B

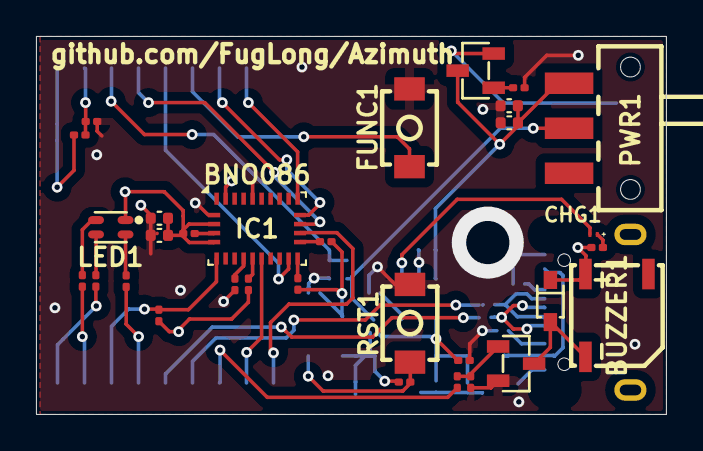
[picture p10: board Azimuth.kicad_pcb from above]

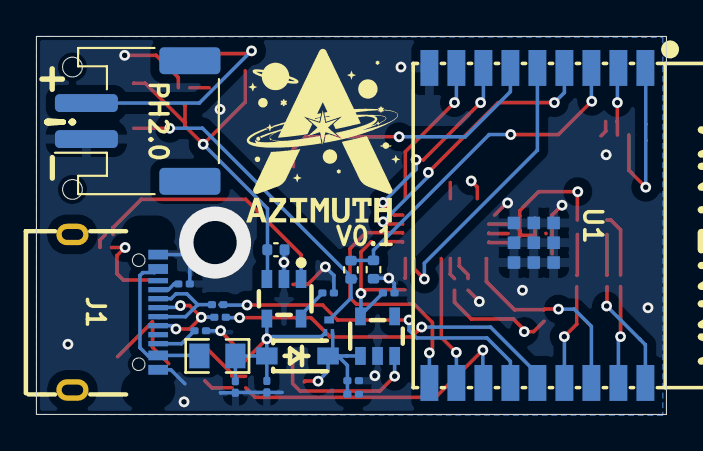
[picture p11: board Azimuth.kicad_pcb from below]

Board: 4 copper layers, 35.0 x 21.0 mm, 52 parts (21 on the bottom side), 43 nets.

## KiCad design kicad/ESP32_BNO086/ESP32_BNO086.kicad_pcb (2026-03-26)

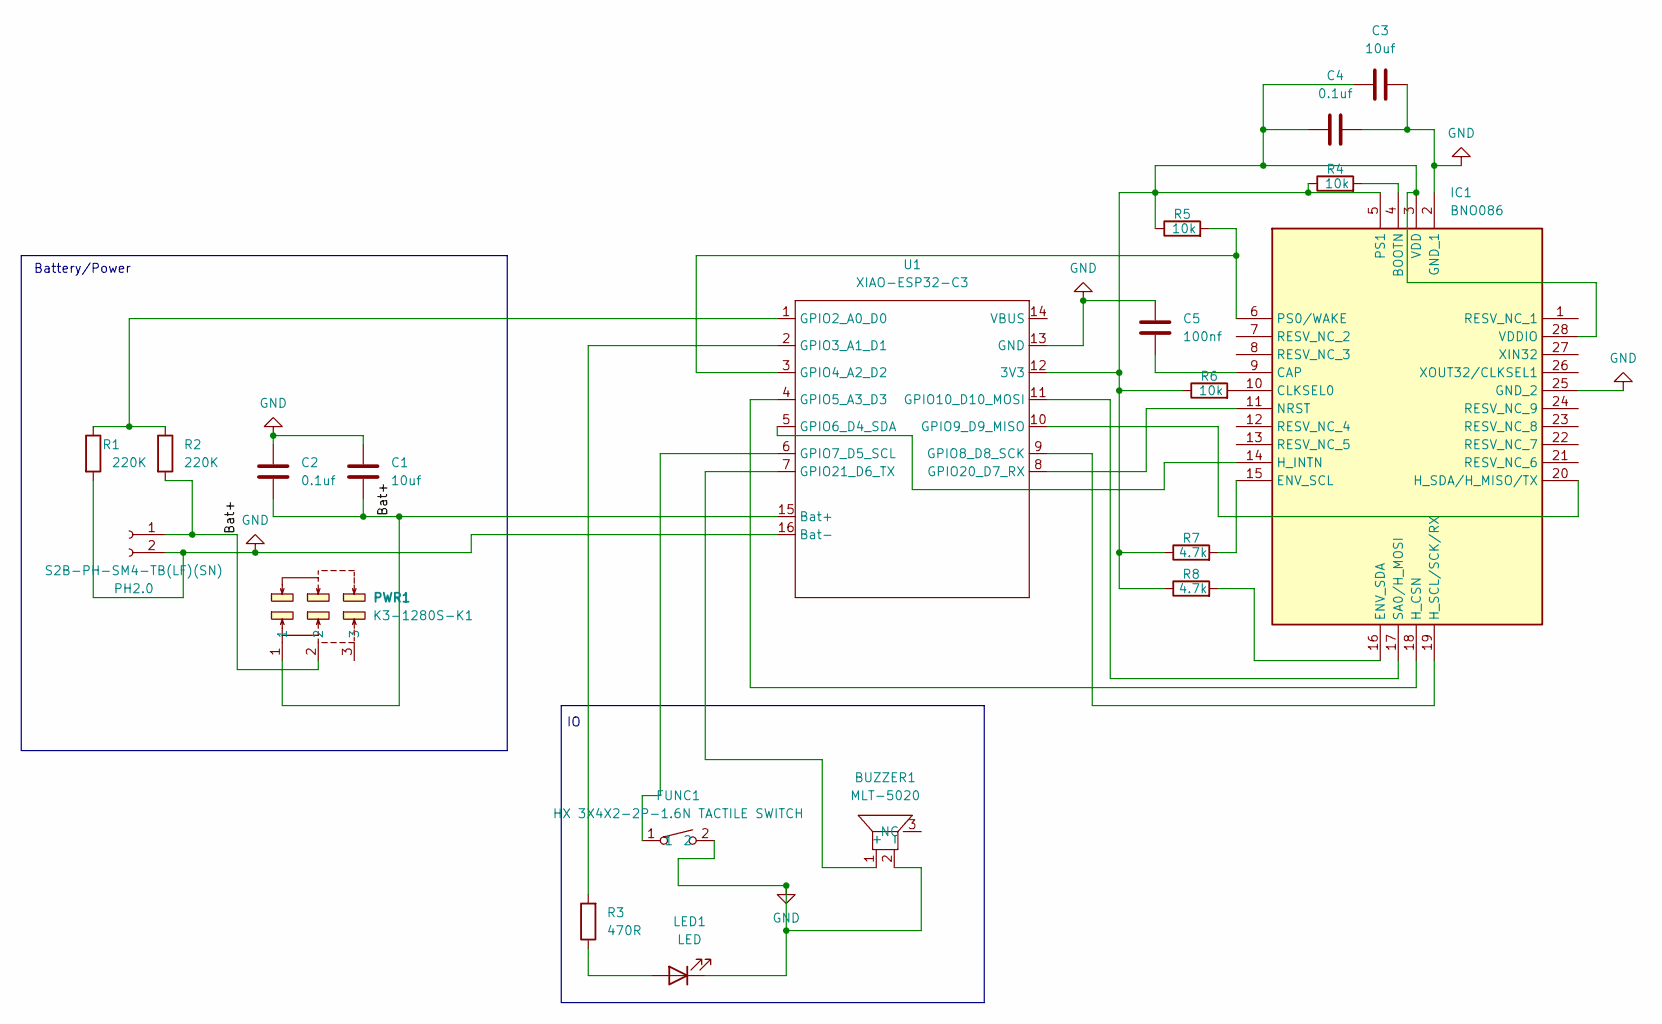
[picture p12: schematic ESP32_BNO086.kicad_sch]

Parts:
BUZZER1: MLT-5020; BUZ-SMD_L5.0-W5.5-P4.60; Manufacturer_Part_Number MLT-5020; LCSC Part C94598
C1, C3: 10uf; C_0603_1608Metric; Manufacturer_Part_Number CL10A106KP8NNNC; LCSC Part C19702
C2, C4: 0.1uf; C_0603_1608Metric; Manufacturer_Part_Number CC0603KRX7R9BB104; LCSC Part C14663
C5: 100nf; C_0402_1005Metric; Manufacturer_Part_Number GRM155R71H104KE14D; LCSC Part C77020
FUNC1: HX 3X4X2-2P-1.6N TACTILE SWITCH; KEY-SMD_L4.0-W3.0-LS4.9-1; Manufacturer_Part_Number HX 3x4x2-2P-1.6N TACTILE SWITCH; LCSC Part C49234124
IC1: BNO086; LGA-28_5.2x3.8mm_P0.5mm; Manufacturer_Part_Number BNO086; Mouser Part Number 526-BNO086
LED1: LED; LED_0402_1005Metric; Manufacturer_Part_Number YLED0402R; LCSC Part C21260817
PH2.0: S2B-PH-SM4-TB(LF)(SN); JST_PH_S2B-PH-SM4-TB_1x02-1MP_P2.00mm_Horizontal; Manufacturer_Part_Number S2B-PH-SM4-TB(LF)(SN); LCSC Part C295747
PWR1: K3-1280S-K1; SW-SMD_K3-1280S-K1; Manufacturer_Part_Number K3-1280S-K1; LCSC Part C128953
R1, R2: 220K; R_0603_1608Metric; Manufacturer_Part_Number FRC0603F2203TS; LCSC Part C2907013
R3: 470R; R_0402_1005Metric; Manufacturer_Part_Number RC0402FR-07470RL; LCSC Part C114877
R4, R5, R6: 10k; R_0402_1005Metric; Manufacturer_Part_Number RC0402FR-0710KL; LCSC Part C60490
R7, R8: 4.7k; R_0402_1005Metric; Manufacturer_Part_Number RC0402FR-074K7L; LCSC Part C105871
U1: XIAO-ESP32-C3; XIAO-ESP32-C3-DIP-SMD; Manufacturer_Part_Number 113991054; Mouser Part Number 713-113991054

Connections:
GND: BUZZER1.2 (-), C1.1, C2.2, C3.1, C4.1, C5.1, FUNC1.2, IC1.2 (GND_1), IC1.25 (GND_2), LED1.1 (K), PH2.0.2, R1.2, U1.13 (GND), U1.16 (Bat-)
unnamed: BUZZER1.1 (+), U1.7 (GPIO21_D6_TX)
unnamed: IC1.4 (BOOTN), R4.2
unnamed: C5.2, IC1.9 (CAP)
unnamed: IC1.10 (CLKSEL0), R6.2
unnamed: IC1.15 (ENV_SCL), R7.2
unnamed: IC1.16 (ENV_SDA), R8.2
unnamed: IC1.18 (H_CSN), U1.4 (GPIO5_A3_D3)
unnamed: IC1.14 (H_INTN), U1.5 (GPIO6_D4_SDA)
unnamed: IC1.19 (H_SCL/SCK/RX), U1.9 (GPIO8_D8_SCK)
unnamed: IC1.20 (H_SDA/H_MISO/TX), U1.10 (GPIO9_D9_MISO)
unnamed: IC1.11 (NRST), U1.8 (GPIO20_D7_RX)
unnamed: IC1.6 (PS0/WAKE), R5.2, U1.3 (GPIO4_A2_D2)
unnamed: C3.2, C4.2, IC1.3 (VDD), IC1.5 (PS1), IC1.28 (VDDIO), R4.1, R5.1, R6.1, R7.1, R8.1, U1.12 (3V3)
unnamed: IC1.17 (SA0/H_MOSI), U1.11 (GPIO10_D10_MOSI)
unnamed: LED1.2 (A), R3.1
unnamed: R1.1, R2.1, U1.1 (GPIO2_A0_D0)
unnamed: R3.2, U1.2 (GPIO3_A1_D1)
unnamed: FUNC1.1, U1.6 (GPIO7_D5_SCL)

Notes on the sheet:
Battery/Power

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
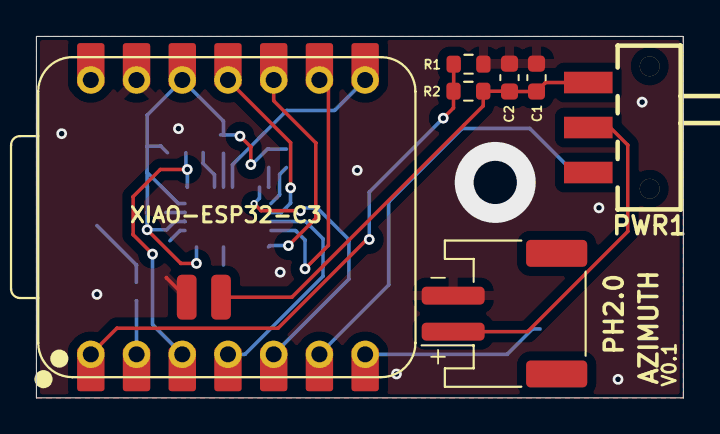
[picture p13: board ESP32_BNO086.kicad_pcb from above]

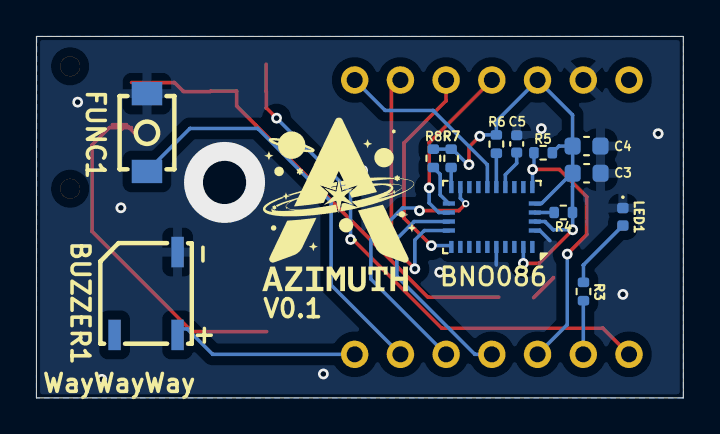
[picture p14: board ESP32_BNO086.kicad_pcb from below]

Board: 2 copper layers, 35.9 x 20.1 mm, 20 parts (13 on the bottom side), 21 nets.

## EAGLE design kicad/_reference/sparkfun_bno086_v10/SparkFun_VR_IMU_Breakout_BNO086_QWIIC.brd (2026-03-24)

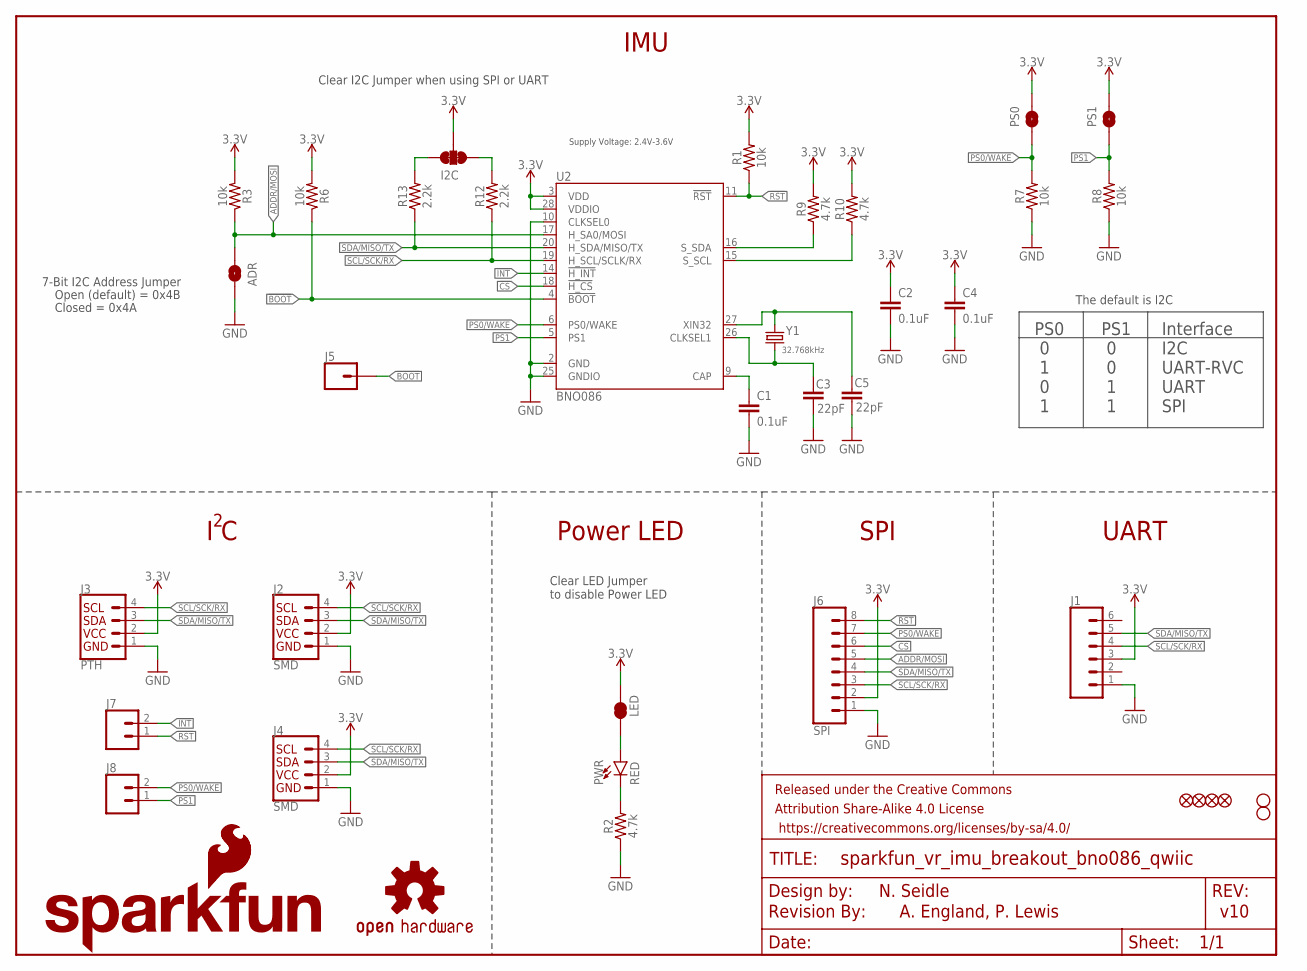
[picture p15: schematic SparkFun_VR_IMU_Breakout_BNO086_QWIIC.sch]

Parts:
ADR: JUMPER-SMT_2_NO_SILK; SMT-JUMPER_2_NO_SILK
C1, C2, C4: 0.1uF; 0603
C3, C5: 22pF; 0603
FRAME1: FRAME-LETTER; CREATIVE_COMMONS
I2C: JUMPER-SMT_3_2-NC_TRACE_SILK; SMT-JUMPER_3_2-NC_TRACE_SILK
J1: CONN_06NO_SILK_FEMALE_PTH; 1X06_NO_SILK
J2, J4: SMD; JST04_1MM_RA
J3: PTH; 1X04_NO_SILK
J5: CONN_01PTH_NO_SILK_YES_STOP; 1X01_NO_SILK
J6: SPI; 1X08_NO_SILK
J7, J8: CONN_021X02_NO_SILK; 1X02_NO_SILK
JP1, JP2, JP5, JP6: FIDUCIALUFIDUCIAL; FIDUCIAL-MICRO
JP3, JP4: STAND-OFF
LED: JUMPER-SMT_2_NC_TRACE_SILK; SMT-JUMPER_2_NC_TRACE_SILK
LOGO1: OSHW-LOGOMINI; OSHW-LOGO-MINI
LOGO2: REVISION
LOGO4: SFE_LOGO_FLAME.2_INCH; SFE_LOGO_FLAME_.2
LOGO5: SFE_LOGO_NAME_FLAME.1_INCH; SFE_LOGO_NAME_FLAME_.1
PS0, PS1: JUMPER-SMT_2_NO_SILK; SMT-JUMPER_2_NO_SILK
PWR: RED; LED-0603
R1, R3, R6, R7, R8: 10k; 0603
R2, R9, R10: 4.7k; 0603
R12, R13: 2.2k; 0603
U2: BNO086; LGA-28
Y1: 32.768kHz; CRYSTAL-SMD-3.2X1.5MM

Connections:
3.3V: C2.1, C4.1, I2C.2, J1.3, J2.2, J3.2, J4.2, J6.2, LED.1, PS0.1, PS1.1, R1.2, R3.2, R6.2, R9.2, R10.2, U2.3 (VDD), U2.28 (VDDIO)
!BOOT: J5.1, R6.1, U2.4 (!BOOT)
!CS: J6.6, U2.18 (!H_CS)
!INT: J7.2, U2.14 (!H_INT)
!RST: J6.8, J7.1, R1.1, U2.11 (!RST)
ADDR/MOSI: ADR.2, J6.5, R3.1, U2.17 (H_SA0/MOSI)
CAP: C1.1, U2.9 (CAP)
GND: ADR.1, C1.2, C2.2, C3.2, C4.2, C5.2, J1.1, J2.1, J3.1, J4.1, J6.1, R2.1, R7.1, R8.1, U2.2 (GND), U2.10 (CLKSEL0), U2.25 (GNDIO)
unnamed: C5.1, U2.27 (XIN32), Y1.P$2 (2)
unnamed: C3.1, U2.26 (CLKSEL1), Y1.P$1 (1)
unnamed: PWR.C, R2.2
unnamed: LED.2, PWR.A
PS0/WAKE: J6.7, J8.2, PS0.2, R7.2, U2.6 (PS0/WAKE)
PS1: J8.1, PS1.2, R8.2, U2.5 (PS1)
SCL/SCK/RX: J1.4, J2.4, J3.4, J4.4, J6.3, R12.1, U2.19 (H_SCL/SCLK/RX)
SCL_PU: I2C.1, R12.2
SDA/MISO/TX: J1.5, J2.3, J3.3, J4.3, J6.4, R13.1, U2.20 (H_SDA/MISO/TX)
SDA_PU: I2C.3, R13.2
S_SCL: R10.1, U2.15 (S_SCL)
S_SDA: R9.1, U2.16 (S_SDA)

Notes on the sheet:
N. Seidle
v10
7-Bit I2C Address Jumper
Closed = 0x4A
Open (default) = 0x4B
PS0 0 1 0 1
PS1 0 0 1 1
Interface I2C UART-RVC UART SPI
The default is I2C
Clear I2C Jumper when using SPI or UART
I C
UART
SPI
A. England, P. Lewis
Supply Voltage: 2.4V-3.6V
IMU
Clear LED Jumper to disable Power LED
Power LED

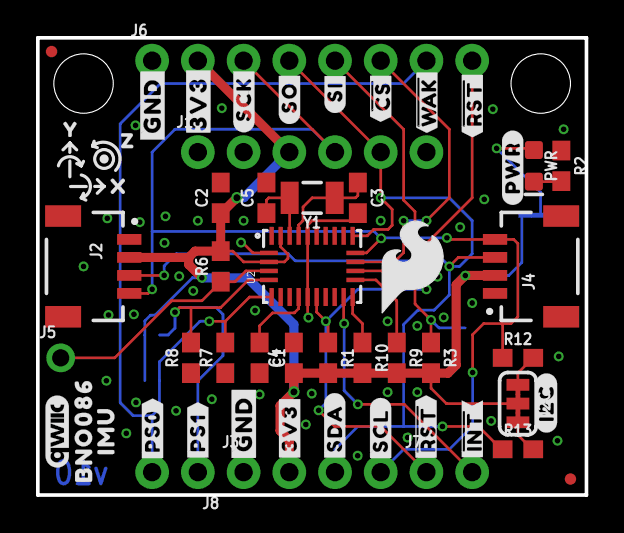
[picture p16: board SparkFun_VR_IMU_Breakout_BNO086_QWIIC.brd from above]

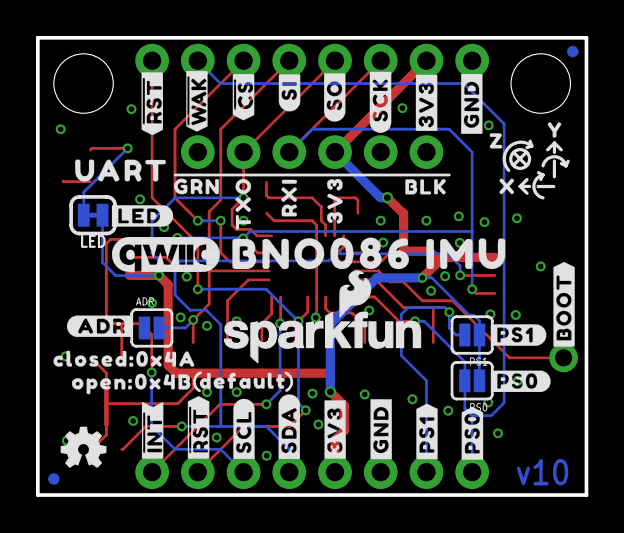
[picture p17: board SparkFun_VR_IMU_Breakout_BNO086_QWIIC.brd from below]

Board: 2 copper layers, 30.5 x 25.4 mm, 102 parts (43 on the bottom side), 20 nets.

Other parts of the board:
U$1: #I2C#874
U$2: BLK889
U$3, U$25: X878
U$4: ##INT##6
U$5: ##RST##5
U$6, U$10: Y879
U$7, U$15: Z880
U$8: #SCL#4
U$9, U$16: #GND#2
U$11: #SCK#882
U$12: #SO#867
U$13: #SI#868
U$14: #SDA#3
U$17: ##CS##870
U$18: ##CS##885
U$19: ##RST##872
U$20: ##RST##887
U$21: RXI891
U$22: TXO892
U$23: #PS0#874
U$24: BNO0861
U$26: #LED#0
U$27, U$46: #3V3#874
U$28: OPEN#0X4B0
U$29: QWIIC_4MM
U$30: #ADR#894
U$31: IMU862
U$32, U$45: #GND#864
U$33: #PS1#1
U$34: #PS0#2
U$35: #PS1#895
U$36: #3V3#865
U$37: #SCK#866
U$38: ##WAK##871
U$39: #3V3#882
U$40: 3V3891
U$41: GRN890
U$42: #PWR#873
U$43: #PS1#874
U$44: UART881
U$47: #SDA#874
U$48: #SCL#875
U$49: #BOOT#888
U$50: ##RST##876
U$51: ##INT##877
U$52: QWIIC_6MM
U$53: ##WAK##886
U$54: BNO086_IMU881
U$55: #SO#883
U$56: #SI#884
U$57: #PS0#895
U$58: CLOSED#0X4A0
U$59: ORDERING_INSTRUCTIONS
U$61: DEFAULT0

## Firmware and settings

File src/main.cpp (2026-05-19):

/**
 * Seeed XIAO ESP32-C3 + BNO08x (SPI) fused orientation.
 *
 * DIY: XIAO + BNO08x breakout (see docs/wiring.md)
 *   FSPI: SCK D8 (GPIO8), MISO D9 (GPIO9), MOSI D10 (GPIO10)
 *   CS D3 (GPIO5), INT D4 (GPIO6), NRST D7 (GPIO20)
 *   PS0 or WAKE D0 (GPIO2) + 10k to 3V3; battery sense D2 (GPIO4) if used; PS1 VDD VDDIO to 3V3
 *
 * Azimuth_Design PCB: same GPIO map as azimuth_hw.h (R14 on PS0 and IO2, divider on IO4, RGB buzzer FUNC).
 *
 * PlatformIO: azimuth_*_diy (XIAO) vs azimuth_*_pcb (custom PCB). Pins: include/azimuth_hw.h
 *   IMU_DEBUG_MODE 1 = USB serial angles only; 0 = Hatire + WiFi or portal + OpenTrack UDP.
 */

#include <Arduino.h>
#include <SPI.h>
#include <cstring>

#include "azimuth_hw.h"
#include "battery_monitor.h"
#include "io_button.h"
#include "io_buzzer.h"
#include "io_led.h"
#include "io_led_policy.h"
#include "thermal_monitor.h"
#include "SparkFun_BNO08x_Arduino_Library.h"

#ifndef IMU_DEBUG_MODE
#define IMU_DEBUG_MODE 1
#endif

#if !IMU_DEBUG_MODE
#include <string.h>
#include "imu_dynamic.h"
#include "opentrack_pose.h"
#include "track_network.h"
#endif

namespace {

/** Chip select — any free GPIO; SparkFun lib drives CS in software. */
constexpr uint8_t kPinCs = azimuth_hw::kPinImuCs;
constexpr uint8_t kPinInt = azimuth_hw::kPinImuInt;
constexpr uint8_t kPinRst = azimuth_hw::kPinImuRst;

#if IMU_DEBUG_MODE
/** Rotation vector report period passed to enableRotationVector() — milliseconds (100 Hz). */
constexpr uint16_t kRotationVectorPeriodMs = 10;
#endif

#if IMU_DEBUG_MODE
/** Limit how often we print in debug mode (sensor still runs at full rate). */
constexpr uint32_t kPrintIntervalMs = 100;
#endif

/** SPI clock (Hz). BNO08x SPI is limited to 3 MHz; library clamps if higher. */
constexpr uint32_t kSpiHz = 3000000;

constexpr float kRadToDeg = 180.0f / 3.14159265f;

BNO08x imu;

#if IMU_DEBUG_MODE
uint32_t gLastPrintMs = 0;
#endif

int32_t gPrevBatteryPercent = -1;
bool gBatteryWarn25Latched = false;
bool gBatteryWarn15Latched = false;
bool gBatteryWarn10Latched = false;
bool gBatteryWarn5Latched = false;
bool gBatteryWarn4Latched = false;
bool gBatteryWarn3Latched = false;
bool gBatteryWarn2Latched = false;
bool gBatteryWarn1Latched = false;
bool gBatteryEmergencyWifiCut = false;
uint32_t gBatteryEmergencyLastPulseMs = 0;

void onFuncButtonSingleTap() {
#if !IMU_DEBUG_MODE
  if (trackNetworkThermalHoldActive()) {
    return;
  }
  const auto batt = azimuth_battery::readStatus();
  if (batt.supported && !batt.stub && batt.percent >= 0 && batt.percent <= 1 &&
      strcmp(batt.chargeState, "absent") != 0) {
    return;
  }
  const bool next = !trackNetworkStasisActive();
  trackNetworkSetStasis(next);
  if (next) {
    azimuth_io_buzzer::playStasisEnterTune();
  } else {
    azimuth_io_buzzer::playStasisExitTune();
  }
#endif
}

void onFuncButtonDoubleTap() {}

void onFuncButtonLongPress() {
#if !IMU_DEBUG_MODE
  if (trackNetworkThermalHoldActive()) {
    return;
  }
  // Result string is logged by the portal too via /api/update_status; we don't
  // want to chatter on USB serial here.
  (void)trackNetworkBeginFirmwareUpdate();
#endif
}

#if !IMU_DEBUG_MODE
/**
 * Hatire / OpenTrack USB packet (same layout as Nano33_PC_Head_Tracker IO.h).
 * The float fields are Euler angles in degrees; acc[] was unused there (zeros).
 */
struct Hat {
  int16_t Begin;
  uint16_t Cpt;
  float gyro[3];
  float acc[3];
  int16_t End;
} __attribute__((packed));

static_assert(sizeof(Hat) == 30, "Hatire struct must be 30 bytes for OpenTrack compatibility");

Hat gHat;

/** Tracks USB host presence so we can re-sync Hatire after OpenTrack disconnect/reconnect. */
bool gHatireUsbWasConnected = false;

void hatireInitPacket() {
  gHat.Begin = static_cast<int16_t>(0xAAAA);
  gHat.Cpt = 0;
  memset(gHat.gyro, 0, sizeof(gHat.gyro));
  memset(gHat.acc, 0, sizeof(gHat.acc));
  gHat.End = static_cast<int16_t>(0x5555);
}

bool hatireUsbHostActive() {
  if (!Serial) {
    return false;
  }
  // Keep this portable across HWCDC variants (not all expose DTR state).
  if (Serial.availableForWrite() < static_cast<int>(sizeof(gHat))) {
    return false;
  }
  return true;
}

bool sendHatirePacket(float yawDeg, float pitchDeg, float rollDeg) {
  // ESP32 USB CDC: writing with no host (or full TX) can block forever — skip/drop instead.
  if (!hatireUsbHostActive()) {
    return false;
  }

  opentrackMapEulerToRot(yawDeg, pitchDeg, rollDeg, trackNetworkOtAxisMap(), gHat.gyro);

  Serial.write(reinterpret_cast<const uint8_t*>(&gHat), sizeof(gHat));

  gHat.Cpt++;
  if (gHat.Cpt > 999) {
    gHat.Cpt = 0;
  }
  return true;
}

uint16_t gAppliedRvPeriodMs = 0;

static uint16_t gRvSlowHoldWant = 0;
static uint8_t gRvSlowHoldCount = 0;

void applyRotationVectorPeriodMs(uint16_t periodMs) {
  if (periodMs == gAppliedRvPeriodMs) {
    return;
  }
  if (imu.enableRotationVector(periodMs)) {
    gAppliedRvPeriodMs = periodMs;
  }
}

/** Slower reporting (larger `want` ms) is debounced — frequent `enableRotationVector` when easing down causes hitches. */
void applyRotationVectorPeriodDebounced(uint16_t want) {
  if (want < gAppliedRvPeriodMs) {
    gRvSlowHoldWant = 0;
    gRvSlowHoldCount = 0;
    applyRotationVectorPeriodMs(want);
    return;
  }
  if (want == gAppliedRvPeriodMs) {
    gRvSlowHoldWant = 0;
    gRvSlowHoldCount = 0;
    return;
  }
  if (want == gRvSlowHoldWant) {
    ++gRvSlowHoldCount;
  } else {
    gRvSlowHoldWant = want;
    gRvSlowHoldCount = 1;
  }
  if (gRvSlowHoldCount >= 3) {
    applyRotationVectorPeriodMs(want);
    gRvSlowHoldWant = 0;
    gRvSlowHoldCount = 0;
  }
}

#endif  // !IMU_DEBUG_MODE

void enableReports() {
#if IMU_DEBUG_MODE
  const uint16_t periodMs = kRotationVectorPeriodMs;
  if (!imu.enableRotationVector(periodMs)) {
    Serial.println(F("enableRotationVector failed"));
  }
#else
  if (trackNetworkImuDynamicEnabled()) {
    const uint16_t peak = trackNetworkImuRotationPeriodMs();
    const uint16_t p0 = azimuth_imu_dynamic::armDynamicForPeak(peak);
    applyRotationVectorPeriodMs(p0);
  } else {
    azimuth_imu_dynamic::resetState();
    applyRotationVectorPeriodMs(trackNetworkImuRotationPeriodMs());
  }
#endif
}

void maybePlayBatteryThresholdAlert(bool& latched, int32_t prevPct, int32_t nowPct,
                                    int32_t thresholdPct, bool severe) {
  if (!latched && prevPct > thresholdPct && nowPct <= thresholdPct) {
    if (severe) {
      azimuth_io_buzzer::playBatteryPanicPulse();
    } else {
      azimuth_io_buzzer::playBatteryLowTune();
    }
    latched = true;
    return;
  }
  // Rearm with slight hysteresis to prevent chatter.
  if (latched && nowPct > (thresholdPct + 1)) {
    latched = false;
  }
}

void tickBatteryAlerts(uint32_t nowMs) {
  const auto batt = azimuth_battery::readStatus();
  if (!batt.supported || batt.stub || batt.percent < 0 ||
      strcmp(batt.chargeState, "absent") == 0) {
    gPrevBatteryPercent = -1;
    gBatteryWarn25Latched = false;
    gBatteryWarn15Latched = false;
    gBatteryWarn10Latched = false;
    gBatteryWarn5Latched = false;
    gBatteryWarn4Latched = false;
    gBatteryWarn3Latched = false;
    gBatteryWarn2Latched = false;
    gBatteryWarn1Latched = false;
    gBatteryEmergencyWifiCut = false;
    gBatteryEmergencyLastPulseMs = 0;
    return;
  }

  const int32_t pct = batt.percent;
  int32_t prevPct = gPrevBatteryPercent;
  if (prevPct < 0) {
    prevPct = pct + 1;
  }

  maybePlayBatteryThresholdAlert(gBatteryWarn25Latched, prevPct, pct, 25, false);
  maybePlayBatteryThresholdAlert(gBatteryWarn15Latched, prevPct, pct, 15, false);
  if (!gBatteryWarn10Latched && prevPct > 10 && pct <= 10) {
    azimuth_io_buzzer::playBatteryCriticalTune();
    gBatteryWarn10Latched = true;
  } else if (gBatteryWarn10Latched && pct > 11) {
    gBatteryWarn10Latched = false;
  }
  maybePlayBatteryThresholdAlert(gBatteryWarn5Latched, prevPct, pct, 5, true);
  maybePlayBatteryThresholdAlert(gBatteryWarn4Latched, prevPct, pct, 4, true);
  maybePlayBatteryThresholdAlert(gBatteryWarn3Latched, prevPct, pct, 3, true);
  maybePlayBatteryThresholdAlert(gBatteryWarn2Latched, prevPct, pct, 2, true);
  maybePlayBatteryThresholdAlert(gBatteryWarn1Latched, prevPct, pct, 1, true);

  if (pct <= 1) {
    if (nowMs - gBatteryEmergencyLastPulseMs >= 550) {
      azimuth_io_buzzer::playBatteryPanicPulse();
      gBatteryEmergencyLastPulseMs = nowMs;
    }
#if !IMU_DEBUG_MODE
    if (!gBatteryEmergencyWifiCut) {
      trackNetworkApplyThermalEmergency();
      gBatteryEmergencyWifiCut = true;
    }
#endif
  } else {
    gBatteryEmergencyLastPulseMs = 0;
  }

  gPrevBatteryPercent = pct;
}

}  // namespace

void setup() {
  Serial.begin(115200);
  azimuth_io_led::init();
  azimuth_io_buzzer::init();
  azimuth_io_button::init();
  azimuth_io_button::setTapCallbacks(onFuncButtonSingleTap, onFuncButtonDoubleTap);
  azimuth_io_button::setLongPressCallback(onFuncButtonLongPress);
  azimuth_battery::init();
  azimuth_thermal::init();
  azimuth_io_led::setStatus(true);

#if IMU_DEBUG_MODE
  const uint32_t usbWaitMs = 4000;
  const uint32_t t0 = millis();
  while (!Serial && (millis() - t0 < usbWaitMs)) {
    delay(10);
  }

  Serial.println();
  Serial.println(F("BNO08x (SPI) — DEBUG: yaw / pitch / roll (deg)"));
  Serial.println(F("Init..."));
#else
  hatireInitPacket();
  trackNetworkLoadTrackingPrefs();
#endif

  // SparkFun BNO08x beginSPI() calls SPI.begin() with no pins — board defaults apply.
  // XIAO variant maps SPI to GPIO 8/9/10; esp32-c3-devkitc-02 uses variant esp32c3 (4/5/6).
  // Azimuth_Design wires FSPI to 8/9/10, so always bind the bus explicitly.
  SPI.begin(azimuth_hw::kPinSpiSck, azimuth_hw::kPinSpiMiso, azimuth_hw::kPinSpiMosi, -1);

  if (!imu.beginSPI(kPinCs, kPinInt, kPinRst, kSpiHz, SPI)) {
#if IMU_DEBUG_MODE
    Serial.println(F("ERROR: BNO08x not detected. Check SPI wiring, PS0/PS1=3V3, INT, RST."));
#endif
    while (true) {
      delay(500);
    }
  }

#if IMU_DEBUG_MODE
  Serial.println(F("BNO08x OK"));
#endif

  enableReports();
  delay(150);

#if !IMU_DEBUG_MODE
  trackNetworkInit();
#endif
  azimuth_io_buzzer::playFuncButtonTune();
}

void loop() {
  const uint32_t nowMs = millis();
  azimuth_battery::tick(nowMs);
  tickBatteryAlerts(nowMs);
  azimuth_thermal::tick(nowMs);
  azimuth_io_button::tick();
  azimuth_io_buzzer::tick();
#if !IMU_DEBUG_MODE
  const bool usbConnected = hatireUsbHostActive();
  if (usbConnected && !gHatireUsbWasConnected) {
    hatireInitPacket();
  }
  gHatireUsbWasConnected = usbConnected;
  if (trackNetworkTakeImuPrefsDirty()) {
    gAppliedRvPeriodMs = 0;
    gRvSlowHoldWant = 0;
    gRvSlowHoldCount = 0;
    if (trackNetworkImuDynamicEnabled()) {
      applyRotationVectorPeriodMs(
          azimuth_imu_dynamic::armDynamicForPeak(trackNetworkImuRotationPeriodMs()));
    } else {
      azimuth_imu_dynamic::resetState();
      applyRotationVectorPeriodMs(trackNetworkImuRotationPeriodMs());
    }
  }
#endif

  if (imu.wasReset()) {
#if IMU_DEBUG_MODE
    Serial.println(F("# sensor reset; re-enabling reports"));
#endif
    enableReports();
  }

  if (!imu.getSensorEvent()) {
    azimuth_io_led_policy::tick(nowMs, false);
#if !IMU_DEBUG_MODE
    trackNetworkLoop();
#endif
    yield();  // avoid 100% CPU busy-spin between IMU reports (major heat / power)
    return;
  }

  if (imu.getSensorEventID() != SENSOR_REPORTID_ROTATION_VECTOR) {
    azimuth_io_led_policy::tick(nowMs, false);
#if !IMU_DEBUG_MODE
    trackNetworkLoop();
#endif
    yield();
    return;
  }

  const float yawDeg = imu.getYaw() * kRadToDeg;
  const float pitchDeg = imu.getPitch() * kRadToDeg;
  const float rollDeg = imu.getRoll() * kRadToDeg;

#if IMU_DEBUG_MODE
  const uint32_t now = millis();
  azimuth_io_led_policy::tick(nowMs, true);
  if (now - gLastPrintMs < kPrintIntervalMs) {
    return;
  }
  gLastPrintMs = now;

  Serial.print(F("Yaw "));
  Serial.print(yawDeg, 1);
  Serial.print(F("°   Pitch "));
  Serial.print(pitchDeg, 1);
  Serial.print(F("°   Roll "));
  Serial.print(rollDeg, 1);
  Serial.println(F("°"));
#else
  if (trackNetworkImuDynamicEnabled()) {
    const uint16_t peak = trackNetworkImuRotationPeriodMs();
    const uint16_t want =
        azimuth_imu_dynamic::computeNextPeriodMs(yawDeg, pitchDeg, rollDeg, nowMs, peak);
    applyRotationVectorPeriodDebounced(want);
    float act = 0.0f;
    float rawOmega = 0.0f;
    float smoothMs = 0.0f;
    azimuth_imu_dynamic::readDynamicTelemetry(&act, &smoothMs, &rawOmega);
    trackNetworkPublishImuDynamicTelemetry(gAppliedRvPeriodMs, want, act, rawOmega, smoothMs);
  }
  // Pose path before `trackNetworkLoop()` so USB/UDP leave the device with minimal delay
  // after a rotation-vector report (network work is internally time-sliced).
  trackNetworkPublishPoseSample(yawDeg, pitchDeg, rollDeg);
  bool hatireSentThisFrame = false;
  if (trackNetworkHatireUsbEnabled() && !trackNetworkStasisActive()) {
    hatireSentThisFrame = sendHatirePacket(yawDeg, pitchDeg, rollDeg);
  }
  if (!hatireSentThisFrame) {
    trackNetworkSendOpentrackUdp(yawDeg, pitchDeg, rollDeg);
  }
  trackNetworkLoop();
  azimuth_io_led_policy::tick(nowMs, true);
#endif
}

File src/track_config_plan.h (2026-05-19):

#pragma once

#include <array>
#include <cstdint>
#include <string>

namespace azimuth_cfg {

template <typename T>
struct ConfigField {
  bool present = false;
  bool typeOk = true;
  T value{};
};

struct OtAxesEntry {
  int src = 0;
  bool inv = false;
};

enum class OtAxesIssue : uint8_t {
  kNone = 0,
  kNotArray,
  kWrongSize,
  kItemNotObject,
  kSrcType,
  kSrcRange,
  kInvType,
};

struct OtAxesField {
  bool present = false;
  OtAxesIssue issue = OtAxesIssue::kNone;
  std::array<OtAxesEntry, 3> axes{};
};

struct ConfigPlanInput {
  uint16_t prevImuPeriodMs = 10;
  bool prevImuDynamic = false;
  bool prevMdnsOn = true;
  std::string prevHostname;
  std::string prevSsid;

  ConfigField<std::string> ssid;
  ConfigField<std::string> password;
  ConfigField<std::string> otHost;
  ConfigField<int> otPort;
  ConfigField<bool> udpEnabled;
  ConfigField<bool> hatireUsb;
  ConfigField<bool> mdnsOn;
  ConfigField<int> imuPeriodMs;
  ConfigField<bool> imuDynamic;
  ConfigField<int> wifiTx;
  OtAxesField otAxes;
  ConfigField<int> rgbBrightness;
  ConfigField<int> ledMode;
  ConfigField<int> ledR;
  ConfigField<int> ledG;
  ConfigField<int> ledB;
  ConfigField<int> buzzerVolume;
  ConfigField<int> batteryCapacityMah;
  ConfigField<int> batteryCalOffsetMv;
  ConfigField<bool> batteryCalibrate4v2;
  ConfigField<std::string> hostname;
};

struct ConfigApplyPlan {
  bool ok = false;
  const char* errorCode = nullptr;
  const char* errorMessage = nullptr;

  bool writeSsid = false;
  std::string ssidValue;
  bool writePassword = false;
  std::string passwordValue;
  bool writeOtHost = false;
  std::string otHostValue;
  bool writeOtPort = false;
  uint16_t otPortValue = 0;
  bool writeUdpEnabled = false;
  bool udpEnabledValue = true;
  bool writeHatireUsb = false;
  bool hatireUsbValue = true;
  bool writeMdnsOn = false;
  bool mdnsOnValue = true;
  bool writeImuPeriodMs = false;
  uint16_t imuPeriodMsValue = 10;
  bool writeImuDynamic = false;
  bool imuDynamicValue = true;
  bool writeWifiTx = false;
  uint8_t wifiTxValue = 0;
  bool writeOtAxes = false;
  std::array<OtAxesEntry, 3> otAxesValue{};
  bool writeRgbBrightness = false;
  uint8_t rgbBrightnessValue = 25;
  bool writeLedMode = false;
  uint8_t ledModeValue = 0;
  bool writeLedR = false;
  uint8_t ledRValue = 80;
  bool writeLedG = false;
  uint8_t ledGValue = 140;
  bool writeLedB = false;
  uint8_t ledBValue = 255;
  bool writeBuzzerVolume = false;
  uint8_t buzzerVolumeValue = 25;
  bool writeBatteryCapacityMah = false;
  uint16_t batteryCapacityMahValue = 800;
  bool writeBatteryCalOffsetMv = false;
  int32_t batteryCalOffsetMvValue = 0;
  bool batteryCalibrateRequested = false;
  bool batteryCalibrateAllowed = false;
  bool writeHostname = false;
  std::string hostnameValue;

  bool wifiCredChanged = false;
  bool rebootRequired = false;
};

ConfigApplyPlan buildConfigApplyPlan(const ConfigPlanInput& in);

}  // namespace azimuth_cfg

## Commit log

2026-03-22 Initial commit: ESP32-C3 BNO08x head tracking firmware
    - PlatformIO firmware for Seeed XIAO ESP32-C3 + BNO08x (SPI)
    - Debug and Hatire (OpenTrack) build targets
    - Wiring documentation for XIAO ↔ BNO08x
    Made-with: Cursor
2026-03-22 Added kicad files for custom PCB (WIP)
    [ESP32_BNO086.kicad_pcb, ESP32_BNO086.kicad_sch]
2026-03-22 Added kicad libs, 3d models + updated paths
    [ESP32_BNO086.kicad_pcb, JS102011SAQN.STEP, S2B-PH-SM4-TB.STEP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]
2026-03-22 wiring changes
    [ESP32_BNO086.kicad_pcb, ESP32_BNO086.kicad_sch]
2026-03-23 Updated PCB design
    [ESP32_BNO086.kicad_pcb, ESP32_BNO086.kicad_sch]
2026-03-23 PCB tweaks again
    [ESP32_BNO086.kicad_pcb]
2026-03-23 Created V1 gerber files and BOM, still WIP
    [ESP32_BNO086-B_Cu.gbr, ESP32_BNO086-B_Mask.gbr, ESP32_BNO086-B_Paste.gbr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]
2026-03-24 pcb updates, doc updates, lib updates
    [ESP32_BNO086-B_Cu.gbr, ESP32_BNO086-B_Mask.gbr, ESP32_BNO086-B_Paste.gbr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]
2026-03-26 Logo added, doc updates, board tweaks, imgs
    [ESP32_BNO086.kicad_pcb]
2026-03-27 mapping fixes, readme update
    [main.cpp]
2026-03-28 battery added to parts list
2026-03-29 okay redoing the whole PCB, yes I am insane
    [Azimuth.kicad_pcb, Azimuth.kicad_sch]
2026-03-30 new offical azimuth PCB design started, big doc updates
    [Azimuth.kicad_sch]
2026-03-30 schematic fixes
    [Azimuth.kicad_sch]
2026-03-30 big docs refinement
    [Azimuth.kicad_sch]
2026-04-03 new PCB design almost done, big doc update
    [Azimuth.kicad_pcb, Azimuth.kicad_sch]
2026-04-05 PCB locked in for now, docs updated
    [Azimuth.kicad_pcb, Azimuth.kicad_sch]
2026-04-07 PCB finalized? :O
    [Azimuth.kicad_pcb, Azimuth.kicad_sch, Azimuth_PANEL.kicad_pcb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]
2026-04-08 Doc cleanup, BOM update
    [Azimuth_bom.csv]
2026-04-08 Manufacturing optimizations
    [Azimuth.kicad_pcb, Azimuth.kicad_sch, Azimuth_PANEL.kicad_pcb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]
2026-04-18 PCB V0.1 ordered!
    [Azimuth_PANEL.kicad_pcb]
2026-05-01 Boards came in! new flashing option in web UI
    [Azimuth.kicad_pcb]
2026-05-02 0.2.0 Update
    Built out IO for custom PCB, testing underway. All signs point to green!! Batteries coming in soon
2026-05-02 RGB LED FIX
2026-05-02 actual RGB LED fix
    [Azimuth.kicad_sch]
2026-05-02 LED brightness, buzzer volume controls
    [io_buzzer.cpp, io_led.cpp]
2026-05-05 thermal safety, status widgets
    [AzimuthLogo_Dark.dxf, AzimuthLogo_dxf_SIMPLE.dxf]
2026-05-07 LED controls, integrations, pause functionality, low power mode
2026-05-09 ui fixes, pose visualizer
    [io_led.cpp, main.cpp, track_config_plan.h]
2026-05-10 wireless updates
2026-05-10 wireless update changes
2026-05-10 Wireless update system done
2026-05-10 enclosure add
2026-05-10 Logo fix
    [AzimuthLogo.dxf, AzimuthLogo_Dark.dxf, AzimuthLogo_dxf_SIMPLE.dxf]
2026-05-10 Oops, fixed the logo
    [AzimuthLogo.dxf]

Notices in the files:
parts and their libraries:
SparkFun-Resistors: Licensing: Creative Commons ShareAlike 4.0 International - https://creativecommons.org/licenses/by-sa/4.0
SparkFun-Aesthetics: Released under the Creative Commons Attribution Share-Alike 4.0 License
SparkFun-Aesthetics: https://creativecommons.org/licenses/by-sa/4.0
